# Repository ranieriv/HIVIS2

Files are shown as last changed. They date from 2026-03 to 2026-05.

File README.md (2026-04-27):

# HIVIS Monitor 2.0

Self-hosted indoor air quality and acoustic monitoring system built on ESP32. Designed for schools, offices, and research environments where privacy and data ownership matter.

**Live dashboard:** [https://hvht.net](https://hvht.net)

---

## What it measures

| Metric | Sensor | Notes |
|---|---|---|
| IAQ (Air Quality Index) | BME688 + BSEC2 | 0–500 scale, accuracy 0–3 |
| CO₂ equivalent | BME688 + BSEC2 | ppm |
| VOC (breath VOC) | BME688 + BSEC2 | ppm |
| Temperature | BME688 | °C |
| Humidity | BME688 | % RH |
| Noise level | INMP441 | dB SPL |
| Battery voltage | ADC (GPIO 36) | % + volts |

---

## Architecture

```
┌─────────────────────────────────────────────────────┐
│  ESP32 Device (battery-powered)                     │
│  BME688 · INMP441 · OLED · Button · Buzzer          │
└──────────────────┬──────────────────────────────────┘
                   │ MQTT TLS :8883 · HTTP :8090 (OTA)
                   ▼
┌─────────────────────────────────────────────────────┐
│  Server (Docker)                                    │
│  Mosquitto → Node-RED → InfluxDB → Grafana          │
│  Nginx (https://hvht.net) · OTA server (:8090)      │
└─────────────────────────────────────────────────────┘
```

---

## Hardware

| Component | Part |
|---|---|
| MCU | ESP32 DOIT DevKit V1 |
| Air quality | Bosch BME688 breakout |
| Microphone | INMP441 I2S breakout |
| Display | 0.96" OLED SSD1306 (I2C) |
| Button | Tactile switch (GPIO 4) |
| Buzzer | Passive piezo (GPIO 25) |
| Power | 1S LiPo + USB-C charging module |

KiCad schematic, PCB layout, Gerber files, and BOM are in [`hardware/`](hardware/).

### GPIO Map

| GPIO | Function |
|---|---|
| 21 | I2C SDA (BME688 + OLED) |
| 22 | I2C SCL (BME688 + OLED) |
| 12 | I2S WS — microphone |
| 13 | I2S LR — microphone channel select |
| 14 | I2S SCK — microphone |
| 26 | I2S SD — microphone data |
| 4  | Button (INPUT_PULLUP, active LOW) |
| 25 | Buzzer (LEDC PWM) |
| 36 | Battery ADC (voltage divider ×2.2) |

---

## Firmware

Built with PlatformIO (Arduino framework).

**Dependencies** (auto-installed via `platformio.ini`):
- `boschsensortec/bsec2` — IAQ/CO₂/VOC
- `olikraus/U8g2` — OLED display
- `bblanchon/ArduinoJson`
- `knolleary/PubSubClient` — MQTT
- `tzapu/WiFiManager` — captive portal provisioning

**Build and flash:**
```bash
# Install PlatformIO CLI or use the VS Code extension
pio run --target upload

# Upload LittleFS (config.json, bsec_state.bin)
pio run --target uploadfs
```

**First boot:** the device launches a captive portal (`HIVIS-Setup-XXXX`). Connect and enter your WiFi credentials and MQTT server address.

Device configuration lives in [`data/config.json`](data/config.json). All pin assignments and thresholds are overridable there without reflashing.

---

## Server

The full server stack runs on Docker. A single Linux machine is enough (tested on a Lenovo ThinkPad X200 with Ubuntu).

**Services:**

| Container | Purpose | Port |
|---|---|---|
| `hivis-mosquitto` | MQTT broker (TLS) | 8883 |
| `hivis-nodered` | Data routing + device provisioning | 1880 |
| `hivis-influxdb` | Time-series storage | 8086 |
| `hivis-grafana` | Dashboards | 3000 |
| `hivis-ota` | Firmware update server | 8090 |
| `hivis-nginx` | Public HTTPS dashboard | 80, 443 |
| `hivis-certbot` | Let's Encrypt auto-renewal | — |

**Deploy:**
```bash
cd server
cp mosquitto/config/passwd.example mosquitto/config/passwd  # create credentials
docker compose up -d
```

See [`docs/system-overview.md`](docs/system-overview.md) for the full setup and [`docs/operations-manual.md`](docs/operations-manual.md) for day-to-day operations.

---

## Button functions

| Press | Duration | Action |
|---|---|---|
| Short | < 400 ms | Next display page |
| Double | 2× within 400 ms | Stop alert buzzer |
| Long | 2–5 s | Launch reconfigure portal |
| Factory reset | > 5 s | Wipe NVS credentials and reboot |

---

## Documentation

| File | Contents |
|---|---|
| [`docs/system-overview.md`](docs/system-overview.md) | Architecture, pin map, boot sequence, MQTT topics, server stack |
| [`docs/operations-manual.md`](docs/operations-manual.md) | Quick checks, troubleshooting, deploying firmware, adding devices |
| [`spec/01_device_firmware.md`](spec/01_device_firmware.md) | Firmware module details |
| [`spec/02_provisioning.md`](spec/02_provisioning.md) | First-boot captive portal and MQTT registration flow |
| [`spec/03_ota.md`](spec/03_ota.md) | OTA update system |
| [`spec/04_mqtt_data.md`](spec/04_mqtt_data.md) | MQTT topics and JSON payload schema |
| [`spec/05_server_infrastructure.md`](spec/05_server_infrastructure.md) | Docker stack and Mosquitto ACL |
| [`spec/06_grafana_dashboards.md`](spec/06_grafana_dashboards.md) | Dashboard definitions |

---

## Project structure

```
hivis2/
├── src/            # ESP32 firmware (C++/Arduino)
├── data/           # LittleFS filesystem (config.json)
├── hardware/       # KiCad schematic, PCB, Gerbers, BOM
├── server/         # Docker stack, Mosquitto, Node-RED, Grafana, Nginx
├── docs/           # Operations manual + system overview
├── spec/           # Detailed technical specifications
├── partitions.csv  # ESP32 flash partition table
└── platformio.ini  # Build configuration
```

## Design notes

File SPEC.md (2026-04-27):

# HIVIS Monitor 2.0 — Master Specification

**Version:** 2.0.0  
**Date:** 2026-03-13  
**Author:** Rani  
**Supervisor:** Aaron  
**Institution:** Saskatchewan Polytechnic  
**Showcase:** Applied Research Student Showcase 2026 — May 4, Prairieland Park, Saskatoon

---

## Project Overview

HIVIS Monitor 2.0 is a multi-device, self-hosted indoor air quality and acoustic monitoring system. It is a privacy-respecting alternative to commercial IoT monitors, targeting schools, offices, healthcare, and industrial facilities.

The system consists of:
- One or more ESP32-based sensor devices
- A self-hosted server stack (Lenovo ThinkPad X200, Ubuntu Server)
- A Grafana dashboard accessible via `hvht.net`

The target scale is **up to 10 devices**. The showcase demonstration uses **3 devices**.

---

## Module Spec Files

| File | Contents |
|---|---|
| `spec/01_device_firmware.md` | ESP32 firmware — boot flow, sensors, display, button, buzzer, offline buffering |
| `spec/02_provisioning.md` | First-boot captive portal, NVS credential storage, device registration |
| `spec/03_ota.md` | OTA firmware update system — device polling, server approval, HTTP delivery |
| `spec/04_mqtt_data.md` | MQTT topic structure, payload format, offline backfill |
| `spec/05_server_infrastructure.md` | Docker stack — Mosquitto, Node-RED, InfluxDB 2.x, Grafana |
| `spec/06_grafana_dashboards.md` | Dashboard definitions — per-device, fleet overview, historical |

---

## System Architecture

```
[ESP32 Device(s)]
       │
       │  MQTT over TLS (port 8883)
       ▼
[Mosquitto Broker]  ←── mqtt.hvht.net (DNS-only, no Cloudflare proxy)
       │
       │  Subscribe all hivis/#
       ▼
[Node-RED]  ──────────────────────────────────────────────┐
       │                                                   │
       │  node-red-contrib-influxdb                        │  Device registration
       ▼                                                   │  MAC whitelist check
[InfluxDB 2.x]  (bucket: hivis)                           │  MQTT credential provisioning
       │                                                   │
       ▼
[Grafana]  ──── dashboard.hvht.net (port 3000)
```

All services run in **Docker** on the X200 (`mqttserver`), managed by a single `docker-compose.yml`.

---

## Technology Stack

### Device (ESP32)
| Component | Library / Tool |
|---|---|
| Framework | Arduino (PlatformIO) |
| Sensor (IAQ) | Bosch BSEC2 + BME68x |
| Display | U8g2 |
| JSON | ArduinoJson |
| MQTT | PubSubClient |
| WiFi provisioning | WiFiManager (tzapu) |
| NVS credentials | ESP32 Preferences API |
| OTA update | ESP32 HTTPUpdate (built-in) |
| Offline storage | LittleFS |
| Filesystem | LittleFS |

### Server
| Service | Image |
|---|---|
| MQTT Broker | eclipse-mosquitto:latest |
| Flow engine | nodered/node-red:latest |
| Time-series DB | influxdb:2 |
| Dashboards | grafana/grafana:latest |
| OTA HTTP server | Python `http.server` (simple container or host) |

---

## Network & Access

| Endpoint | Address | Notes |
|---|---|---|
| MQTT (TLS) | `mqtt.hvht.net:8883` | DNS-only Cloudflare, existing cert |
| Grafana | `dashboard.hvht.net:3000` | Tailscale or direct LAN |
| InfluxDB UI | `mqttserver:8086` | LAN only |
| Node-RED UI | `mqttserver:1880` | LAN only |
| OTA server | `mqttserver:8090` | LAN + Tailscale |
| Local IP | `&lt;SERVER_IP&gt;` | X200 static LAN IP |
| Tailscale IP | `&lt;TAILSCALE_IP&gt;` | Remote access |

---

## Device Hardware

| Component | Part | Notes |
|---|---|---|
| MCU | ESP32 DoIt DevKit V1 | Or equivalent 4MB flash module |
| Air quality | Bosch BME688 | I2C, addr 0x77 (119) |
| Microphone | INMP441 | I2S |
| Display | SSD1306 0.96" OLED (or 1.3") | I2C, 128×64 |
| Button | 1× tactile button | GPIO, active LOW |
| Buzzer | Passive piezo + 100Ω resistor | PWM via LEDC |
| Battery | 18650 Li-ion or LiPo | Single cell |
| Charger/Boost | J5019 | 5V regulated output |
| Battery monitor | Voltage divider → GPIO 36 | Taps raw cell voltage |

**Custom PCB:** Targeted for JLCPCB fabrication. Schematic and layout are outside this spec scope.

**Partition table:** A custom `partitions.csv` is required to fit OTA (dual app partitions) + LittleFS on 4MB flash:

```csv
# Name,   Type, SubType, Offset,   Size,    Flags
nvs,      data, nvs,     0x9000,   0x5000,
otadata,  data, ota,     0xe000,   0x2000,
app0,     app,  ota_0,   0x10000,  0x1C0000,
app1,     app,  ota_1,   ,         0x1C0000,
spiffs,   data, spiffs,  ,         0x3F0000,
```

---

## Security Model

| Concern | Approach |
|---|---|
| MQTT transport | TLS (port 8883), `setInsecure()` initially, CA pinning future upgrade |
| Credentials on device | ESP32 NVS (Preferences API), not files |
| Device authorization | MAC address whitelist on server |
| MQTT credentials | Server-provisioned after MAC auth, not user-entered |
| OTA authenticity | Per-device approval flag on server before binary is served |
| Config (non-secret) | Plain-text `config.json` in LittleFS |

---

## Versioning

Firmware uses semantic versioning: `MAJOR.MINOR.PATCH` (e.g. `2.0.0`).  
Version string is defined as a build flag in `platformio.ini`:

```ini
build_flags = -DFIRMWARE_VERSION='"2.0.0"'
```

---

## Key Design Decisions & Rationale

- **NVS over encrypted file:** NVS is hardware-backed, cleaner, and integrates naturally with WiFiManager. SecureVault (AES-128 CBC) from v1 is removed.
- **WiFiManager (tzapu):** Handles captive portal, custom parameters, and NVS storage natively with PlatformIO.
- **Docker for server:** Portability, clean separation of services, easy migration to new hardware.
- **InfluxDB 2.x + Grafana:** Industry standard for IoT time-series. Replaces Node-RED dashboard.
- **Node-RED retained:** Acts as routing glue between MQTT and InfluxDB. Handles device registration logic. Replaceable with Telegraf later if needed.
- **Offline backfill:** Same MQTT topic, `ts_accurate: false` flag, approximate timestamps spaced backwards from reconnect time.
- **1 button:** Short press / long press / double press covers all UI needs.
- **Passive piezo:** Tone control for distinct alert levels.
- **No DS3231 RTC:** Keeps form factor small. Offline timestamps are approximate and flagged.
- **OTA polling:** Device polls on every boot + every 24h. Server has per-device `ota_approved` flag.
- **Group field:** Present in data model from day one. UI support deferred.

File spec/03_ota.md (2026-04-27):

# Module 03 — OTA Firmware Update System

## Overview

Devices poll an HTTP server for firmware updates. The server controls which devices receive an update via a per-device approval flag. Devices never update without server authorization.

---

## OTA Flow

```
Device boots
  → Check NVS: time since last OTA check > otaCheckIntervalH (or first boot)
  → GET http://[ota_server]/ota/version?mac=[device_mac]
  → Server checks:
      - Is this MAC in the whitelist?
      - Is ota_approved = true for this device?
      - Is server version > device FIRMWARE_VERSION?
  → If yes: respond with latest version string
  → Device compares: server_version > FIRMWARE_VERSION?
  → If yes: display "Updating firmware..." on OLED, perform HTTPUpdate
  → On success: reboot into new firmware
  → On failure: log error, continue with current firmware
  → Update NVS ota_last_check timestamp
```

### Check Interval

- On every boot (cold start)
- Every `cfg.otaCheckIntervalH` hours during operation (default 24h)
- Checked via `millis()` comparison against stored `ota_last_check` offset

---

## OTAModule

```cpp
class OTAModule {
public:
    OTAModule(const String& serverUrl, const String& deviceId,
              const String& mac, const String& currentVersion);
    void begin();

    // Call on boot and periodically
    // Returns: true if update was applied (device will reboot)
    bool checkAndUpdate();

private:
    String _serverUrl;  // e.g. "http://<SERVER_IP>:8090"
    String _deviceId;
    String _mac;
    String _currentVersion;

    bool _shouldCheck();
    void _saveLastCheckTime();
};
```

### HTTPUpdate Usage

```cpp
#include <HTTPUpdate.h>

WiFiClient client;
String url = _serverUrl + "/ota/firmware?mac=" + _mac;

httpUpdate.setLedPin(LED_BUILTIN, LOW);
t_httpUpdate_return ret = httpUpdate.update(client, url, _currentVersion);

switch (ret) {
    case HTTP_UPDATE_FAILED:
        Serial.printf("OTA failed: %s\n", httpUpdate.getLastErrorString().c_str());
        break;
    case HTTP_UPDATE_NO_UPDATES:
        Serial.println("OTA: firmware is up to date.");
        break;
    case HTTP_UPDATE_OK:
        Serial.println("OTA: update applied, rebooting.");
        // Device reboots automatically
        break;
}
```

The ESP32 HTTPUpdate library sends the following headers automatically:
- `x-ESP32-STA-MAC` — device MAC (used by server for per-device approval)
- `x-ESP32-free-space` — available flash
- `x-ESP32-sketch-size` — current firmware size

---

## OTA Server

A lightweight Python HTTP server running in Docker (or as a systemd service) on the X200.

### Directory Structure

```
/opt/hivis/ota/
  server.py           ← HTTP server
  firmware/
    latest.bin        ← Current approved firmware binary
    version.txt       ← Current version string, e.g. "2.0.1"
  devices.json        ← Per-device approval flags
```

### devices.json

```json
{
  "devices": {
    "aabbccddeeff": {
      "ota_approved": true,
      "notes": "Classroom unit 1"
    },
    "112233445566": {
      "ota_approved": false,
      "notes": "Test device — not yet approved"
    }
  }
}
```

Setting `ota_approved: true` for a device means it will receive the update on its next check. After a successful update, the operator should set it back to `false` (or leave it `true` for auto-updates — operator's choice).

### server.py — Endpoints

**GET `/ota/version?mac=[mac]`**

Checks whitelist + approval flag. Returns version string or 304.

Response if update available:
```
HTTP 200
Content-Type: text/plain
Body: 2.0.1
```

Response if not approved or up to date:
```
HTTP 304 Not Modified
```

**GET `/ota/firmware?mac=[mac]`**

Validates MAC header from ESP32 HTTPUpdate. If approved, serves `firmware/latest.bin`.

```python
# server.py pseudocode
from http.server import BaseHTTPRequestHandler, HTTPServer
import json, os

DEVICES_FILE = "devices.json"
FIRMWARE_FILE = "firmware/latest.bin"
VERSION_FILE = "firmware/version.txt"

class OTAHandler(BaseHTTPRequestHandler):
    def do_GET(self):
        mac = self._get_mac()
        if not self._is_approved(mac):
            self.send_response(304)
            self.end_headers()
            return

        if self.path.startswith("/ota/version"):
            version = open(VERSION_FILE).read().strip()
            self.send_response(200)
            self.send_header("Content-Type", "text/plain")
            self.end_headers()
            self.wfile.write(version.encode())

        elif self.path.startswith("/ota/firmware"):
            data = open(FIRMWARE_FILE, "rb").read()
            self.send_response(200)
            self.send_header("Content-Type", "application/octet-stream")
            self.send_header("Content-Length", str(len(data)))
            self.end_headers()
            self.wfile.write(data)

    def _get_mac(self):
        # From URL param or ESP32 header
        mac = self.headers.get("x-ESP32-STA-MAC", "").lower().replace(":", "")
        if not mac:
            from urllib.parse import urlparse, parse_qs
            params = parse_qs(urlparse(self.path).query)
            mac = params.get("mac", [""])[0].replace(":", "").lower()
        return mac

    def _is_approved(self, mac):
        with open(DEVICES_FILE) as f:
            data = json.load(f)
        device = data.get("devices", {}).get(mac, {})
        return device.get("ota_approved", False)
```

### Docker Service

```yaml
# In docker-compose.yml
ota-server:
  image: python:3.11-slim
  container_name: hivis-ota
  working_dir: /app
  volumes:
    - /opt/hivis/ota:/app
  command: python server.py
  ports:
    - "8090:8090"
  restart: unless-stopped
```

---

## Deployment Workflow

```
1. Build new firmware in PlatformIO → .pio/build/esp32doit-devkit-v1/firmware.bin
2. Manually flash test device via USB
3. Validate — confirm new version appears on serial / display
4. Copy firmware.bin to /opt/hivis/ota/firmware/latest.bin on server
5. Update /opt/hivis/ota/firmware/version.txt to new version string
6. Edit devices.json: set ota_approved = true for test device
7. Device polls → downloads → reboots → confirm correct version
8. Set ota_approved = true for production devices
9. Devices update on next check (boot or 24h interval)
```

---

## Partition Table Requirement

OTA requires dual app partitions. Use this `partitions.csv` in the project root:

```csv
# Name,   Type, SubType, Offset,   Size,     Flags
nvs,      data, nvs,     0x9000,   0x5000,
otadata,  data, ota,     0xe000,   0x2000,
app0,     app,  ota_0,   0x10000,  0x1C0000,
app1,     app,  ota_1,   ,         0x1C0000,
spiffs,   data, spiffs,  ,         0x3F0000,
```

Reference in `platformio.ini`:
```ini
board_build.partitions = partitions.csv
```

**Note:** The `app0` + `app1` partitions are each 1.75MB. Total firmware binary must stay under 1.75MB. Monitor with `pio run` output. The BSEC library is large — if binary exceeds limit, reduce LittleFS size or optimize.

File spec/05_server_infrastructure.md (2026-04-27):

# Module 05 — Server Infrastructure

## Overview

All server services run in Docker on the Lenovo ThinkPad X200 (`mqttserver`).  
A single `docker-compose.yml` defines the entire stack.

**Host:** Ubuntu Server, 4GB RAM  
**Static LAN IP:** `<SERVER_IP>`  
**Tailscale IP:** `<TAILSCALE_IP>`  
**External domain:** `mqtt.hvht.net` (Cloudflare DNS-only, no proxy)

---

## Services

| Service | Container | Port (host) | Purpose |
|---|---|---|---|
| Mosquitto | `hivis-mosquitto` | 8883 | MQTT broker (TLS) |
| Node-RED | `hivis-nodered` | 1880 | MQTT → InfluxDB routing + registration |
| InfluxDB 2.x | `hivis-influxdb` | 8086 | Time-series storage |
| Grafana | `hivis-grafana` | 3000 | Dashboards (LAN only) |
| OTA Server | `hivis-ota` | 8090 | Firmware delivery |
| Nginx | `hivis-nginx` | 80, 443 | Public website (https://hvht.net) + InfluxDB proxy |
| Certbot | `hivis-certbot` | — | Let's Encrypt SSL cert auto-renewal |

---

## docker-compose.yml

```yaml
version: "3.8"

services:

  mosquitto:
    image: eclipse-mosquitto:latest
    container_name: hivis-mosquitto
    restart: unless-stopped
    ports:
      - "8883:8883"
    volumes:
      - ./mosquitto/config:/mosquitto/config
      - ./mosquitto/data:/mosquitto/data
      - ./mosquitto/log:/mosquitto/log
      - ./mosquitto/certs:/mosquitto/certs
    networks:
      - hivis-net

  nodered:
    image: nodered/node-red:latest
    container_name: hivis-nodered
    restart: unless-stopped
    ports:
      - "1880:1880"
    volumes:
      - nodered-data:/data
    depends_on:
      - mosquitto
      - influxdb
    environment:
      - TZ=America/Regina
    networks:
      - hivis-net

  influxdb:
    image: influxdb:2
    container_name: hivis-influxdb
    restart: unless-stopped
    ports:
      - "8086:8086"
    volumes:
      - influxdb-data:/var/lib/influxdb2
      - influxdb-config:/etc/influxdb2
    environment:
      - DOCKER_INFLUXDB_INIT_MODE=setup
      - DOCKER_INFLUXDB_INIT_USERNAME=admin
      - DOCKER_INFLUXDB_INIT_PASSWORD=REPLACE_WITH_SECURE_PASSWORD
      - DOCKER_INFLUXDB_INIT_ORG=hivis
      - DOCKER_INFLUXDB_INIT_BUCKET=hivis
      - DOCKER_INFLUXDB_INIT_ADMIN_TOKEN=REPLACE_WITH_GENERATED_TOKEN
    networks:
      - hivis-net

  grafana:
    image: grafana/grafana:latest
    container_name: hivis-grafana
    restart: unless-stopped
    ports:
      - "3000:3000"
    volumes:
      - grafana-data:/var/lib/grafana
      - ./grafana/provisioning:/etc/grafana/provisioning
    environment:
      - GF_SECURITY_ADMIN_PASSWORD=REPLACE_WITH_SECURE_PASSWORD
      - GF_USERS_ALLOW_SIGN_UP=false
    depends_on:
      - influxdb
    networks:
      - hivis-net

  ota-server:
    image: python:3.11-slim
    container_name: hivis-ota
    restart: unless-stopped
    working_dir: /app
    volumes:
      - /opt/hivis/ota:/app
    command: python server.py
    ports:
      - "8090:8090"
    networks:
      - hivis-net

  nginx:
    image: nginx:alpine
    container_name: hivis-nginx
    restart: unless-stopped
    ports:
      - "80:80"
      - "443:443"
    volumes:
      - ./website:/usr/share/nginx/html:ro
      - ./nginx:/etc/nginx/conf.d:ro
      - certbot-conf:/etc/letsencrypt:ro
      - certbot-www:/var/www/certbot:ro
    depends_on:
      - influxdb
    networks:
      - hivis-net

  certbot:
    image: certbot/certbot:latest
    container_name: hivis-certbot
    restart: unless-stopped
    volumes:
      - certbot-conf:/etc/letsencrypt
      - certbot-www:/var/www/certbot
    entrypoint: "/bin/sh -c 'trap exit TERM; while :; do certbot renew --quiet; sleep 12h & wait $${!}; done;'"
    networks:
      - hivis-net

networks:
  hivis-net:
    driver: bridge

volumes:
  nodered-data:
  influxdb-data:
  influxdb-config:
  grafana-data:
  certbot-conf:
  certbot-www:
```

**Important:** Replace all `REPLACE_WITH_*` placeholders before deploying. See `docs/credentials.md` for the running deployment's values.

---

## Mosquitto Configuration

File: `./mosquitto/config/mosquitto.conf`

```conf
listener 8883
protocol mqtt

# TLS
cafile /mosquitto/certs/ca.crt
certfile /mosquitto/certs/server.crt
keyfile /mosquitto/certs/server.key
require_certificate false

# Auth
allow_anonymous false
password_file /mosquitto/config/passwd
acl_file /mosquitto/config/acl

# Persistence
persistence true
persistence_location /mosquitto/data/

# Logging
log_dest file /mosquitto/log/mosquitto.log
log_type error
log_type warning
log_type notice
```

**TLS certs:** Existing self-signed cert for `mqtt.hvht.net` (already in use in v1). Mount into container at `/mosquitto/certs/`.

**Password file:** Managed with `mosquitto_passwd`. Each device gets its own user. Node-RED gets a `nodered_bridge` user with full access.

```bash
# Create password file inside container
docker exec -it hivis-mosquitto mosquitto_passwd -c /mosquitto/config/passwd nodered_bridge
docker exec -it hivis-mosquitto mosquitto_passwd /mosquitto/config/passwd device_aabbccddeeff
```

**ACL file:** `./mosquitto/config/acl` — see Module 04 for content.

---

## Node-RED Flows

Install required nodes in Node-RED:
```
node-red-contrib-influxdb
```

### Flow 1: Sensor Data → InfluxDB

```
[MQTT in: hivis/+/data]
  → [JSON parse]
  → [Function: build InfluxDB point]
  → [InfluxDB out: hivis bucket]
```

InfluxDB point builder function:
```javascript
const payload = msg.payload;
const isBackfill = payload.backfill === true;

// Use payload timestamp if backfill, otherwise now
const timestamp = isBackfill && payload.ts > 0
    ? new Date(payload.ts * 1000)
    : new Date();

msg.payload = [
    {
        measurement: "air_quality",
        tags: {
            device_id:   payload.device_id,
            device_name: payload.device_name,
            group:       payload.group || "default",
            backfill:    String(isBackfill)
        },
        fields: {
            temp:     payload.temp,
            hum:      payload.hum,
            iaq:      payload.iaq,
            co2:      payload.co2,
            bvoc:     payload.bvoc,
            db:       payload.db,
            bat_pct:  payload.bat_pct,
            bat_mv:   payload.bat_mv,
            rssi:     payload.rssi,
            accuracy: payload.accuracy
        },
        timestamp: timestamp
    }
];

return msg;
```

### Flow 2: Device Registration

```
[MQTT in: hivis/register]
  → [JSON parse]
  → [Function: check whitelist]
  → [Branch: approved / rejected]
  → (approved) [Function: generate credentials]
               [MQTT out: hivis/provision/[mac]]
               [File: update devices.json]
  → (rejected) [MQTT out: hivis/provision/[mac]] (rejected payload)
```

Whitelist check function:
```javascript
const reg = msg.payload;
const mac = reg.mac.toLowerCase().replace(/:/g, "");
const fs = require("fs");
const whitelist = JSON.parse(fs.readFileSync("/data/whitelist.json", "utf8"));

const device = whitelist.devices.find(d =>
    d.mac.toLowerCase().replace(/:/g, "") === mac
);

if (device && device.authorized) {
    msg.approved = true;
    msg.mac = mac;
    msg.device_name = reg.device_name;
} else {
    msg.approved = false;
    msg.mac = mac;
}
return msg;
```

Credential generation function:
```javascript
// Generate a secure random password
const chars = "ABCDEFGHIJKLMNOPQRSTUVWXYZabcdefghijklmnopqrstuvwxyz0123456789";
let pass = "";
for (let i = 0; i < 20; i++) {
    pass += chars[Math.floor(Math.random() * chars.length)];
}

const user = "device_" + msg.mac;
const deviceId = "hivis-" + msg.mac;

msg.topic = "hivis/provision/" + msg.mac;
msg.payload = JSON.stringify({
    status: "approved",
    mqtt_user: user,
    mqtt_pass: pass,
    device_id: deviceId
});
msg.retain = true;

// Store credentials for reference (Node-RED context or file)
// Operator must also add user to Mosquitto passwd manually or via exec node
return msg;
```

**Note:** Automatically adding users to Mosquitto's passwd file from Node-RED requires a shell `exec` node running `mosquitto_passwd`. This is acceptable for a managed deployment. The operator can also do this step manually.

### Flow 3: System Status

```
[MQTT in: hivis/+/data]
  → [Function: extract system fields]
  → [InfluxDB out: hivis bucket, measurement: "device_status"]
```

System fields to track separately: `bat_pct`, `bat_mv`, `rssi`, `accuracy`, `fw_version`.

---

## InfluxDB 2.x

**Organization:** `hivis`  
**Bucket:** `hivis`  
**Retention:** Unlimited (or set 90 days for auto-cleanup)

Measurements:
- `air_quality` — all sensor readings
- `device_status` — system fields (battery, RSSI, accuracy)

Tags on all measurements:
- `device_id`
- `device_name`
- `group`
- `backfill`

---

## File Structure on Host

```
/opt/hivis/
  docker-compose.yml
  mosquitto/
    config/
      mosquitto.conf
      passwd
      acl
    certs/
      ca.crt           ← existing cert
      server.crt       ← existing cert
      server.key       ← existing key
    data/
    log/
  grafana/
    provisioning/
      datasources/
        influxdb.yml
  ota/
    server.py
    firmware/
      latest.bin
      version.txt
    devices.json
  server/
    whitelist.json
```

---

## Grafana Data Source Provisioning

File: `./grafana/provisioning/datasources/influxdb.yml`

```yaml
apiVersion: 1

datasources:
  - name: InfluxDB-hivis
    type: influxdb
    access: proxy
    url: http://influxdb:8086
    jsonData:
      version: Flux
      organization: hivis
      defaultBucket: hivis
      tlsSkipVerify: true
    secureJsonData:
      token: REPLACE_WITH_INFLUXDB_TOKEN
    isDefault: true
```

---

## Security Notes

- All services are on an internal Docker bridge network (`hivis-net`). Only ports listed are exposed to the host.
- **Internet-facing ports:** 80 (HTTP→redirect), 443 (HTTPS dashboard), 8883 (MQTT TLS for devices). All others are LAN only.
- Grafana (:3000) and Node-RED (:1880) must NOT be exposed to the internet — Node-RED allows arbitrary code execution.
- InfluxDB (:8086) is accessed by the website exclusively through the Nginx `/api/v2/query` proxy. The website uses a **read-only token** — the admin token is never exposed publicly.
- Mosquitto `passwd` file must be owned by root, permissions `644`. If sudo operations reset it to `rwx------`, Mosquitto will crash with exit code 13. Fix: `chmod 644` via a root Docker exec.
- The OTA server mounts the Docker socket (`/var/run/docker.sock`) to call `mosquitto_passwd` during provisioning — this gives it full Docker host control. Acceptable for this deployment; restrict in higher-security environments.
- Existing Tailscale + fail2ban setup on the X200 continues to apply.
- Replace all `REPLACE_WITH_*` placeholders and use unique passwords before deploying.

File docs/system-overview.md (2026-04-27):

# HIVIS Monitor 2.0 — System Documentation

**Version:** 2.0.2
**Hardware:** ESP32 DOIT DevKit V1 + BME688 + INMP441
**Server:** Lenovo ThinkPad X200 · Ubuntu · &lt;SERVER_IP&gt;
**Public website:** https://hvht.net

---

## 1. Architecture Overview

```
┌─────────────────────────────────────────────────────────────┐
│  ESP32 Device (Battery-powered, indoor)                     │
│  BME688 (IAQ/CO2/VOC/Temp/Hum) + INMP441 (Noise) + OLED   │
└──────────────────┬──────────────────────────────────────────┘
                   │ MQTT TLS :8883
                   │ HTTP     :8090 (OTA)
                   ▼
┌─────────────────────────────────────────────────────────────┐
│  Server — &lt;SERVER_IP&gt; / mqtt.hvht.net                      │
│  ┌──────────────┐  ┌──────────────┐  ┌──────────────────┐  │
│  │  Mosquitto   │  │   Node-RED   │  │    InfluxDB 2    │  │
│  │  :8883 TLS   │→ │  :1880       │→ │    :8086         │  │
│  └──────────────┘  └──────────────┘  └────────┬─────────┘  │
│  ┌──────────────┐                    ┌─────────▼─────────┐  │
│  │  OTA Server  │                    │    Grafana        │  │
│  │  :8090       │                    │    :3000          │  │
│  └──────────────┘                    └───────────────────┘  │
│  ┌──────────────────────────────────────────────────────┐   │
│  │  Nginx (HTTPS :443 / HTTP :80 → redirect)            │   │
│  │  Serves https://hvht.net — static dashboard +        │   │
│  │  proxies /api/v2/query → InfluxDB (internal only)    │   │
│  └──────────────────────────────────────────────────────┘   │
└─────────────────────────────────────────────────────────────┘
                   ▲
                   │ HTTPS :443
         Browser (any network) — https://hvht.net
```

---

## 2. Server Stack

| Service | Image | Port | Purpose |
|---|---|---|---|
| `hivis-mosquitto` | eclipse-mosquitto:latest | **8883** | MQTT broker (TLS only) |
| `hivis-nodered` | nodered/node-red:latest | **1880** | Data routing & provisioning |
| `hivis-influxdb` | influxdb:2 | **8086** | Time-series database |
| `hivis-grafana` | grafana/grafana:latest | **3000** | Dashboards (LAN only) |
| `hivis-ota` | python:3.11-slim | **8090** | Firmware update server |
| `hivis-nginx` | nginx:alpine | **80, 443** | Public website (https://hvht.net) + InfluxDB proxy |
| `hivis-certbot` | certbot/certbot:latest | — | Let's Encrypt cert auto-renewal (12h loop) |

**Manage all services:**
```bash
cd /opt/hivis
docker compose ps           # status
docker compose restart      # restart all
docker compose logs -f      # live logs
```

---

## 3. Device Boot Sequence

```
1. Load config.json from LittleFS
2. Init hardware (I2C 21/22, OLED, buzzer, button)
3. Show splash, load NVS credentials
4. If no WiFi/server saved → Captive portal (HIVIS-Setup-XXXX)
5. Init BME688 (I2C 0x77) + INMP441 microphone
6. Connect WiFi (15s timeout)
7. Sync NTP (pool.ntp.org / time.nist.gov)
8. If not provisioned → Register via MQTT bootstrap
9. Connect MQTT with provisioned credentials
10. Flush offline buffer (if any)
11. Check OTA (every 24h)
12. Main loop: read sensors → display → publish every 3s
```

---

## 4. Device Provisioning Flow

```
Device (unprovisioned)
  │ CONNECT  user=hivis_bootstrap  pass=<see credentials.md>
  ▼
Mosquitto ──→ Node-RED
  │              │ Check whitelist.json
  │              │ Generate random 20-char password
  │              │ Call POST http://ota-server:8090/provision
  │              │   └─ mosquitto_passwd -b passwd device_XXXX PASS
  │              │   └─ Append ACL entry
  │              │   └─ SIGHUP Mosquitto
  │              │ Publish to hivis/provision/[mac] (retain=true)
  ◄─────────────────────────────────────────────────────────
Device receives: {"status":"approved","mqtt_user":"device_XXXX",
                  "mqtt_pass":"...","device_id":"hivis-XXXX"}
  │ Save to NVS
  │ CONNECT  user=device_XXXX  pass=...
  ▼
Mosquitto: authenticated ✓
```

---

## 5. MQTT Topics

| Topic | Direction | Purpose |
|---|---|---|
| `hivis/hivis-[mac]/data` | Device → Server | Sensor data (3s interval) |
| `hivis/register` | Device → Server | Registration request |
| `hivis/provision/[mac]` | Server → Device | Provisioning response (retained) |

**Sensor payload (JSON):**
```json
{
  "device_id":   "hivis-4cc382c32764",
  "device_name": "Room 101",
  "ts":          1710518400,
  "ts_accurate": true,
  "fw_version":  "2.0.1",
  "temp":        22.5,
  "hum":         45.3,
  "iaq":         75.2,
  "co2":         412,
  "bvoc":        0.52,
  "db":          65.3,
  "bat_pct":     85,
  "bat_mv":      3850,
  "rssi":        -45,
  "accuracy":    3,
  "backfill":    false
}
```

**IAQ Accuracy (BSEC2):**
| Value | Meaning |
|---|---|
| 0 | Calibrating — values unreliable (~30 min on first boot) |
| 1 | Low accuracy |
| 2 | Medium accuracy |
| 3 | High accuracy — fully calibrated |

---

## 6. MQTT Users & Access Control

| User | Password | Access |
|---|---|---|
| `hivis_bootstrap` | *(see docs/credentials.md)* | Write hivis/register, Read hivis/provision/+ |
| `nodered_bridge` | *(encrypted in Node-RED)* | Read/Write hivis/# |
| `device_[mac]` | Auto-generated | Write hivis/hivis-[mac]/#, Read hivis/provision/[mac] |

**Add a new device to whitelist** (required before registration is approved):
```bash
# Whitelist lives inside the Node-RED container — edit it directly:
ssh mqttadmin@&lt;SERVER_IP&gt; "docker exec hivis-nodered nano /data/whitelist.json"
# Add to the "devices" array:
# { "mac": "AA:BB:CC:DD:EE:FF", "authorized": true, "group": "saskpoly", "notes": "Room X" }
```

---

## 7. OTA Update Process

**OTA server endpoints:**
```
GET  http://mqtt.hvht.net:8090/ota/version?mac=[mac]   → "2.0.1"
GET  http://mqtt.hvht.net:8090/ota/firmware?mac=[mac]  → latest.bin
POST http://ota-server:8090/provision                  → Add Mosquitto user
```

**Deploy a new firmware version:**
```bash
# 1. Bump version in platformio.ini: -DFIRMWARE_VERSION='"2.0.2"'
# 2. Build:
pio run
# 3. Upload binary:
scp .pio/build/esp32doit-devkit-v1/firmware.bin mqttadmin@&lt;SERVER_IP&gt;:/opt/hivis/ota/firmware/latest.bin
# 4. Update version file:
ssh mqttadmin@&lt;SERVER_IP&gt; "echo '2.0.2' > /opt/hivis/ota/firmware/version.txt"
```

Device checks OTA on every boot (if last check > 24h ago). Update applies automatically and device reboots.

---

## 8. Hardware Pin Assignments

| Component | Pin | Notes |
|---|-----|---|
| I2C SDA | GPIO 21 | BME688 + OLED |
| I2C SCL | GPIO 22 | BME688 + OLED |
| BME688 | I2C 0x77 | IAQ/CO2/VOC/Temp/Hum |
| INMP441 WS | GPIO 12 | Microphone clock |
| INMP441 SCK | GPIO 14 | Microphone bit clock |
| INMP441 SD | GPIO 26 | Microphone data |
| INMP441 LR | GPIO 13 | Left/Right select |
| Button | GPIO 4 | Short/Long/Double/Factory reset |
| Buzzer | GPIO 25 | LEDC PWM, channel 0 |
| Battery ADC | GPIO 36 | Voltage divider ×2.2 |

---

## 9. Button Functions

| Press | Duration | Action |
|---|---|---|
| Short | < 400ms | Next display page |
| Double | 2× < 400ms apart | Stop alert buzzer |
| Long | > 2s | Launch reconfigure portal |
| Factory reset | > 5s | Wipe NVS → full reboot |

---

## 10. Flash Partition Layout

| Partition | Offset | Size | Contents |
|---|---|---|---|
| nvs | 0x9000 | 20 KB | WiFi creds, MQTT creds, device ID |
| otadata | 0xE000 | 8 KB | Active OTA slot tracker |
| app0 | 0x10000 | 1.75 MB | Primary firmware |
| app1 | 0x1D0000 | 1.75 MB | OTA update slot |
| spiffs | 0x390000 | 448 KB | LittleFS: config.json, bsec_state.bin |

**Erase NVS only** (wipes credentials, keeps firmware):
```bash
python -m esptool --port COM7 erase_region 0x9000 0x5000
```

---

## 11. Grafana Dashboards

| Dashboard | URL path | Purpose |
|---|---|---|
| Fleet Overview | `/d/hivis-fleet` | All devices — status table, IAQ comparison, battery |
| Per Device | `/d/hivis-perdevice` | Single device — live gauges + history |
| Historical | `/d/hivis-historical` | 7-day trends, backfill annotation |

Login: `admin` / *(see docs/credentials.md)*
URL: `http://&lt;SERVER_IP&gt;:3000`

---

## 12. Public Website (https://hvht.net)

The live dashboard is served by Nginx from `server/website/index.html`.

| Item | Detail |
|---|---|
| URL | https://hvht.net |
| Source file | `server/website/index.html` |
| SSL cert | Let's Encrypt via certbot — expires 2026-07-12, auto-renews |
| InfluxDB access | Read-only token; queries proxied through `/api/v2/query` (InfluxDB port 8086 is never exposed externally) |
| Nginx configs | `server/nginx/hivis.conf` (production HTTPS), `server/nginx/http-only.conf` (bootstrap only), `server/nginx/local.conf` (local dev) |
| Auto-refresh | Every 10 seconds |

**Update the dashboard:**
```bash
# Edit server/website/index.html locally, then copy to server:
scp server/website/index.html mqttadmin@mqttserver:/opt/hivis/website/
# No Nginx restart needed — served directly from volume mount.
```

---

## 13. Key File Locations

### Server (`/opt/hivis/`)
```
/opt/hivis/
├── docker-compose.yml
├── mosquitto/
│   ├── config/
│   │   ├── mosquitto.conf
│   │   ├── passwd          ← Mosquitto user hashes (chmod 644, owned root)
│   │   └── acl             ← Topic access control
│   ├── certs/              ← TLS cert (mqtt.hvht.net, self-signed)
│   └── log/mosquitto.log
├── website/
│   └── index.html          ← Public dashboard (https://hvht.net)
├── nginx/
│   ├── hivis.conf          ← Production HTTPS config (active)
│   ├── http-only.conf.disabled  ← Bootstrap config (inactive)
│   └── local.conf.disabled ← Local dev config (inactive)
└── ota/
    ├── server.py
    ├── devices.json        ← OTA-approved MACs
    └── firmware/
        ├── latest.bin
        └── version.txt
```

**Docker volumes (managed by Docker):**
```
hivis_certbot-conf   ← /etc/letsencrypt (Let's Encrypt cert files)
hivis_certbot-www    ← /var/www/certbot (ACME webroot)
hivis_nodered-data   ← Node-RED flows and config
hivis_influxdb-data  ← InfluxDB time-series data
hivis_influxdb-config
hivis_grafana-data
```

**Node-RED container** (`hivis-nodered:/data/`):
```
/data/
└── whitelist.json          ← Registration whitelist (MAC → authorized)
```

### Device (LittleFS)
```
/littlefs/
├── config.json             ← All tunable parameters
├── bsec_state.bin          ← BSEC2 calibration (auto-saved every 6h)
└── offline_buffer.ndjson   ← Offline sensor records (max 500)
```

### Device (NVS — namespace "hivis")
| Key | Content |
|-----|---|
| `mqtt_server` | `mqtt.hvht.net` |
| `mqtt_user` | `device_[mac]` |
| `mqtt_pass` | Auto-generated password |
| `device_id` | `hivis-[mac]` |
| `device_name` | Human-readable name |
| `provisioned` | 1 (set after successful registration) |
| `ota_last_chk` | Unix timestamp of last OTA check |

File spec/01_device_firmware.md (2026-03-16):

# Module 01 — Device Firmware

## Overview

The ESP32 firmware is structured as a set of independent modules, each in its own class. `main.cpp` owns the lifecycle and the main loop. All tunable parameters live in `config.json` (plain text, LittleFS). All credentials live in NVS (Preferences API).

---

## Module Structure

```
src/
  main.cpp
  BME688Module.cpp
  MicModule.cpp
  DisplayModule.cpp
  MqttModule.cpp
  ButtonModule.cpp
  BuzzerModule.cpp
  OTAModule.cpp
  PortalModule.cpp
  ConfigHandler.cpp     (or remain as inline in ConfigHandler.h)

include/
  BME688Module.h
  MicModule.h
  DisplayModule.h
  MqttModule.h
  ButtonModule.h
  BuzzerModule.h
  OTAModule.h
  PortalModule.h
  ConfigHandler.h

data/
  config.json           (plain text, uploaded to LittleFS)
```

**Removed from v1:** `SecureVault.h/.cpp`, `credentials.json` (encrypted file). Replaced by NVS.

---

## ConfigHandler

### config.json (plain text, LittleFS)

```json
{
  "mqtt": {
    "port": 8883,
    "topic_prefix": "hivis/sensors",
    "interval_ms": 3000,
    "keepalive_s": 60
  },
  "bme": {
    "addr": 119,
    "iaq_warn": 100,
    "iaq_alert": 200,
    "bsec_save_interval_h": 6
  },
  "mic": {
    "pin_ws": 12,
    "pin_sck": 14,
    "pin_sd": 26,
    "pin_lr": 13,
    "cal": 115.0
  },
  "misc": {
    "refresh_ms": 1000,
    "battery_pin": 36,
    "battery_min_mv": 330,
    "battery_max_mv": 420,
    "battery_multiplier": 2.2
  },
  "ota": {
    "check_interval_h": 24
  },
  "display": {
    "timeout_ms": 10000
  },
  "buzzer": {
    "enabled": true,
    "pin": 25
  },
  "button": {
    "pin": 0,
    "long_press_ms": 2000,
    "double_press_ms": 400
  }
}
```

### DeviceConfig struct additions vs v1

```cpp
struct DeviceConfig {
    // --- NVS (loaded separately, not from config.json) ---
    String wifiSSID;
    String wifiPass;
    String mqttServer;
    String mqttUser;
    String mqttPass;
    String deviceName;    // Human-readable, set via portal
    String deviceId;      // MAC-derived, e.g. "hivis-a1b2c3d4"

    // --- From config.json ---
    int    mqttPort;
    String mqttTopicPrefix;
    int    mqttIntervalMs;
    int    mqttKeepaliveS;

    uint8_t bmeAddr;
    float   iaqWarn;
    float   iaqAlert;
    int     bsecSaveIntervalH;

    int    micWS, micSCK, micSD, micLR;
    double micCal;

    int   refreshMs;
    int   batteryPin;
    int   batteryMinMv;
    int   batteryMaxMv;
    float batteryMultiplier;

    int   otaCheckIntervalH;    // How often to poll OTA server
    int   displayTimeoutMs;     // Screen auto-off delay after wake

    bool  buzzerEnabled;
    int   buzzerPin;

    int   buttonPin;
    int   longPressMs;
    int   doublePressMs;
};
```

NVS keys (Preferences namespace `"hivis"`):

| Key | Value |
|-----|---|
| `wifi_ssid` | WiFi SSID |
| `wifi_pass` | WiFi password |
| `mqtt_server` | MQTT server address |
| `mqtt_user` | MQTT username (provisioned by server) |
| `mqtt_pass` | MQTT password (provisioned by server) |
| `device_name` | Human-readable name (set via portal) |
| `provisioned` | `1` if server has provisioned MQTT credentials |
| `ota_last_check` | Unix timestamp of last OTA check (millis-based approximation) |

---

## Boot Flow

### First Boot (NVS empty)

```
Power on
  → Mount LittleFS
  → Load config.json
  → Init hardware (I2C, OLED, buzzer, button)
  → Show splash screen
  → NVS check: no wifi_ssid found
  → Launch PortalModule (captive portal)
      User enters: WiFi SSID, WiFi password, device name, server address
  → Save to NVS
  → Connect to WiFi
  → Send registration request to server (MAC + device name)
  → Server responds with MQTT credentials
  → Save MQTT credentials to NVS, set provisioned = 1
  → Double-beep (system ready)
  → Enter main loop
```

### Every Subsequent Boot

```
Power on
  → Mount LittleFS
  → Load config.json
  → Load NVS credentials
  → Init hardware
  → Show splash screen
  → Load BSEC state from LittleFS (/bsec_state.bin)
  → Check OTA (if interval elapsed or first boot of day)
  → Connect to WiFi
      Success → online mode
      Fail    → offline mode
  → Double-beep (system ready)
  → Enter main loop
```

### Long Press During Boot or Operation
Launches captive portal to reconfigure WiFi / device name / server address.  
Does NOT wipe MQTT credentials unless server re-provisions.

### Factory Reset
Long press > 5 seconds → wipe entire NVS namespace `"hivis"` → reboot → first boot flow.

---

## Main Loop

**Refresh interval:** `cfg.refreshMs` (default 1000ms)  
**MQTT publish interval:** `cfg.mqttIntervalMs` (default 3000ms)

Each iteration:
1. `bme->update()` — BSEC tick
2. If `refreshMs` elapsed:
   - Read mic (`mic->readDB()`)
   - Read battery ADC (16-sample average, hysteresis 2%, values only decrease)
   - Bundle `DisplayData` struct
   - `button->update()` — process button state machine
   - `buzzer->update()` — handle tone timers
   - If screen is on: `oled->update(data)`
   - Check alert thresholds → trigger buzzer if needed
   - If online and `mqttIntervalMs` elapsed: `mqtt->publish(data)`
   - If offline: `buffer->store(data)`
3. If just reconnected to WiFi: `buffer->flush()` (backfill publish)
4. `delay(1)`

---

## Display Module

### Screen Behavior
- Screen is **OFF by default** to save battery
- Wakes on: short button press, alert threshold crossed, error condition
- Auto-off after `cfg.displayTimeoutMs` (default 10 seconds) of inactivity
- While screen is off, sensor readings and MQTT publishing continue normally

### Display Pages (cycle with short press)

**Page 1 — Air Quality**
```
Temp: XX.X°C   Hum: XX%  [WiFi][Bat]
─────────────────────────────────────
  [IAQ large font]   IAQ
                     CO2: XXXX ppm
Noise: XX.X dB
─────────────────────────────────────
Status: OK | Acc: X
```

**Page 2 — Environment**
```
[Device Name]           [WiFi][Bat]
─────────────────────────────────────
  Temp:  XX.X °C
  Hum:   XX.X %
  BVOC:  X.XX ppm
─────────────────────────────────────
Status: OK | Acc: X
```

**Page 3 — System**
```
[Device Name]           [WiFi][Bat]
─────────────────────────────────────
  WiFi:   [SSID] XX dBm
  Bat:    XX% (X.XXV)
  Server: [connected/offline]
  Acc:    X/3
─────────────────────────────────────
FW: 2.0.0
```

### IAQ Status Footer (Page 1)
| Condition | Message |
|---|---|
| `accuracy == 0` | `Calibrating BSEC...` |
| `iaq >= iaqAlert` | `!! POOR AIR QUALITY !!` |
| `iaq >= iaqWarn` | `ALERT: VENTILATE REC` |
| default | `Status: OK | Acc: X` |

---

## Button Module

Single button, active LOW (internal pull-up).

| Gesture | Action |
|---|---|
| Short press (< `longPressMs`) | Wake screen / cycle to next display page |
| Double press (two presses < `doublePressMs` apart) | Acknowledge alert / silence buzzer |
| Long press (> `longPressMs`, < 5s) | Open settings portal (captive portal) |
| Long press (> 5s) | Factory reset (wipe NVS, reboot) |

**ButtonModule API:**
```cpp
class ButtonModule {
public:
    ButtonModule(int pin, int longPressMs, int doublePressMs);
    void begin();
    void update();  // Call every loop iteration

    bool shortPressed();    // Consumed on read
    bool doublePressed();   // Consumed on read
    bool longPressed();     // Consumed on read
    bool factoryReset();    // Consumed on read
};
```

---

## Buzzer Module

Passive piezo on PWM pin (`cfg.buzzerPin`, default GPIO 25). Uses ESP32 LEDC.

| Event | Tone Pattern | Description |
|---|---|---|
| Button press / menu nav | Single short beep 1000Hz 50ms | UI feedback |
| System ready | Two beeps 1200Hz 100ms, 100ms gap | Boot complete |
| WiFi connected | Ascending two-tone (800→1200Hz) | Connection OK |
| IAQ warning | Slow intermittent 800Hz, 500ms on / 1s off | Warning level |
| IAQ danger | Fast urgent 1200Hz, 200ms on / 200ms off | Danger level |
| Alert silenced | Descending tone 1000→600Hz 300ms | Acknowledged |
| Error | Three rapid low beeps 400Hz | System error |

**BuzzerModule API:**
```cpp
class BuzzerModule {
public:
    BuzzerModule(int pin);
    void begin();
    void update();          // Call every loop — handles non-blocking timers

    void beepShort();
    void beepReady();
    void beepConnected();
    void startWarning();    // Continuous until stopAlert()
    void startDanger();     // Continuous until stopAlert()
    void stopAlert();
    void beepError();

    bool isMuted();
    void setMuted(bool muted);  // Permanent silence from settings

private:
    bool _muted;
    // Internal state machine for continuous tones
};
```

---

## Offline Buffer Module

When WiFi is unavailable, readings are stored to LittleFS.

### Storage Format

File: `/offline_buffer.json` (append-style JSON array or newline-delimited JSON)

Each record:
```json
{
  "ts": 0,
  "ts_accurate": false,
  "temp": 21.5,
  "hum": 45.2,
  "iaq": 82.3,
  "co2": 654,
  "bvoc": 0.51,
  "db": 48.2,
  "bat": 87,
  "acc": 3
}
```

`ts` is set to `0` during offline period (no NTP). On reconnect, approximate timestamps are calculated backwards from `now()` using the stored `cfg.mqttIntervalMs` interval.

### Backfill on Reconnect

On WiFi reconnect:
1. Read `/offline_buffer.json`
2. Get current NTP time
3. Count records, assign timestamps backwards: `ts = now - (index * intervalMs / 1000)`
4. Publish each record to MQTT with `"backfill": true` in payload
5. Delete `/offline_buffer.json` after successful flush

### Storage Limits

Maximum buffer size: 500 records (configurable). If full, oldest records are dropped (ring buffer behavior). A warning is logged to serial.

---

## Battery Monitor

- 16-sample ADC averaging on `cfg.batteryPin` (GPIO 36)
- Voltage divider correction: `voltage = (raw / 4095.0) * 3.3 * cfg.batteryMultiplier`
- Percentage: `map(constrain(voltage*100, minMv, maxMv), minMv, maxMv, 0, 100)`
- Hysteresis: reported percentage only decreases (never increases by less than 2%)
- Both percentage and voltage reported in DisplayData and MQTT payload

---

## platformio.ini

```ini
[env:esp32doit-devkit-v1]
platform = espressif32
board = esp32doit-devkit-v1
framework = arduino
monitor_speed = 115200
board_build.filesystem = littlefs
board_build.partitions = partitions.csv

lib_compat_mode = strict
lib_ignore = WiFiNINA, WiFiNINA_-_Adafruit_Fork

lib_deps =
    boschsensortec/bsec2 @ ^1.10.2610
    boschsensortec/BME68x Sensor Library @ ^1.2.40408
    olikraus/U8g2 @ ^2.35.19
    bblanchon/ArduinoJson
    knolleary/PubSubClient @ ^2.8.0
    tzapu/WiFiManager @ ^2.0.17

build_flags =
    -L .pio/libdeps/esp32doit-devkit-v1/bsec2/src/esp32
    -lalgobsec
    -DFIRMWARE_VERSION='"2.0.0"'
```

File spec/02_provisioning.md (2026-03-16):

# Module 02 — Provisioning

## Overview

Device provisioning happens in two phases:
1. **WiFi + identity setup** via captive portal (user-initiated, first boot or long press)
2. **MQTT credential provisioning** by the server after MAC authorization (automatic)

Credentials are stored in ESP32 NVS (Preferences API), never in files.

---

## PortalModule

Wraps the `tzapu/WiFiManager` library. Handles first boot and reconfigure flows.

### Library

```
tzapu/WiFiManager @ ^2.0.17
```

Add to `platformio.ini` `lib_deps`.

### Custom Parameters

WiFiManager supports extra form fields via `WiFiManagerParameter`. The portal collects:

| Field | NVS Key | Default | Notes |
|---|---|---|---|
| Device Name | `device_name` | `hivis-[mac_suffix]` | Max 20 chars |
| Server Address | `mqtt_server` | `mqtt.hvht.net` | MQTT broker hostname |

WiFi SSID and password are handled natively by WiFiManager and stored by it in its own NVS namespace (`espwifimgr`). MQTT credentials are NOT shown in the portal — they are provisioned by the server.

### Portal AP Name

The AP SSID shown to the user is: `HIVIS-Setup-[last4ofMAC]`  
Example: `HIVIS-Setup-A3F2`

### PortalModule API

```cpp
class PortalModule {
public:
    PortalModule();
    void begin();

    // Returns true if portal was triggered and completed successfully
    bool runFirstBoot();   // Blocks until configured or timeout (3 min)
    bool runReconfigure(); // Triggered by long press

    String getDeviceName();
    String getMqttServer();

    // After portal completes, save custom params to NVS
    void saveToNVS();
};
```

### Flow

```
runFirstBoot():
  1. WiFiManager.addParameter(deviceName)
  2. WiFiManager.addParameter(mqttServer)
  3. WiFiManager.autoConnect("HIVIS-Setup-XXXX")
     → If user connects and submits form:
         WiFi creds saved by WiFiManager to its NVS namespace
         Custom params available via getParameter()
  4. saveToNVS() → write device_name, mqtt_server to "hivis" NVS namespace
  5. Return true

runReconfigure():
  Same flow but uses WiFiManager.startConfigPortal() instead of autoConnect()
```

---

## Device Registration

After WiFi connects for the first time (provisioned flag not set), the device sends a registration request to the server.

### Registration MQTT Topic

```
hivis/register
```

### Registration Payload

```json
{
  "mac": "AA:BB:CC:DD:EE:FF",
  "device_name": "classroom-3",
  "fw_version": "2.0.0",
  "group": ""
}
```

### Server Response Topic

Server publishes to:
```
hivis/provision/[mac_lowercase_no_colons]
```

Example: `hivis/provision/aabbccddeeff`

### Server Response Payload

If MAC is in whitelist:
```json
{
  "status": "approved",
  "mqtt_user": "device_aabbccddeeff",
  "mqtt_pass": "generatedSecurePassword123",
  "device_id": "hivis-aabbccddeeff"
}
```

If MAC is NOT in whitelist:
```json
{
  "status": "rejected"
}
```

### Device Behavior on Response

- **Approved:** Save `mqtt_user`, `mqtt_pass`, `device_id` to NVS. Set `provisioned = 1`. Reconnect MQTT with new credentials. Double-beep.
- **Rejected:** Show "NOT AUTHORIZED" on display. Three error beeps. Enter offline mode. Retry registration on next boot.
- **No response in 30s:** Proceed in offline mode, retry on next boot.

---

## NVS Schema

Namespace: `"hivis"` (Preferences)

```cpp
Preferences prefs;
prefs.begin("hivis", false);

// Write
prefs.putString("device_name", name);
prefs.putString("mqtt_server", server);
prefs.putString("mqtt_user", user);
prefs.putString("mqtt_pass", pass);
prefs.putString("device_id", id);
prefs.putInt("provisioned", 1);

// Read
String name   = prefs.getString("device_name", "");
String server = prefs.getString("mqtt_server", "mqtt.hvht.net");
String user   = prefs.getString("mqtt_user", "");
String pass   = prefs.getString("mqtt_pass", "");
String id     = prefs.getString("device_id", "");
int provisioned = prefs.getInt("provisioned", 0);

prefs.end();
```

WiFi credentials (SSID/pass) are stored by WiFiManager in its own namespace and do not need to be read manually — `WiFi.begin()` with no arguments reconnects to the saved network.

---

## Device ID Generation

Device ID is MAC-derived and assigned by the server, but the device also generates a local fallback:

```cpp
String localId = "hivis-" + String((uint32_t)ESP.getEfuseMac(), HEX);
```

The server's assigned ID (from provision response) overwrites this in NVS and is used for all MQTT topics.

---

## Server Side: MAC Whitelist

The MAC whitelist is a simple JSON file on the server, managed manually by the operator.

File: `/opt/hivis/server/whitelist.json`

```json
{
  "devices": [
    {
      "mac": "aa:bb:cc:dd:ee:ff",
      "authorized": true,
      "group": "saskpoly",
      "notes": "Classroom unit 1"
    },
    {
      "mac": "11:22:33:44:55:66",
      "authorized": true,
      "group": "saskpoly",
      "notes": "Lab unit"
    }
  ]
}
```

Node-RED reads this file and checks incoming `hivis/register` messages against it. If authorized, Node-RED generates MQTT credentials and publishes the provision response.

Node-RED also creates the MQTT user in Mosquitto's password file via a shell exec node (or pre-configured). See Module 05 for server-side detail.

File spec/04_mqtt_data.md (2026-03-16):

# Module 04 — MQTT Topics, Payload Format & Offline Backfill

## Overview

All device-to-server communication uses MQTT over TLS (port 8883) to `mqtt.hvht.net`. Each device publishes to its own topic namespace using its assigned device ID.

---

## Topic Structure

```
hivis/[device_id]/sensors/temp
hivis/[device_id]/sensors/humidity
hivis/[device_id]/sensors/iaq
hivis/[device_id]/sensors/co2
hivis/[device_id]/sensors/bvoc
hivis/[device_id]/sensors/noise
hivis/[device_id]/system/battery_pct
hivis/[device_id]/system/battery_mv
hivis/[device_id]/system/rssi
hivis/[device_id]/system/accuracy
hivis/[device_id]/system/status

hivis/register                           ← Device registration (first boot)
hivis/provision/[mac_no_colons]          ← Server → device credential delivery
```

**Device ID format:** `hivis-[mac_hex]`  
Example: `hivis-aabbccddeeff`

---

## Standard Sensor Payload

All sensor topics use a **single JSON payload** published to a base topic:

```
hivis/[device_id]/data
```

This simplifies Node-RED routing (one handler vs seven separate subscriptions).

### Payload Format

```json
{
  "device_id": "hivis-aabbccddeeff",
  "device_name": "classroom-3",
  "group": "saskpoly",
  "ts": 1714000000,
  "ts_accurate": true,
  "fw_version": "2.0.0",
  "temp": 21.5,
  "hum": 45.2,
  "iaq": 82.3,
  "co2": 654,
  "bvoc": 0.51,
  "db": 48.2,
  "bat_pct": 87,
  "bat_mv": 3850,
  "rssi": -62,
  "accuracy": 3,
  "backfill": false
}
```

### Field Reference

| Field | Type | Unit | Notes |
|---|---|---|---|
| `device_id` | string | — | MAC-derived ID |
| `device_name` | string | — | Human-readable name |
| `group` | string | — | Organization group (future use) |
| `ts` | int | Unix seconds | 0 if no NTP time available |
| `ts_accurate` | bool | — | false if no NTP during recording |
| `fw_version` | string | — | Semantic version |
| `temp` | float | °C | 1 decimal place |
| `hum` | float | % RH | 1 decimal place |
| `iaq` | float | 0–500 | BSEC IAQ scale |
| `co2` | float | ppm | BSEC equivalent CO2 |
| `bvoc` | float | ppm | Breath VOC equivalent |
| `db` | float | dB SPL | Calibrated sound level |
| `bat_pct` | int | % | Battery percentage (0–100) |
| `bat_mv` | int | mV×10 | e.g. 3850 = 3.85V (×100 actually) |
| `rssi` | int | dBm | WiFi signal strength |
| `accuracy` | int | 0–3 | BSEC accuracy level |
| `backfill` | bool | — | true if this is a buffered offline record |

**Note:** `bat_mv` is stored as integer millivolts (e.g. 3850 for 3.850V). Multiply raw ADC voltage × 1000 before storing.

---

## MqttModule Changes vs v1

The `MqttModule` is updated to:
- Use `device_id` from NVS (not hardcoded)
- Publish to `hivis/[device_id]/data` with full JSON payload
- Subscribe to `hivis/provision/[mac]` for credential provisioning response
- Subscribe to `hivis/[device_id]/cmd` for future server commands (reserved, not implemented)
- Use `setInsecure()` for TLS (same as v1, CA pinning is a future upgrade)

### MQTT Keepalive

Set via `cfg.mqttKeepaliveS` (default 60s). PubSubClient `setKeepAlive()` must be called before `connect()`.

### Reconnect Logic

On `publish()` call:
1. If WiFi disconnected → `setupWifi()` → if fails, buffer locally
2. If MQTT disconnected → `connectMqtt()` (3 retries, 1s apart)
3. If still disconnected → skip publish, buffer locally

---

## Offline Backfill

### During Offline Period

```cpp
// In offline mode, store to LittleFS
void OfflineBuffer::store(const DisplayData& data) {
    JsonDocument doc;
    doc["ts"] = 0;
    doc["ts_accurate"] = false;
    doc["temp"] = data.temp;
    // ... all fields
    doc["backfill"] = true;

    String line;
    serializeJson(doc, line);

    File f = LittleFS.open("/offline_buffer.ndjson", "a");
    if (f) {
        f.println(line);
        f.close();
        _count++;
    }

    if (_count >= MAX_BUFFER_RECORDS) {
        _dropOldest(); // Remove first line from file
    }
}
```

File format: newline-delimited JSON (NDJSON) for easy append and line-by-line reading.

### On Reconnect: Backfill Flush

```cpp
void OfflineBuffer::flush(MqttModule* mqtt) {
    if (!LittleFS.exists("/offline_buffer.ndjson")) return;

    File f = LittleFS.open("/offline_buffer.ndjson", "r");
    if (!f) return;

    // Count lines
    int count = 0;
    while (f.available()) {
        f.readStringUntil('\n');
        count++;
    }
    f.seek(0);

    // Get current time
    time_t now = time(nullptr);
    int intervalS = cfg.mqttIntervalMs / 1000;

    // Read and publish with approximate timestamps
    int index = count - 1;
    while (f.available()) {
        String line = f.readStringUntil('\n');
        line.trim();
        if (line.isEmpty()) { index--; continue; }

        JsonDocument doc;
        deserializeJson(doc, line);

        // Assign approximate timestamp (older records first)
        doc["ts"] = (int)(now - (index * intervalS));
        doc["ts_accurate"] = false;
        doc["backfill"] = true;

        String payload;
        serializeJson(doc, payload);

        mqtt->publishRaw("hivis/" + deviceId + "/data", payload);
        index--;
        delay(50); // Don't flood broker
    }

    f.close();
    LittleFS.remove("/offline_buffer.ndjson");
    _count = 0;
    Serial.println("Offline buffer flushed.");
}
```

### Node-RED Handling of Backfill

Node-RED receives all `hivis/+/data` messages. When `backfill == true`:
- Use `msg.payload.ts` as the InfluxDB timestamp (not `Date.now()`)
- Tag the measurement with `backfill: true` in InfluxDB for visibility

InfluxDB 2.x accepts historical writes with past timestamps natively. No special configuration needed.

---

## MQTT Security

| Setting | Value |
|---|---|
| Port | 8883 (TLS) |
| Auth | Username + password (provisioned per device) |
| TLS | `setInsecure()` — accepts self-signed cert |
| Future upgrade | CA cert pinning (replace `setInsecure()` with `setCACert()`) |

Each device has its own MQTT username/password, provisioned by the server after MAC authorization. This allows per-device revocation by disabling the Mosquitto user.

### Mosquitto ACL

Each device user can only publish to its own namespace:

```
# /etc/mosquitto/acl
user device_aabbccddeeff
topic write hivis/aabbccddeeff/#
topic read  hivis/provision/aabbccddeeff

user device_112233445566
topic write hivis/112233445566/#
topic read  hivis/provision/112233445566

# Node-RED internal user (full access)
user nodered_bridge
topic readwrite hivis/#
```

Note: Topic in ACL uses MAC without hyphens to match the provisioned user naming convention. Adjust naming to be consistent.

---

## QoS Levels

| Topic | QoS | Retained | Notes |
|---|-----|---|---|
| `hivis/[id]/data` (live) | 0 | false | Fire and forget, high frequency |
| `hivis/[id]/data` (backfill) | 1 | false | At-least-once for reliability |
| `hivis/register` | 1 | false | Registration must be received |
| `hivis/provision/[mac]` | 1 | true | Retained so device catches it on reconnect |

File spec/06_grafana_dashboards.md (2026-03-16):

# Module 06 — Grafana Dashboards

## Overview

Three dashboards cover all monitoring needs. All dashboards use InfluxDB 2.x as the data source with Flux query language.

---

## Dashboard 1: Per-Device Real-Time

**Title:** `HIVIS — [Device Name]`  
**Purpose:** Live monitoring for a single device  
**Refresh:** 5 seconds  
**Default time range:** Last 1 hour

### Variables

| Variable | Type | Query | Purpose |
|---|---|---|---|
| `$device_id` | Query | `import "influxdata/influxdb/schema" schema.tagValues(bucket: "hivis", tag: "device_id")` | Device selector |

### Panels

**Row 1: Status Bar**

| Panel | Type | Metric | Notes |
|---|---|---|---|
| IAQ | Stat | `iaq` | Color thresholds: green <100, yellow 100–200, red >200 |
| CO2 | Stat | `co2` | Unit: ppm |
| Noise | Stat | `db` | Unit: dB |
| Battery | Gauge | `bat_pct` | 0–100%, color: red <20, yellow <50, green ≥50 |
| WiFi | Stat | `rssi` | Unit: dBm |
| Accuracy | Stat | `accuracy` | 0–3, display as text: 0=Calibrating, 3=Optimal |

**Row 2: Air Quality Trend**

| Panel | Type | Metrics | Notes |
|---|---|---|---|
| IAQ Over Time | Time series | `iaq` | Threshold lines at `iaq_warn` (100) and `iaq_alert` (200) |
| CO2 Over Time | Time series | `co2` | Unit: ppm |
| BVOC Over Time | Time series | `bvoc` | Unit: ppm |

**Row 3: Environment**

| Panel | Type | Metrics | Notes |
|---|---|---|---|
| Temperature | Time series | `temp` | Unit: °C |
| Humidity | Time series | `hum` | Unit: % |
| Noise Level | Time series | `db` | Unit: dB SPL |

**Row 4: System**

| Panel | Type | Metrics | Notes |
|---|---|---|---|
| Battery % | Time series | `bat_pct` | Unit: % |
| Battery Voltage | Time series | `bat_mv` | Unit: mV, transform ÷1000 for V display |
| WiFi RSSI | Time series | `rssi` | Unit: dBm |

### Example Flux Query (IAQ)

```flux
from(bucket: "hivis")
  |> range(start: v.timeRangeStart, stop: v.timeRangeStop)
  |> filter(fn: (r) => r._measurement == "air_quality")
  |> filter(fn: (r) => r.device_id == "${device_id}")
  |> filter(fn: (r) => r._field == "iaq")
  |> aggregateWindow(every: v.windowPeriod, fn: mean, createEmpty: false)
  |> yield(name: "mean")
```

---

## Dashboard 2: Fleet Overview

**Title:** `HIVIS — Fleet Overview`  
**Purpose:** Status of all devices at a glance  
**Refresh:** 30 seconds  
**Default time range:** Last 15 minutes

### Panels

**Row 1: Device Status Table**

A single `Table` panel showing all devices with their latest values:

| Column | Source | Notes |
|---|---|---|
| Device Name | tag `device_name` | |
| Group | tag `group` | |
| Last Seen | `_time` | Time since last data point |
| IAQ | field `iaq` | Color coded |
| CO2 | field `co2` | ppm |
| Noise | field `db` | dB |
| Battery | field `bat_pct` | % |
| RSSI | field `rssi` | dBm |
| Accuracy | field `accuracy` | 0–3 |
| Online | derived | Green if last seen < 2min, red otherwise |

Flux query for latest values per device:
```flux
from(bucket: "hivis")
  |> range(start: -15m)
  |> filter(fn: (r) => r._measurement == "air_quality")
  |> filter(fn: (r) => r._field == "iaq" or
                       r._field == "co2" or
                       r._field == "db" or
                       r._field == "bat_pct" or
                       r._field == "rssi" or
                       r._field == "accuracy")
  |> last()
  |> pivot(rowKey:["_time", "device_id", "device_name", "group"],
           columnKey: ["_field"],
           valueColumn: "_value")
```

**Row 2: IAQ Comparison**

A multi-device time series showing IAQ for all devices on the same chart. Different color per device.

```flux
from(bucket: "hivis")
  |> range(start: v.timeRangeStart, stop: v.timeRangeStop)
  |> filter(fn: (r) => r._measurement == "air_quality")
  |> filter(fn: (r) => r._field == "iaq")
  |> aggregateWindow(every: v.windowPeriod, fn: mean, createEmpty: false)
```

**Row 3: Battery Overview**

Bar gauge showing current battery % for all devices side by side.

---

## Dashboard 3: Historical Trends

**Title:** `HIVIS — Historical Data`  
**Purpose:** Long-term trend analysis  
**Refresh:** 5 minutes (or manual)  
**Default time range:** Last 7 days

### Variables

| Variable | Type | Notes |
|---|---|---|
| `$device_id` | Query | Multi-select, default = All |
| `$interval` | Interval | Auto-calculated based on time range |

### Panels

**Row 1: IAQ History**

Time series — all selected devices, `aggregateWindow` by `$interval`, `fn: mean`.  
Annotation layer: backfill data points shown with a different marker color.

**Row 2: CO2 History**

Time series — all selected devices.

**Row 3: Temperature & Humidity**

Two panels side by side. Temperature °C and Humidity %.

**Row 4: Noise History**

Time series — dB SPL over selected period.

**Row 5: Battery Drain**

Time series — battery % per device. Useful for identifying devices needing charge.

### Backfill Annotation

To visually distinguish backfill data:
```flux
from(bucket: "hivis")
  |> range(start: v.timeRangeStart, stop: v.timeRangeStop)
  |> filter(fn: (r) => r._measurement == "air_quality")
  |> filter(fn: (r) => r.backfill == "true")
  |> filter(fn: (r) => r.device_id == "${device_id}")
  |> filter(fn: (r) => r._field == "iaq")
```
Use as annotation query. Backfill points appear as markers on the timeline.

---

## Grafana Provisioning

Dashboards can be provisioned as JSON files so they are automatically loaded when Grafana starts.

File structure:
```
./grafana/provisioning/
  datasources/
    influxdb.yml         ← See Module 05
  dashboards/
    hivis.yml            ← Dashboard provider config
    per_device.json      ← Dashboard 1
    fleet_overview.json  ← Dashboard 2
    historical.json      ← Dashboard 3
```

Provider config (`hivis.yml`):
```yaml
apiVersion: 1

providers:
  - name: HIVIS Dashboards
    type: file
    options:
      path: /etc/grafana/provisioning/dashboards
    updateIntervalSeconds: 30
    allowUiUpdates: true
```

---

## Alert Rules (Optional, Future)

Grafana supports alerting. Not in scope for 2.0 but the data model supports it.  
When implemented, alerts can notify via email or webhook when:
- IAQ exceeds `iaq_alert` for more than 5 consecutive minutes
- Any device goes offline (no data for > 5 minutes)
- Battery below 15%

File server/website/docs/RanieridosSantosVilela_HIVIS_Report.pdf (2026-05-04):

# HIVIS MONITOR 2.0

## Indoor Air Quality & Acoustic Monitoring System

Build Guide, Operating Manual & Project Report

Course | PROJ 108
Institution | Saskatchewan Polytechnic
Author | Ranieri dos Santos Vilela
Supervisor | Aaron Rodgers
Date | April 2026

HIVIS Monitor 2.0 — PROJ 108

# Contents

# Project Introduction

## Title

HIVIS Monitor – Wearable Environmental Monitor for Industrial Workers

## Overview

The HIVIS Monitor is a wearable IoT device designed to be worn on a worker's belt or integrated directly into a high-visibility safety vest. It continuously measures air quality, temperature, humidity, and noise levels, sending that data in real time to a self-hosted server. Workers can see their current readings on a small OLED display on the device, while supervisors and management can monitor the entire workforce through a live web dashboard from anywhere.

The primary target audience is tradespeople and industrial workers, along with their supervisors and safety managers who need visibility into field conditions.
Workers in trades and industrial environments are regularly exposed to conditions that can affect their health without knowing it — poor air quality, chemical vapors, elevated CO₂, and high noise levels are common in confined spaces, workshops, and industrial facilities. Most of the time, nobody is measuring any of it. Dedicated monitors exist, but they are expensive, require calibration, and are only deployed when regulations specifically demand it. The HIVIS Monitor fills that gap. It is not a certified gas detector and should not be treated as one — it is a continuous, real-time awareness tool that gives workers and employers data they currently have none of.

The system is fully self-hosted. No third-party cloud subscriptions, no data leaving your own infrastructure.

## Purpose & SDG Alignment

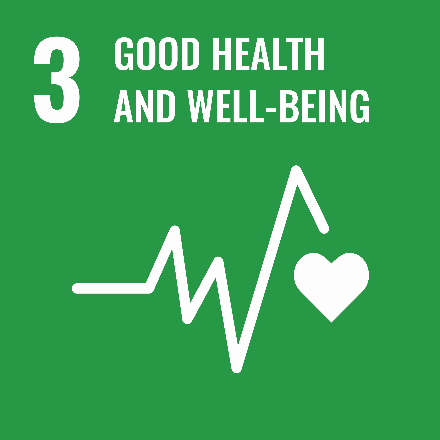
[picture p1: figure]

SDG 3 — Good Health and Well-Being Provides continuous monitoring of environmental conditions that affect worker health — respiratory exposure, noise, and air quality — giving visibility into hazards that would otherwise go undetected.

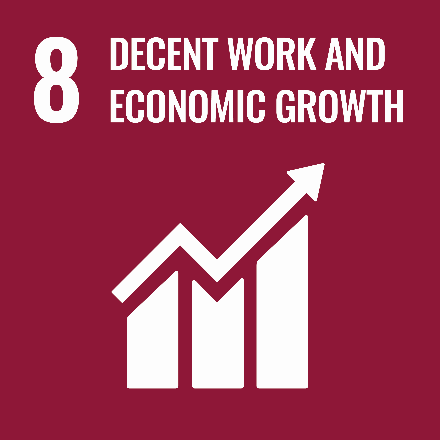
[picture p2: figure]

SDG 8 — Decent Work and Economic Growth Safe working conditions are a fundamental part of decent work. The HIVIS Monitor gives workers and employers the data needed to identify risks before they turn into incidents or long-term health impacts.

SDG 9 — Industry, Innovation and Infrastructure Demonstrates that industrial safety monitoring does not have to rely on expensive proprietary systems. An open, self-hosted IoT solution built on accessible hardware is a practical path for workplaces that do not have enterprise budgets.

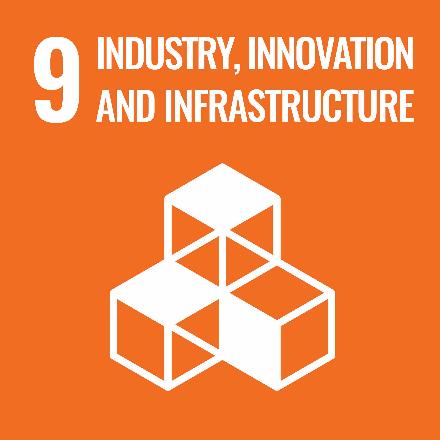
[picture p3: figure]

## Required Skills and Knowledge

Before starting this build, you should be comfortable with basic soldering — through-hole and ideally surface-mount if you are assembling the PCB yourself. You will also need to know how to operate a 3D printer to print the enclosure. On the software side, basic computer skills are enough for most of the setup, but some familiarity with command line and SSH will be needed when configuring the server. No advanced programming knowledge is required — the firmware is provided ready to flash.

# Materials and Tools

## Hardware Bill of Materials

The hardware list below covers a single device. Reasoning for each major choice is recorded in Chapter 7.
Item | Part / Specification | Qty | CAD
MCU board | ESP32 DoIt DevKit V1 (4 MB flash) | 1 | $4.70
Air-quality sensor | Bosch BME688 breakout (I²C) | 1 | $30.98
Microphone | InvenSense INMP441 MEMS (I²S) | 1 | $8.20
Display | 0.96" SSD1306 OLED, I²C | 1 | $6.40
Buzzer | Passive piezo, 3.3 V tolerant | 1 | $1.20
Button | 6 mm tactile through-hole | 1 | $0.30
Charger/Boost | J5019 1S Li-Ion charger + 5V boost | 1 | $6.00
Battery (Option A) | LiPo pouch 654060, 2100mAh, 3.7V | 1 | $25.00
Battery (Option B) | 18650 Li-ion cell, 3.7V | 1 | $8.00
PCB | Custom 2-layer, 70 × 50 mm (JLCPCB) | 1 | $3
Enclosure | 3D-printed PLA case (two parts) | 1 | $3
Misc | Resistors, Capacitors, JST Connector
- $1
Total (Option A) | | | ~ $90
Total (Option B) | | | ~ $73

## Server & Software

A single Linux host is sufficient for a small fleet (under ~50 devices). The reference deployment uses Docker Compose with seven containers: Mosquitto (MQTT broker), Node-RED (decoding and routing), InfluxDB 2.x (time-series storage), Grafana (dashboards), nginx (reverse proxy), certbot (Let's Encrypt), and an OTA file server.

Component | Version / Notes
OS | Ubuntu Server 22.04 LTS or Debian 12
Firmware toolchain | PlatformIO Core + Arduino-ESP32 framework
Broker | Mosquitto 2.0+ on port 8883 (TLS)
Database | InfluxDB 2.7+ with Flux query language
Dashboards | Grafana 10+ with InfluxDB datasource
VPN (optional) | Tailscale for remote admin

## Tools

- Temperature-controlled soldering iron, 0.5 mm leaded or lead-free solder, flux pen.
- Digital multimeter for continuity and voltage checks.
- USB-C/micro USB cable rated for data (not power-only).
- 3D printer with 0.4 mm nozzle; PETG or PLA filament.
- Computer with VS Code + PlatformIO extension, plus a serial terminal.
- Wire Cutters / strippers
- Helping hands

# Hardware Assembly

## Circuit Diagram

The circuit diagram is bellow

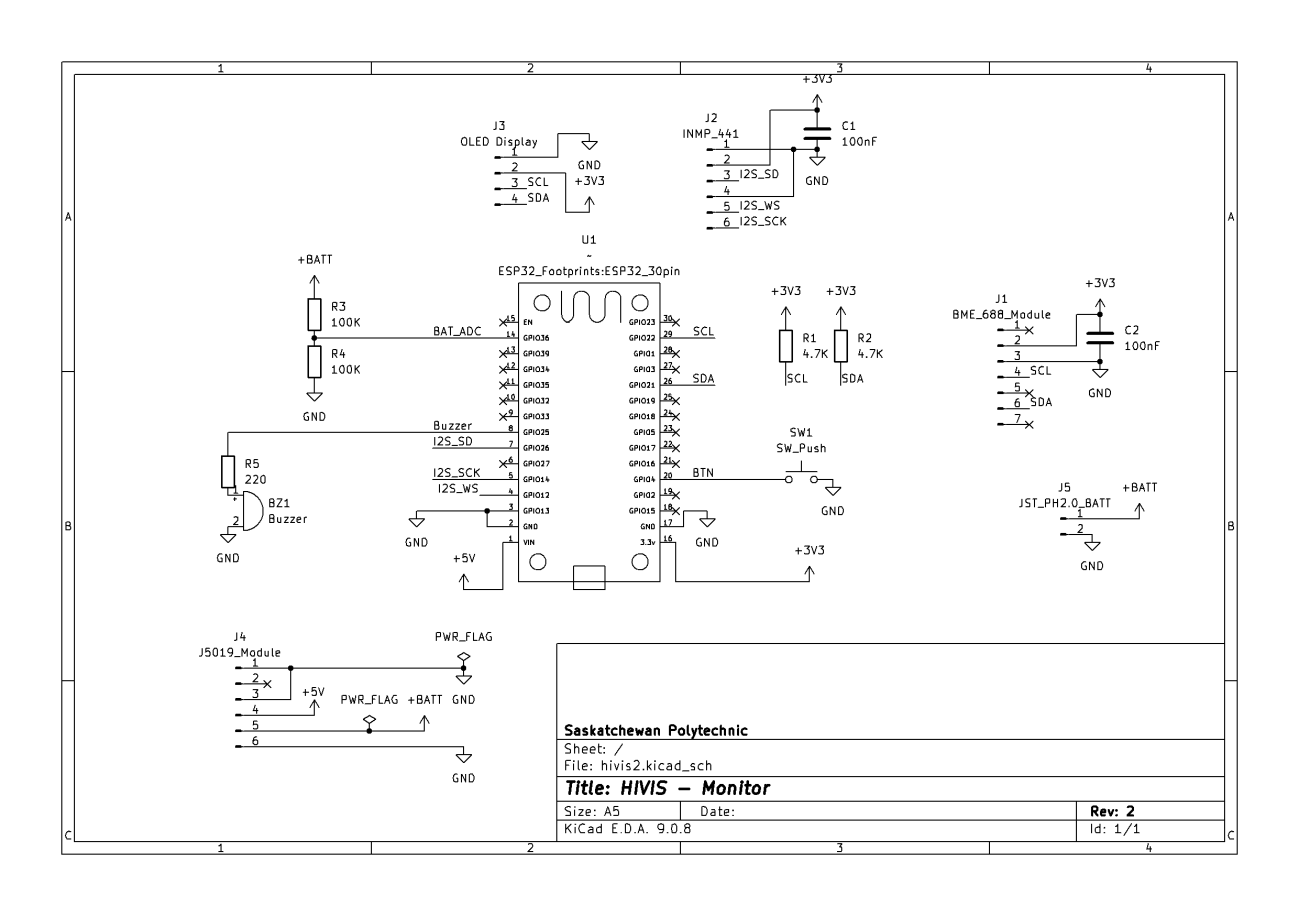
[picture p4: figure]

Figure 1 HIVIS Monitor Schematic (HIVIS2, Rev. 2)

## Pin Assignments

All sensor connections are routed through the ESP32's hardware peripherals. I²C is shared between the BME688 and the OLED; I²S is dedicated to the microphone.
Function ESP32 GPIO | Peripheral / Note
GPIO | Signal | Function
21 | I2C SDA | I2C data — BME688 sensor + OLED display (shared bus)
22 | I2C SCL | I2C clock — BME688 sensor + OLED display (shared bus)
12 | I2S WS | INMP441 microphone — Word Select (L/R clock)
13 | I2S LR | INMP441 microphone — L/R channel select (driven LOW → RIGHT channel)

14 | I2S SCK | INMP441 microphone — Bit Clock
26 | I2S SD | INMP441 microphone — Serial Data (audio in)
25 | PWM (LEDC) | Buzzer — tone output via ledcAttachPin
4 | Digital Input (PULLUP) | Button — active LOW, supports long-press & double-press
36 | ADC (analog in) | Battery voltage — averaged 16-sample read through voltage divider (×2.2 ratio)

## PCB Reference

The PCB is a 2-layer, 70 × 50 mm board with a top ground pour and routed signals on the bottom. Plated through-holes are 0.8 mm; the smallest clearance is 6 mil. Both renders below are produced from the project's gerber files.

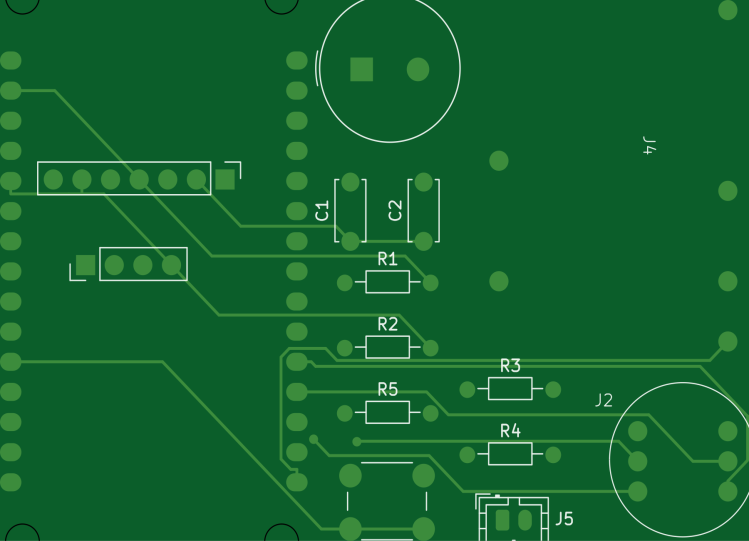
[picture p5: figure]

Figure 2 PCB top view showing component silkscreen, copper pour, and signal routing.

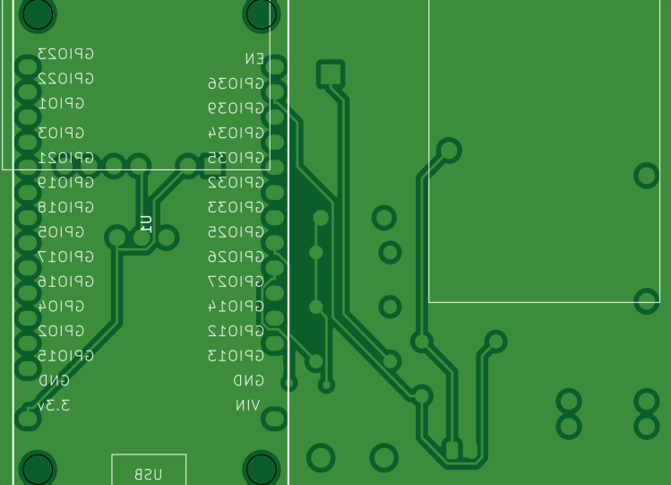
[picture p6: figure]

Figure 3 PCB bottom view; bottom-layer routing handles I²S and indicator returns.

## Assembly Steps

Step 1 — Inspect the Bare PCB

Before soldering anything, inspect the bare PCB under good lighting. Check that all copper traces are clean, there are no visible shorts between pads, and the silkscreen labels (R1–R5, C1–C2, J1–J5, BZ1, SW1) are all legible. If you ordered SMD assembly from JLCPCB, skip to Step 3 — the resistors, capacitors, and JST connector will already be soldered.

Step 2 — Solder SMD Components (if not pre-assembled)

If you are building from a bare PCB without assembly service, solder the SMD components first. These are the smallest parts and need to go on before anything else gets in the way.

Solder in this order:

- C1, C2 — 100nF decoupling capacitors (0402)
- R3, R4 — 100kΩ resistors, voltage divider for battery ADC (0402)
- R1, R2 — 4.7kΩ pull-up resistors for I2C bus (0402)
- R5 — 220Ω resistor for buzzer (0402)
- J5 — JST-PH 2.0mm battery connector
Use flux, a fine tip, and work under magnification if possible. 0402 components are small — tweezers are essential. After soldering, check each pad under light for bridges.
Step 3 — Solder Through-Hole Components
With the SMD components done (or pre-assembled), move on to the through-hole parts. These are straightforward — insert from the front, solder from the back.
- SW1 — Tactile button. Insert into the 4 pads and solder from the back. Press it a few times to confirm it clicks cleanly.
- BZ1 — Passive piezo buzzer. Mind the polarity — the positive pin is marked on the silkscreen. Solder from the back.
Step 4 — Install the Breakout Modules

Now seat the breakout modules. All of these connect via pin headers — either solder header pins to the module first if they are not pre-installed, then solder them into the PCB.

- BME688 — Top of the board. This is the environmental sensor. Seat it into J1, making sure VIN, GND, SCL, and SDA are aligned with the silkscreen. The sensor opening on the BME688 should face up and away from the PCB — do not cover it with anything.
- SSD1306 OLED — Left side, J3. 4-pin header: VCC, GND, SCL, SDA. The display should face outward so it is visible when the device is assembled in its enclosure.
- INMP441 microphone — J2. 6-pin connection: VDD, GND, SD, L/R, WS, SCK. The microphone port (small hole on the module) should face outward and not be blocked by other components or the enclosure.

Known PCB Issues — Rev. 2
In the current revision of the PCB, the footprint positions of the BME688 and INMP441 are incorrect.
- BME688 — The pad layout does not align correctly with the breakout module. The workaround used in the current build is to connect the BME688 via short wires instead of soldering it directly to the PCB headers. It still functions correctly — just not seated directly on the board.
- INMP441 — The footprint is mirrored. The workaround is to mount the module inverted (flipped upside down). It still connects and works correctly in this orientation.
Both issues are documented and will be corrected in the next PCB revision.
Step 5 — Install the ESP32

The ESP32 mounts on the back side of the PCB via two rows of pin headers. This keeps the USB port accessible from the back for programming and the antenna unobstructed.
Insert the pin headers into the PCB from the back, seat the ESP32 DevKit V1 onto the headers, and solder both sides — the headers to the PCB, and the ESP32 to the headers. Double-check alignment against the GPIO silkscreen on the PCB before soldering. Once soldered it is difficult to remove.

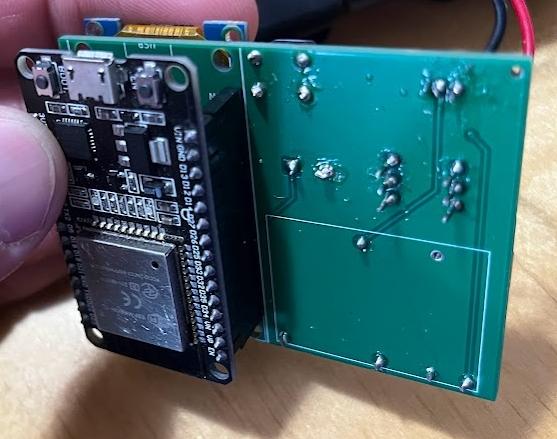
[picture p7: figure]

Figure 4 PCB Assembled Back

Step 6 — Install the J5019 Charger/Boost Module
The J5019 mounts at J4 and is soldered directly to the PCB. It handles both charging the battery from USB and boosting the battery voltage to 5V to power the ESP32. Solder all pads securely — this is the power path for the entire device, so cold joints here will cause problems.
The Micro-USB port on the J5019 is the charging input for the device. Make sure it is accessible after the board is installed in the enclosure.

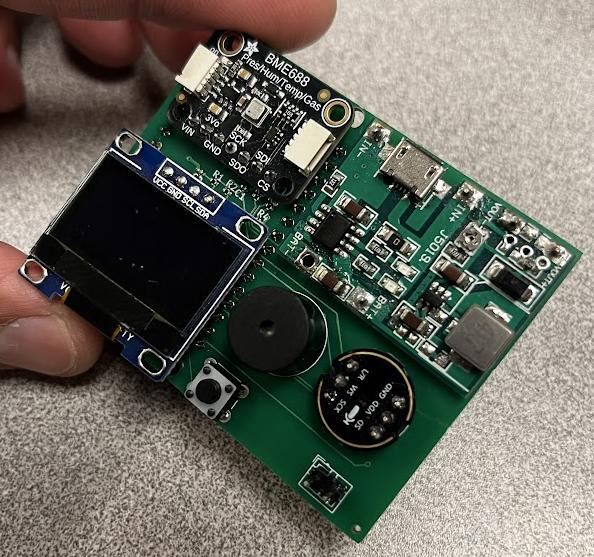
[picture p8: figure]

Figure 5 PCB Assembled Front

Step 7 — Connect the Battery
Connect the LiPo or 18650 battery to J5 via the JST-PH 2.0mm connector. Check polarity before connecting — red wire to positive (+BATT), black wire to GND. Reversing polarity will damage the J5019 and possibly the ESP32.
Once connected, the J5019 charge LED should indicate the battery state. If nothing powers on, check the JST connector orientation and verify the J5019 solder joints.
Step 8 — Mount the System in the Enclosure

The enclosure is a two-part 3D printed PLA case with a snap-fit lid. Print both parts with default infill and supports enabled. STL files are included with this submission.

Option A — LiPo Pouch Battery
Place the battery into the case first, sitting flat against the bottom. Then lower the PCB on top aligning the USB ports with the holes in the case, connect the JST battery cable before seating it fully. Close the lid and snap it into place.

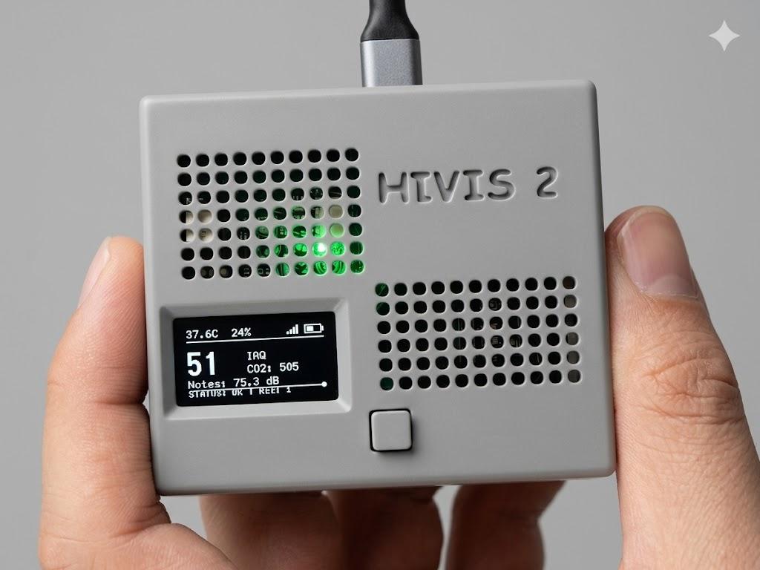
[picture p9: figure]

Figure 6 Enclosure with pouch battery

Option B — 18650 Battery
Place the PCB into the case first align the USB ports with the holes in the case. The 18650 battery mounts on the outside of the enclosure — connect it to the J5019 module via the JST connector before closing.

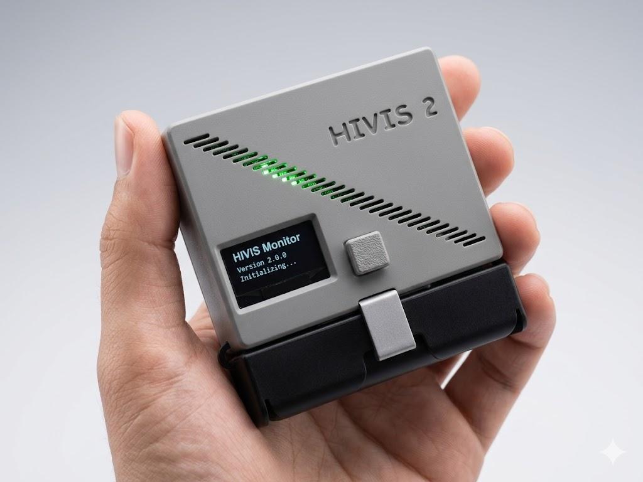
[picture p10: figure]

Figure 7 Enclosure with External 18650 Battery

Once assembled, verify the following before closing the lid permanently:

- The OLED display is visible through the window in the lid
- The J5019 Micro-USB charging port is accessible from outside
- The ESP32 Micro-USB programming port is accessible from outside
- The button is aligned with its opening in the case
Snap the lid into place. The device is ready for use.

## Troubleshooting Tips

Symptom | Likely Cause | Fix
Nothing powers on after | Reversed JST polarity or cold | Check polarity, reflow J5019
battery connect | J5019 solder joint | pads

OLED does not display
anything
Bad header connection on J3 | Reflow OLED header pins, check VCC/GND
BME688 not detected (I2C | Header misaligned or cold joint | Check SCL/SDA alignment,
error in serial) | on J1 | reflow

Microphone reads 0 dB
constantly

INMP441 L/R pin not pulled LOW Verify GPIO13 connection and R5

Button does not respond | SW1 solder bridge or wrong orientation | Check 4 pads, confirm click
Device not recognized by PC via USB | Power-only USB cable | Use a data-rated USB-C cable
ESP32 not detected | Cold joint on pin headers | Reflow all header pins on both sides

# Software Setup

## Development Environment

The firmware is written in C++ using the Arduino framework and built with PlatformIO. You will need the following installed on your computer:
- Visual Studio Code — download at code.visualstudio.com
- PlatformIO extension — install from the VS Code Extensions marketplace, search for "PlatformIO IDE"
That is all. PlatformIO handles the compiler, the Arduino-ESP32 framework, and all library dependencies automatically when you open the project for the first time. You do not need to install the Arduino IDE or any libraries manually.

## Getting the Code

Clone or download the project repository from GitHub:

https://github.com/ranieriv/HIVIS2
Open the project folder in VS Code. PlatformIO will detect the platformio.ini file and begin downloading the required framework and libraries automatically. This may take a few minutes on the first run.

## Firmware Architecture

The firmware is organized into modules, each responsible for a specific part of the device. Here is a quick overview of the key files:
File | Purpose
main.cpp | Boot sequence, main loop, ties all modules together
SensorModule.cpp BME688 initialization, BSEC2 sensor reads, IAQ/CO2/VOC output MicModule.cpp INMP441 I2S microphone reads, dB SPL calculation DisplayModule.cpp SSD1306 OLED page rendering — IAQ, environment, system status
MqttModule.cpp | MQTT connection, publishing sensor data, registration flow
OTAModule.cpp | OTA update polling, firmware version check, HTTP update
ButtonModule.cpp | Single-button gesture detection — short, long, double, hold
BuzzerModule.cpp Tone playback via LEDC PWM — distinct tones per event
ConfigHandler.cpp | LittleFS config.json read/write, NVS credential storage
OfflineBuffer.cpp | Offline data buffering to LittleFS, backfill on reconnect
The main loop runs every 3 seconds — it reads the sensors, updates the display, and publishes data to the MQTT broker. If WiFi or MQTT is unavailable, readings are saved to the offline buffer and uploaded automatically when the connection is restored.

## Code Structure – Key Snippets

## Button Gesture Detection

The device uses a single button (GPIO4) for all user interactions. Rather than separate buttons for each function, the firmware classifies each press by duration and timing. Short presses are held in a counter until the double-press window expires before being resolved — this is what allows a single button to distinguish a tap from a double-tap.

## Offline Buffer

When MQTT is unavailable, readings are not lost — they are saved to the device's LittleFS filesystem as NDJSON (one JSON object per line). If the buffer reaches its maximum of 500 records, the oldest entry is dropped to make room. When the connection is restored, all buffered readings are uploaded with a backfill: true flag so the server can distinguish them from live data.

// On release: classify by hold duration

if (!_debounced && prevDebounced && _pressed) {

_pressed = false;

unsigned long duration = millis() - _pressStart;

if (duration >= 5000) | _factoryFlag = true; | // 5s →

factory reset

else if (duration >= (unsigned long)_longPressMs) _longFlag | = true; | // long

press

else {

_pendingShorts++; | // accumulate potential

double-press

_lastReleaseTime = millis();

}

}

// After the double-press window, resolve accumulated short presses

if (_pendingShorts > 0 && !_pressed &&

millis() - _lastReleaseTime >= (unsigned long)_doublePressMs) {

if (_pendingShorts >= 2) _doubleFlag = true;

else | _shortFlag | = true;

_pendingShorts = 0;

}

## BME 688 Sensor Read

The BSEC2 library handles sensor timing and processing internally. Each time it completes a sample, it fires a callback with the results. The firmware unpacks whichever outputs are ready and caches them. Calibration state is saved automatically when accuracy first reaches maximum or after a set time interval — this is what allows the device to skip the 30-minute warmup on subsequent boots.

void OfflineBuffer::store(const DisplayData& data) {

int n = count();

if (n >= MAX_RECORDS) _dropOldest();

const char* mode = (n > 0) ? "a" : "w";

File f = LittleFS.open(PATH, mode);

if (!f) return;

JsonDocument doc;

doc["ts"] | = 0;
doc["temp"] | = round(data.temp | * 10.0f) / 10.0f;
doc["hum"] | = round(data.hum | * 10.0f) / 10.0f;
doc["iaq"] | = round(data.iaq | * 10.0f) / 10.0f;
doc["co2"] | = round(data.co2);
doc["bvoc"] | = round(data.bvoc | * 100.0f) / 100.0f;
doc["db"] | = round(data.db | * 10.0f) | / 10.0f;

doc["backfill"] = true;

serializeJson(doc, f);

f.println();

f.close();

}

The full source code for all modules is available at github.com/ranieriv/HIVIS2.

## Device Boot Sequence

When the device powers on, it runs through the following steps in order:
1. Load config.json from LittleFS
2. Initialize hardware — I2C bus, OLED display, buzzer, button
3. Show splash screen, load saved credentials from NVS
4. If no WiFi or server credentials saved → launch captive portal (HIVIS-Setup-XXXX)
5. Initialize BME688 sensor and INMP441 microphone
6. Connect to WiFi (15 second timeout)
7. Sync time via NTP
8. If not provisioned → register with server via MQTT bootstrap
9. Connect to MQTT broker with provisioned credentials
10. Flush offline buffer if any records exist
11. Check for OTA firmware update (once every 24 hours) void BME688Module::newDataCallback(const bme68xData data,

const bsecOutputs outputs, Bsec2 bsec) {

if (!outputs.nOutputs) return;

for (uint8_t i = 0; i < outputs.nOutputs; i++) {

const bsecData &o = outputs.output[i];

switch (o.sensor_id) {

case BSEC_OUTPUT_IAQ: | _iaq | = o.signal;

_accuracy = o.accuracy; break;

case BSEC_OUTPUT_CO2_EQUIVALENT: | _co2 | = o.signal;

break;

case BSEC_OUTPUT_BREATH_VOC_EQUIVALENT: | _bvoc = o.signal;

break;

case BSEC_OUTPUT_SENSOR_HEAT_COMPENSATED_TEMPERATURE: _temp = o.signal;

break;

case BSEC_OUTPUT_SENSOR_HEAT_COMPENSATED_HUMIDITY: | _hum | = o.signal;

break;

}

}

bool accuracyJustHitMax = (_accuracy == 3 && lastSaveAcc != 3);

bool intervalElapsed | = (millis() - lastSaveTime >= _saveIntervalMs);

if (_accuracy > 0 && (accuracyJustHitMax || intervalElapsed))

_instance->saveState();

}

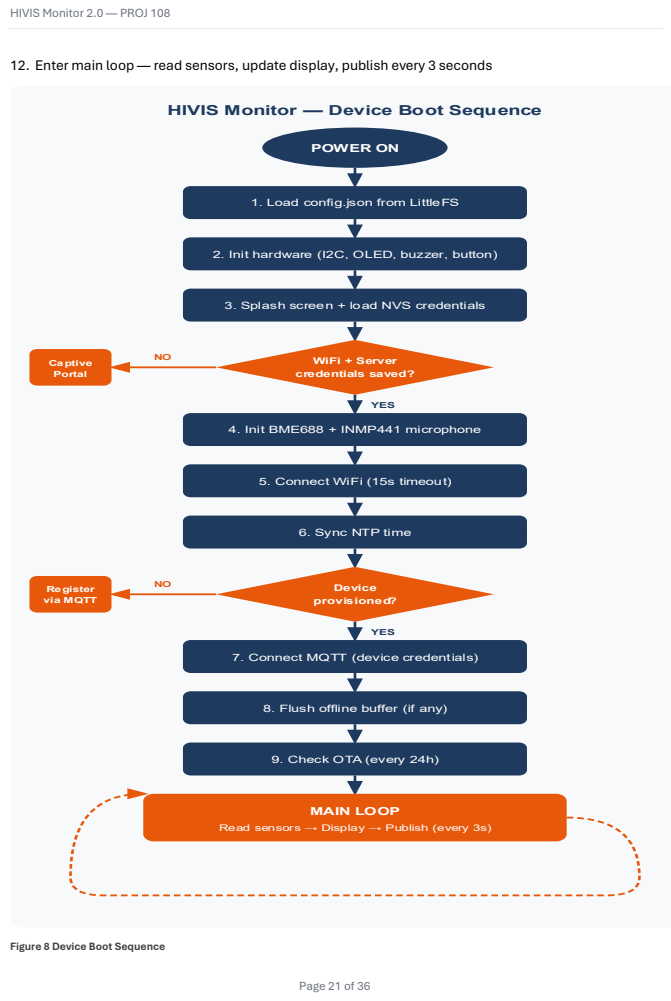
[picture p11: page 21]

12. Enter main loop — read sensors, update display, publish every 3 seconds

Figure 8 Device Boot Sequence

## Flashing the Firmware

Flashing the device is done entirely inside VS Code through the PlatformIO sidebar. There are three steps and they must be done in order:

- Step 1 — Build Filesystem Image Click Build Filesystem Image in the PlatformIO project tasks. This packages the data/ folder — which contains config.json and other device files — into a LittleFS image ready to be flashed.
- Step 2 — Upload Filesystem Image Click Upload Filesystem Image. This flashes the LittleFS partition to the ESP32. Make sure the device is connected via USB before this step.
- Step 3 — Upload Firmware Click Upload (or Upload and Monitor if you want to see the serial output immediately after flashing). This compiles and flashes the main firmware to the device.

After flashing, the device will reboot and begin the boot sequence described above. If this is the first time the device has been flashed, it will launch the captive portal to collect WiFi and server credentials.

## Configuration

Most device behaviour is controlled by config.json, stored in the data/ folder. You only need to edit this file if you want to change default settings — things like sensor read intervals, display timeout, pin assignments, or MQTT server address. For a standard build following this guide, the defaults work as-is. After editing config.json, repeat Steps 1 and 2 (Build and Upload Filesystem Image) to push the changes to the device.

## Library and Dependency Installation

All dependencies are declared in platformio.ini and downloaded automatically by PlatformIO when the project is opened. There is nothing to install manually. The key libraries used are:
Library | Purpose
BSEC2 (Bosch) | BME688 sensor — IAQ, eCO2, bVOC calculation
WiFiManager (tzapu) | Captive portal for WiFi provisioning
U8g2 | SSD1306 OLED display rendering
ArduinoJson | JSON parsing for config and MQTT payloads
PubSubClient | MQTT client
LittleFS | Filesystem for config and offline buffer
Preferences | NVS credential storage

## Troubleshooting Tips

Symptom | Likely Cause | Fix
PlatformIO fails to download | No internet or firewall | Check connection, try again
libraries | blocking
Upload fails — port not
found

Wrong COM port or
driver missing

Install CH340 driver, check Device Manager
Device launches captive | NVS credentials not | Complete portal setup and save
portal every boot | saved
bsec_state.bin does not
exist on serial
| LittleFS not uploaded | Run Upload Filesystem Image again
IAQ shows 0, accuracy = 0 | BSEC2 still warming up | Wait ~30 minutes on first boot
Screen blank after flash | timeout_ms not set to 0 in config.json | Edit config.json, re-upload filesystem
MQTT state = -1 after boot | Broker unreachable or | Check server is running, check MQTT
| TLS error | address in config
Offline buffer not clearing | MQTT connection not established

Check WiFi and broker, buffer uploads automatically on reconnect

# Network Configuration

## Connectivity Method

The HIVIS Monitor connects to the network over WiFi (802.11 b/g/n). All communication between the device and the server uses two protocols:

- MQTT over TLS (port 8883) — for sensor data and device provisioning
- HTTP (port 8090) — for OTA firmware updates (LAN only)
There is no Bluetooth, cellular, or Ethernet. The device requires a 2.4GHz WiFi network to operate.

## Wi-Fi Provisioning — First Boot

On first boot, the device has no WiFi credentials saved. It automatically launches a captive portal hotspot named HIVIS-Setup-XXXX (where XXXX is part of the device MAC address).

To configure the device:
1. On your phone or computer, connect to the HIVIS-Setup-XXXX WiFi network
2. A configuration page will open automatically (or browse to 192.168.4.1)
3. Enter your WiFi network name (SSID) and password
4. Enter the MQTT server address (mqtt.hvht.net or your server IP)
5. Click Save

The device will reboot, connect to WiFi, and begin the registration process automatically. Credentials are stored securely in NVS (non-volatile storage) on the ESP32 and persist across reboots and power cycles.
To reconfigure WiFi at any time, long-press the button (GPIO 4) for more than 2 seconds. This relaunches the captive portal without wiping any other settings.

## MQTT

MQTT is a lightweight messaging protocol designed for IoT devices. The HIVIS Monitor uses it to send sensor data to the server and to receive provisioning credentials on first registration.

All MQTT communication is secured with TLS — the connection is encrypted and the device verifies the server certificate before connecting. The broker runs on port 8883.
Topic Structure
Topic | Direction | Purpose
hivis/hivis-[mac]/data | Device → Server | Sensor data, published every 3 seconds
hivis/register | Device → Server Registration request on first boot

hivis/provision/[mac] | Server → Device | Provisioning response — credentials delivered by server

## Sensor Payload

Every 3 seconds the device publishes a JSON packet to its data topic:

The backfill flag is set to true when a reading was recorded offline and is being uploaded after reconnection. The accuracy field reflects the BSEC2 calibration state — values are only reliable at accuracy 1 or higher.

## Device Provisioning Flow

Before a device can publish data, it must be registered with the server. This happens automatically on first boot and only needs to happen once.

Device (unprovisioned)

│ Connects using shared bootstrap credentials

▼

Mosquitto broker → Node-RED

│ Checks device MAC against whitelist

│ Generates unique credentials for this device

│ Adds device to Mosquitto access control

│ Publishes credentials back to device

▼

{

"device_id": "hivis-4cc382c32764",

"device_name": "Device 01",

"ts": | 1710518400,

"ts_accurate": true,

"fw_version": | "2.0.2",
"temp": | 22.5,
"hum": | 45.3,
"iaq": | 75.2,
"co2": | 412,
"bvoc": | 0.52,
"db": | 65.3,
"bat_pct": | 85,
"bat_mv": | 3850,
"rssi": | -45,
"accuracy": | 3,
"backfill": | false

}

Device receives credentials → saves to NVS

│ Reconnects using its own unique credentials

▼

Device is now fully provisioned and publishing data
The device MAC address must be added to the server whitelist before registration is approved. See the section below on adding a new device.

## Server Setup

The server stack runs entirely in Docker on a single Linux host. A low-power machine is sufficient for a small fleet — the reference deployment uses a Lenovo ThinkPad X200 running Ubuntu Server 22.04. The stack consists of 7 containers managed by a single docker-compose.yml:

Container | Purpose | Port
Mosquitto | MQTT broker (TLS) | 8883
Node-RED | Data routing and device provisioning | 1880
InfluxDB 2.x | Time-series database | 8086
Grafana | Dashboards | 3000
OTA server | Firmware update delivery | 8090
Nginx | Public website + InfluxDB proxy | 80, 443
Certbot | SSL certificate auto-renewal | —

To start the server stack:

cd /opt/hivis

docker compose up -d
To check all containers are running:

docker compose ps
All 7 containers should show Up. If any are down:

docker compose up -d <service-name>
Full server configuration, Mosquitto TLS setup, Node-RED flows, and InfluxDB initialization are documented in the operations manual in the project repository.

## Adding a New Device

Every device must be whitelisted on the server before it can register. The MAC address is printed to the serial monitor at boot.

Step 1 — Add the MAC to the Node-RED whitelist:

docker exec hivis-nodered nano /data/whitelist.json"
Add the device to the devices array:

{ "mac": "AA:BB:CC:DD:EE:FF", "authorized": true, "group": "yourgroup", "notes": "Device description" }
Step 2 — Add the MAC to the OTA approved list:

ssh mqttadmin@172.16.1.156 "nano /opt/hivis/ota/devices.json"
Step 3 — Power on the device. It will auto-register and appear in Grafana within one minute.

## Network Reference

The ports below are consistent across any deployment of this system. The IP addresses and domain names are specific to the reference deployment — yours will differ depending on your router and DNS setup.
Service | Address (reference deployment)

Port Notes

Captive portal | 192.168.4.1 | — | Always this address — ESP32 default
MQTT broker | mqtt.hvht.net | 8883 Your domain will differ
Node-RED | 172.16.1.156 | 1880 | LAN only — IP is deployment-specific
InfluxDB | 172.16.1.156 | 8086 LAN only — IP is deployment-specific
Grafana | 172.16.1.156 | 3000 | LAN only — IP is deployment-specific
OTA server | 172.16.1.156 | 8090 LAN only, restricted to local network
Public | hvht.net | 443 | Publicly accessible — your domain will
dashboard | | | differ

For remote server administration, this deployment uses Tailscale — a VPN that allows secure SSH access without exposing port 22 to the internet. Any similar VPN solution works; Tailscale is just what was used here.

## Troubleshooting Tips

Symptom | Likely Cause | Fix
Device loops in captive portal | MQTT server address not saved | Complete portal setup, enter correct server address
MQTT state = -1 after boot | Broker unreachable or TLS error | Check Mosquitto container is running

Symptom | Likely Cause | Fix
Registration rejected | MAC not in whitelist | Add MAC to whitelist.json and retry
Device shows MQTT state = 5 | Stale retained provisioning message | Erase NVS and reboot
No data in Grafana | Node-RED not routing to InfluxDB | Check Node-RED debug panel at port 1880

Captive portal not
appearing

Device already has credentials Long-press button > 2s to relaunch portal

# Data Collection and Usage

## Data Explanation

The HIVIS Monitor collects two categories of data — environmental and system.

Environmental data comes from two sensors:

The Bosch BME688 measures temperature, humidity, and air quality. Using Bosch's BSEC2 algorithm, it produces an IAQ (Indoor Air Quality) score from 0 to 500, an estimated CO₂ equivalent (eCO₂) in ppm, and a breath VOC equivalent (bVOC) in ppm. These are calculated values, not direct measurements — the sensor detects a broad response to volatile organic compounds in the air and uses that alongside temperature, humidity, and pressure to estimate air quality. The sensor requires a burn-in period of approximately 30 minutes on first boot to begin producing reliable readings. Calibration state is saved automatically every 6 hours so subsequent boots do not require the full warmup.

The INMP441 MEMS microphone measures sound pressure level in dB SPL. It samples audio via the I2S interface and calculates a continuous noise level reading. It does not record audio — only the calculated dB value is stored and transmitted.

System data is collected from the ESP32 itself — battery percentage, battery voltage, WiFi signal strength (RSSI), firmware version, and BSEC2 accuracy level.

## Data Format

Before transmission, all sensor readings are assembled into a single JSON packet every 3 seconds:

{

"device_id": "hivis-4cc382c32764",

"device_name": "Device 01",

"ts": | 1710518400,

"ts_accurate": true,

"fw_version": | "2.0.2",
"temp": | 22.5,
"hum": | 45.3,
"iaq": | 75.2,
"co2": | 412,
"bvoc": | 0.52,
"db": | 65.3,
"bat_pct": | 85,

"bat_mv": | 3850,
"rssi": | -45,
"accuracy": | 3,
"backfill": | false

}
The ts field is a Unix timestamp synced via NTP. If the device has no internet connection at the time of recording, ts_accurate is set to false and an approximate timestamp is assigned when the data is uploaded. The backfill flag marks any reading that was stored offline and uploaded later.

On the server side, Node-RED receives the JSON packet, parses it, and writes it to InfluxDB 2.x as a time-series measurement. Each field becomes a separate InfluxDB field, and device_id, device_name, and group are stored as tags for filtering and grouping across multiple devices.

## Data Transmission Protocols

The device uses two protocols:

MQTT over TLS (port 8883) is used for all sensor data and device provisioning. The device publishes a JSON payload to hivis/[device_id]/data every 3 seconds. If the connection drops, readings are saved locally to a LittleFS buffer (up to 500 records) and uploaded automatically when the connection is restored.

HTTP (port 8090) is used exclusively for OTA firmware updates. The device polls the OTA server once every 24 hours, checks if a newer firmware version is available, and applies the update automatically if one exists. This port is restricted to the local network and is not exposed publicly.

## Platform Setup

The HIVIS Monitor is fully self-hosted — there is no third-party cloud service involved. The server running on a local Linux machine is the cloud. All data stays on your own infrastructure.

The server stack is deployed using Docker Compose and consists of Mosquitto, Node-RED, InfluxDB 2.x, Grafana, an OTA server, Nginx, and Certbot. The public dashboard at hvht.net is served by Nginx and queries InfluxDB through a read-only token — no data is sent to any external service.

All software in the stack is free and open source. There are no subscriptions, no API keys to purchase, and no data leaving your network unless you choose to expose it.

Full setup instructions are in the operations manual in the project repository.

## Data Visualization

The system includes three Grafana dashboards, each serving a different purpose:

Fleet Overview refreshes every 30 seconds and shows the status of all active devices at a glance — a table with each device's latest IAQ, CO₂, noise, battery, and online status, plus a multi-device IAQ comparison chart and a battery level overview.

Per-Device refreshes every 5 seconds and shows a single device in real time — live gauges for IAQ, CO₂, noise, battery, and WiFi signal, plus time-series charts for all environmental and system metrics.

Historical refreshes every 5 minutes and covers long-term trends — IAQ, CO₂, temperature, humidity, noise, and battery drain over a selectable time range up to 7 days. Backfill data points are visually marked with a different annotation so they can be distinguished from real-time readings.

The public dashboard at hvht.net provides a simplified view accessible from any browser on any network, using a read-only InfluxDB token embedded in the page.

The three Grafana dashboards are included in the project repository as JSON provisioning files under server/grafana/provisioning/dashboards/. When the Docker stack starts, Grafana loads them automatically — no manual import needed. The repository also includes the datasource configuration and provider settings. Full details are in the project repository at github.com/ranieriv/HIVIS2. All dashboard configuration files and Flux queries are available in the project repository.

All APIs and software used in this system are free and open source. Grafana, InfluxDB, Mosquitto, and Node-RED are all open-source projects with no licensing fees. The InfluxDB query API uses Flux, an open query language. The public dashboard at hvht.net queries InfluxDB directly using a read-only token — no proprietary API or third-party service is involved.

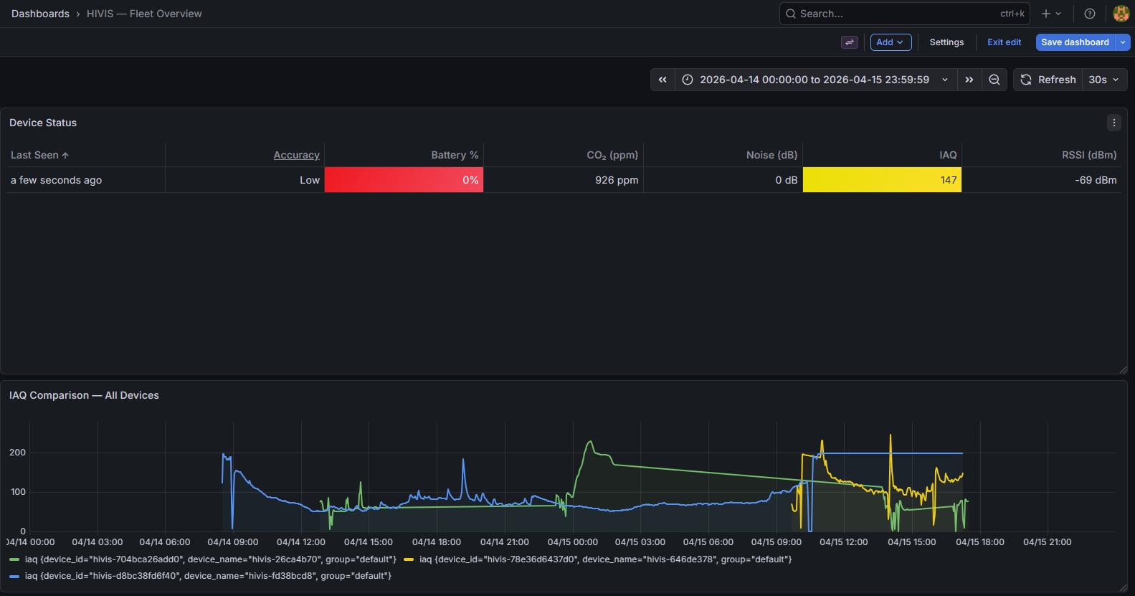
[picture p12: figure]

Figure 9 Grafana Dashboard: Fleet Overview

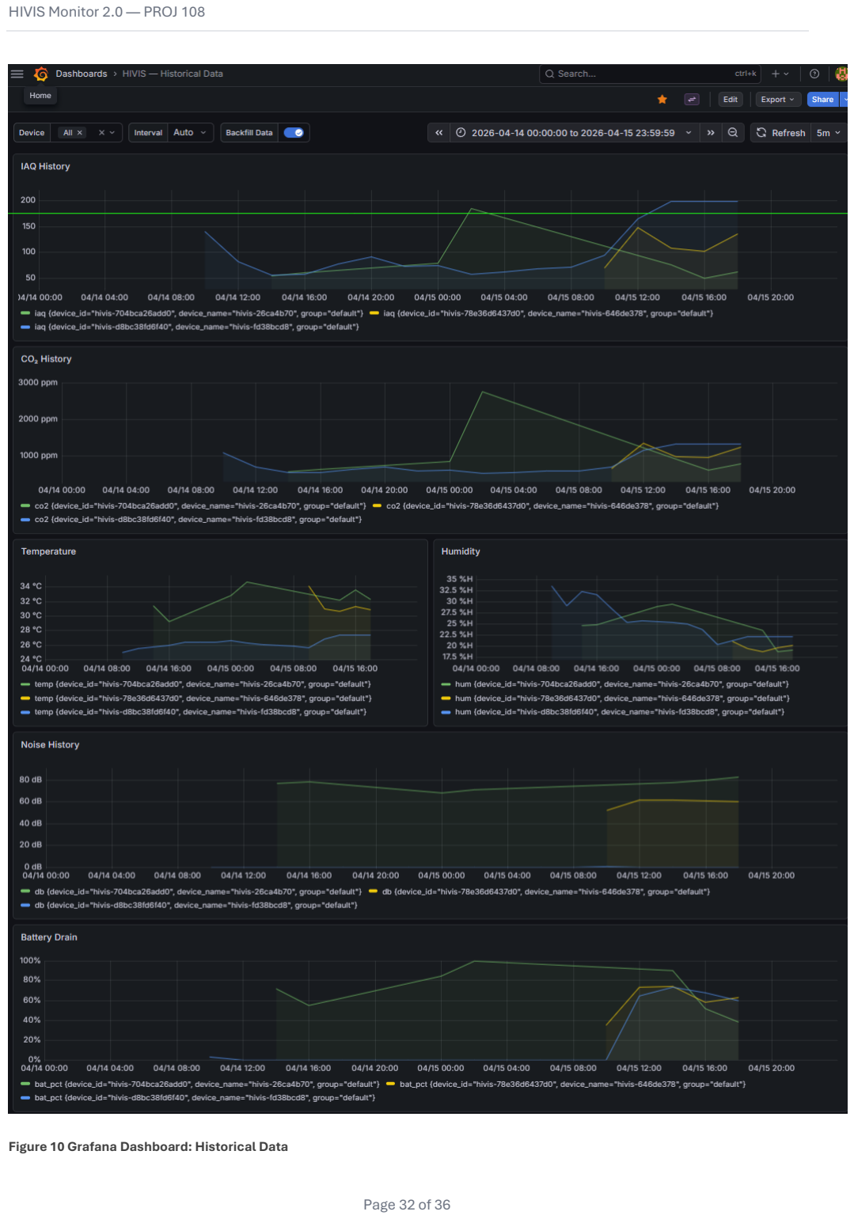
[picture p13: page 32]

Figure 10 Grafana Dashboard: Historical Data

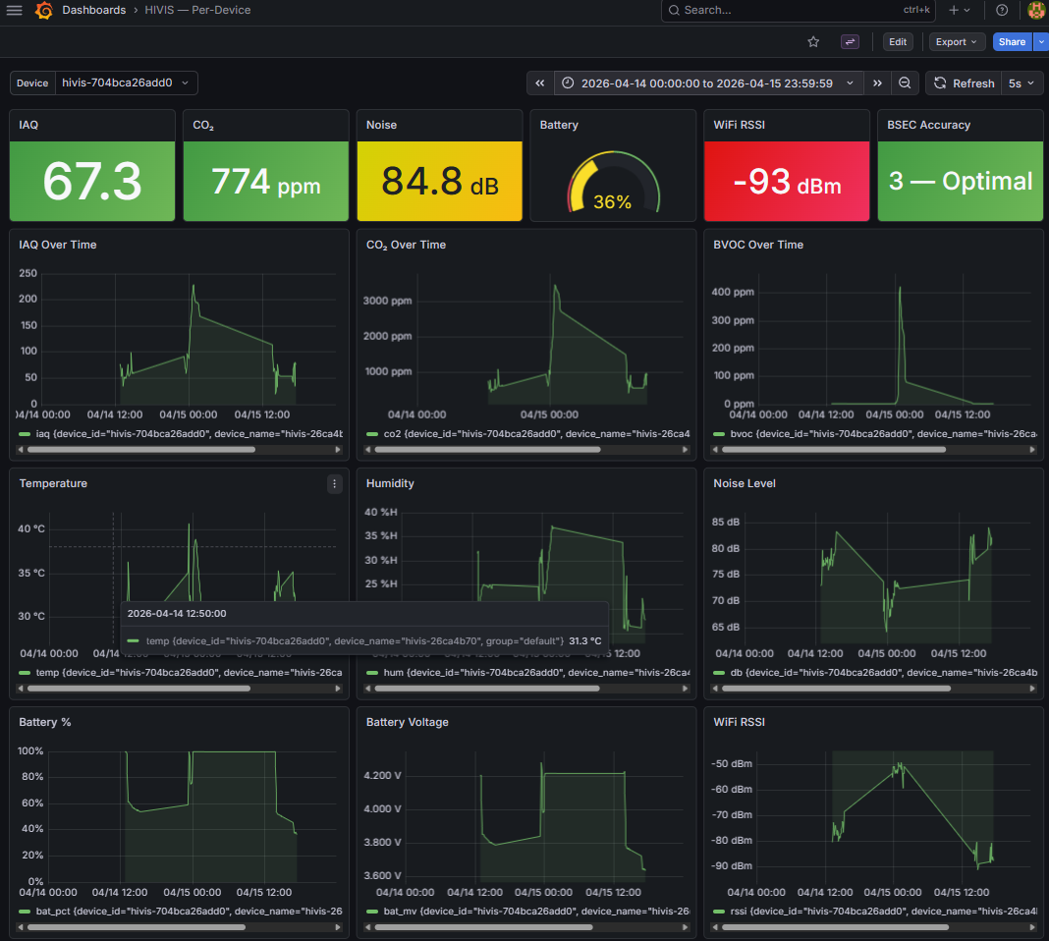
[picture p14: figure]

Figure 11 Grafana Dashboard: Per Device

## Current Applications

The device was deployed at Saskatchewan Polytechnic during April 2026 as a real-world validation of the system. Three devices ran simultaneously across different locations, collecting continuous air quality and noise data over a 15-day period.

The results were significant. CO₂ levels exceeded the ASHRAE recommended threshold of 800 ppm on 9 out of 11 monitored days. The single worst event recorded was a CO₂ reading of 4,228 ppm and an IAQ score of 500 — the absolute sensor ceiling — on April 5 at 16:39 CST. On April 13, all three devices simultaneously recorded elevated readings, with one hitting 1,984 ppm CO₂ and an IAQ of 178 during occupied hours.

Before the HIVIS Monitor was deployed, none of this was visible to anyone in the building. Nobody knew those conditions existed. That is exactly the gap the device is designed to fill — not to replace certified safety equipment, but to give people data they currently have none of. A worker or supervisor who can see a CO₂ spike in real time has a reason to act. Without that data, there is no reason to act at all.
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

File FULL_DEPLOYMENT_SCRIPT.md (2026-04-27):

# HIVIS Monitor — Website Deployment Guide

Deploy the HIVIS live dashboard to **hvht.net** on the X200 server (&lt;SERVER_IP&gt;).
All website files live in `server/` in this repo — copy them to the X200 and run the steps below.

---

## Pre-Flight Checklist

Run on X200 before starting:

```bash
# InfluxDB must already be running (existing stack)
curl http://localhost:8086/health

# Check current public IP (needed for DNS)
curl -s ifconfig.me && echo

# Docker running?
docker ps

# Note docker-compose version (use 'docker compose' if v2)
docker compose version || docker-compose --version
```

---

## Step 1 — Copy repo files to X200

From your dev machine (adjust SSH target as needed):

```bash
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

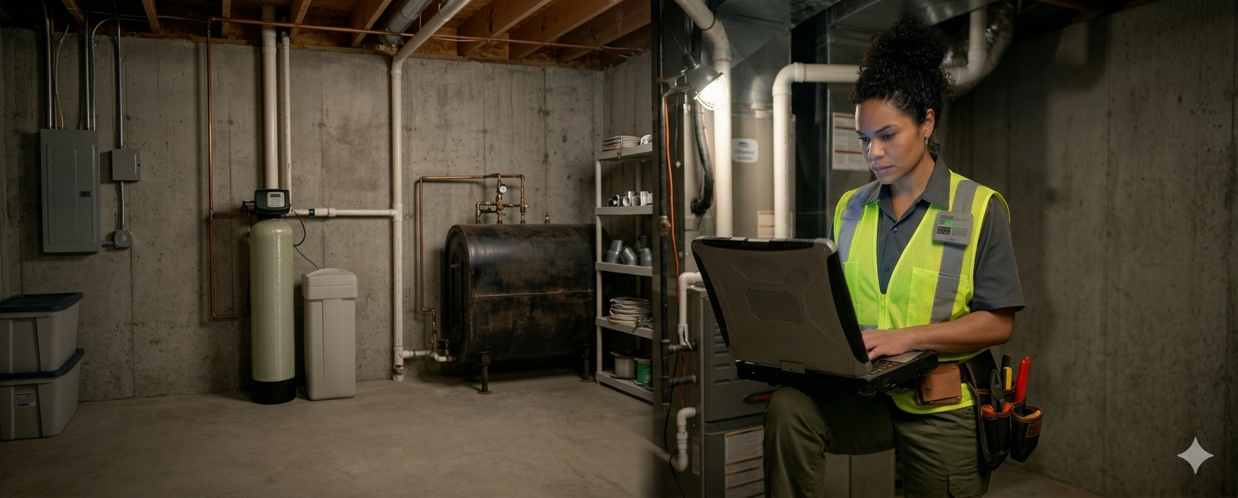
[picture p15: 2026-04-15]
server/website/images/HIVIS_Worker_Extended.png

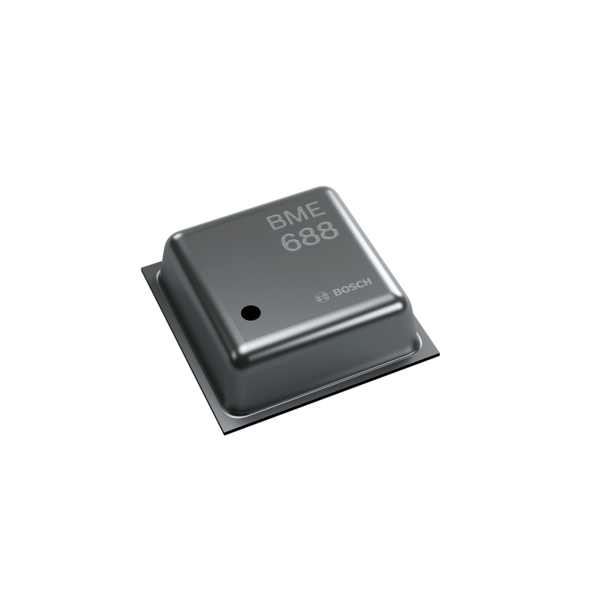
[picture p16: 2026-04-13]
server/website/images/bme688.png

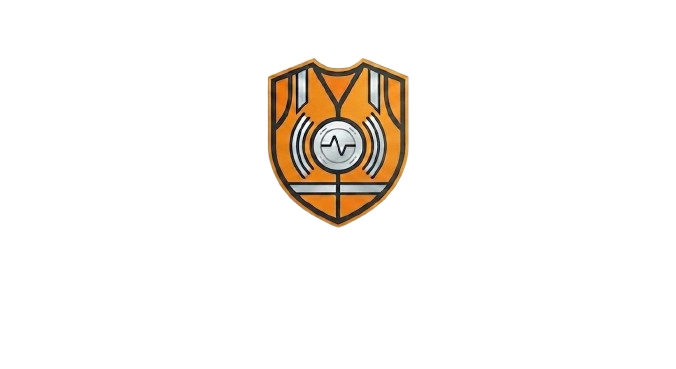
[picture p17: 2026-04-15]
server/website/images/ShieldHIVIS-r.png

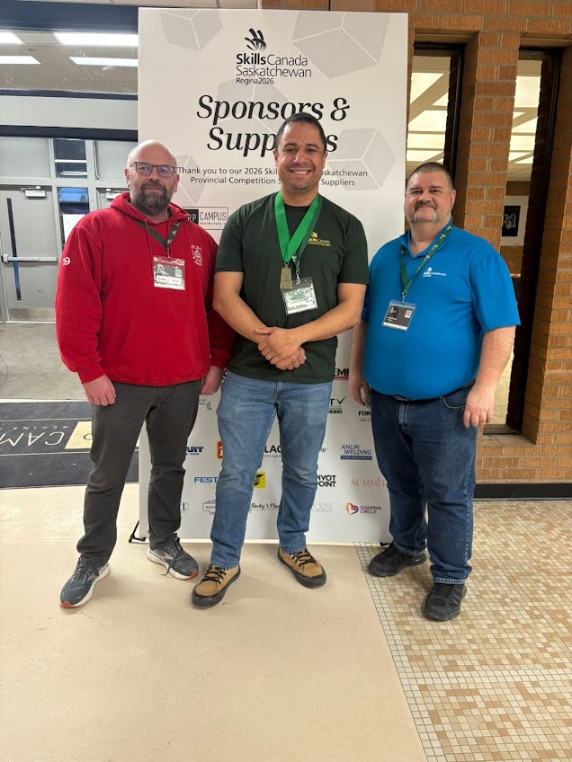
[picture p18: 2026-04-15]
server/website/images/Skills.jpg

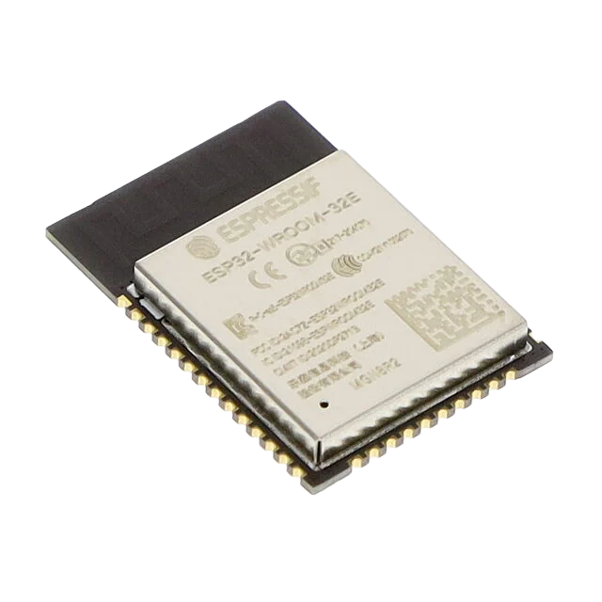
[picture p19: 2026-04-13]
server/website/images/esp32.png

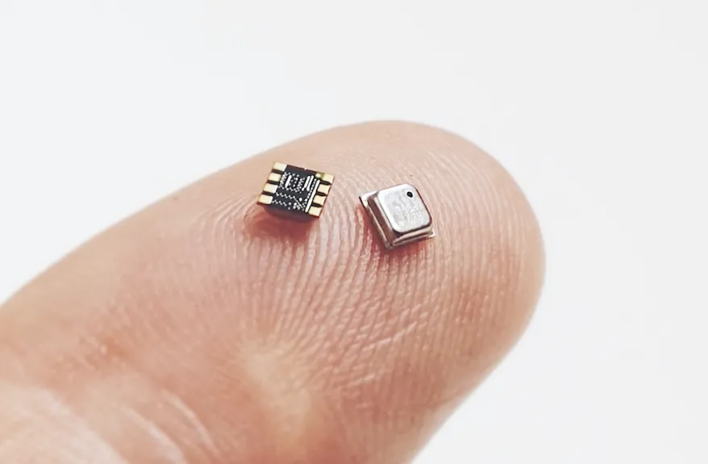
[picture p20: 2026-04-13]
server/website/images/BME688fingerbg.png

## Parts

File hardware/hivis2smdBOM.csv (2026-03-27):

Id | Designator | Footprint | Quantity | Designation | Supplier and ref
1 | R5 | R_0402_1005Metric | 1 | 220
2 | R4,R3 | R_0402_1005Metric | 2 | 100K
3 | R2,R1 | R_0402_1005Metric | 2 | 4.7K
4 | C2,C1 | C_0402_1005Metric | 2 | 100nF
5 | U1 | ESP32_30pin | 1 | ~
6 | SW1 | SW_PUSH_6mm | 1 | SW_Push
7 | BZ1 | Buzzer_TDK_PS1240P02BT_D12.2mm_H6.5mm | 1 | Buzzer
8 | J4 | J5019_Module | 1 | J5019_Module
9 | J5 | JST_PH_B2B-PH-K_1x02_P2.00mm_Vertical | 1 | BATT JST
10 | J1 | BME688_Breakout_7pin | 1 | BME_688_Module
11 | J2 | INMP441_Breakout_8mm | 1 | INMP_441
12 | J3 | OLED_SSD1306_27x27 | 1 | OLED Display

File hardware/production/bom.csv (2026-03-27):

Designator | Footprint | Quantity | Value | LCSC Part #
BZ1 | Buzzer_TDK_PS1240P02BT_D12.2mm_H6.5mm | 1 | Buzzer
C1, C2 | 0402 | 2 | 100nF
J1 | BME688_Breakout_7pin | 1 | BME_688_Module
J2 | INMP441_Breakout_8mm | 1 | INMP_441
J3 | OLED_SSD1306_27x27 | 1 | OLED Display
J4 | J5019_Module | 1 | J5019_Module
J5 | JST_PH_B2B-PH-K_1x02_P2.00mm_Vertical | 1 | BATT JST
R1, R2 | 0402 | 2 | 4.7K
R3, R4 | 0402 | 2 | 100K
R5 | 0402 | 1 | 220
SW1 | SW_PUSH_6mm | 1 | SW_Push
U1 | ESP32_30pin | 1 | ~

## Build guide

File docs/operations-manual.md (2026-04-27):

# HIVIS Monitor 2.0 — Operations Manual

**Version:** 2.0.2
**Server:** &lt;SERVER_IP&gt; (ssh mqttadmin@&lt;SERVER_IP&gt; or ssh mqttadmin@mqttserver)
**Grafana:** http://&lt;SERVER_IP&gt;:3000 — credentials in docs/credentials.md
**Public dashboard:** https://hvht.net

---

## Quick Check (2–3 minutes)

Run this whenever you want to confirm the system is alive.

### QC-1 · Docker containers running

```bash
ssh mqttadmin@&lt;SERVER_IP&gt; "cd /opt/hivis && docker compose ps"
```

**Expected:** All 7 containers show `Up` (or `running`).

| Container | Status |
|---|---|
| hivis-mosquitto | Up |
| hivis-nodered | Up |
| hivis-influxdb | Up |
| hivis-grafana | Up |
| hivis-ota | Up |
| hivis-nginx | Up |
| hivis-certbot | Up |

**If a container is down:**
```bash
cd /opt/hivis && docker compose up -d <service-name>
```

---

### QC-2 · Public dashboard (https://hvht.net)

1. Open https://hvht.net in any browser (works from external networks)
2. Device cards should appear within 10 seconds showing live sensor readings
3. Click a card → charts should render with 1h/6h/24h range options
4. Check for the SSL padlock — certificate is valid

**If cards don't appear:** jump to Full Check → FC-5.

---

### QC-3 · Grafana shows live data (LAN only)

1. Open http://&lt;SERVER_IP&gt;:3000
2. Go to **Fleet Overview** dashboard (`/d/hivis-fleet`)
3. Confirm your device appears in the table with a timestamp within the last 10 seconds

**If the table is empty:** jump to Full Check → FC-5.

---

### QC-4 · Device serial output (if device is connected to PC)

Open PlatformIO serial monitor at 115200 baud. You should see lines like:

```
IAQ:75.2 Hum:45.3% Temp:22.5°C CO2:412 BVOC:0.52 dB:65.3 Acc:3 Bat:85%(3.85V) ONLINE
```

**Green flags:**
- `ONLINE` at end of each line
- `Acc:` is 1, 2, or 3 (not 0 — 0 = still calibrating)
- No `MQTT state=-1` or `state=5` errors

**If you see `OFFLINE`:** check WiFi and proceed to FC-3.

---

### QC-5 · OLED display

The device OLED should show sensor readings continuously (no blank screen).
Press the button (GPIO 4) briefly to cycle through the 3 pages:
- Page 0: IAQ + CO₂ + noise
- Page 1: Temp + Humidity + BVOC
- Page 2: WiFi SSID + battery + server connection status

If the screen is blank: `timeout_ms` in config.json must be 0 (always-on). See Full Check → FC-7.

---

## Full Check

Run this after making changes, after a server reboot, or when something isn't working.

---

### FC-1 · Server health — all services

```bash
ssh mqttadmin@&lt;SERVER_IP&gt; "cd /opt/hivis && docker compose ps && docker compose logs --tail=20"
```

Check for error lines in each service log. Common problems:

| Log pattern | Meaning | Fix |
|---|---|-----|
| `Connection refused` in nodered | InfluxDB/Mosquitto not ready | `docker compose restart nodered` |
| `address already in use` | Port conflict | `docker compose down && docker compose up -d` |
| `permission denied /mosquitto/config` | Volume mount issue | Check ownership: `ls -la /opt/hivis/mosquitto/config/` |

---

### FC-2 · Mosquitto MQTT broker

**Test broker is accepting TLS connections:**
```bash
ssh mqttadmin@&lt;SERVER_IP&gt; \
  "docker exec hivis-mosquitto mosquitto_sub \
     --cafile /mosquitto/certs/ca.crt \
     -h mqtt.hvht.net -p 8883 \
     -u nodered_bridge -P <nodered_bridge_password> \
     -t 'hivis/#' -C 1 --quiet -W 5"
```

**Expected:** Receives one message within 5 seconds (if a device is publishing).

**Check Mosquitto log for recent connections:**
```bash
ssh mqttadmin@&lt;SERVER_IP&gt; "tail -50 /opt/hivis/mosquitto/log/mosquitto.log"
```

Look for:
- `New client connected` lines for your device (e.g., `device_4cc382c32764`)
- No `CONNREFUSED` for `nodered_bridge`

**Check active ACL (who can connect):**
```bash
ssh mqttadmin@&lt;SERVER_IP&gt; "cat /opt/hivis/mosquitto/config/acl"
```

Your provisioned device should have an entry like:
```
user device_4cc382c32764
topic write hivis/hivis-4cc382c32764/#
topic read  hivis/provision/4cc382c32764
```

---

### FC-3 · WiFi / network path from device

On device serial monitor, immediately after boot, confirm:
```
6. Connecting WiFi... OK (192.168.x.x)
```

If WiFi fails:
1. Long-press GPIO 4 (> 2 s) to launch reconfigure portal
2. Connect phone/PC to `HIVIS-Setup-XXXX` hotspot
3. Browse to 192.168.4.1 — enter correct WiFi SSID/password and MQTT server
4. Save and wait for device reboot

---

### FC-4 · Device provisioning check

On device serial, confirm provisioning completes:
```
7. Registering device with server...
Registration: waiting for server response (30s)...
Registration: approved — user=device_XXXX  id=hivis-XXXX
```

If you see `REJECTED` or no response after 30 s:

1. Check whitelist:
```bash
ssh mqttadmin@&lt;SERVER_IP&gt; "docker exec hivis-nodered cat /data/whitelist.json"
```

2. Add device MAC if missing (whitelist lives inside the Node-RED container):
```bash
ssh mqttadmin@&lt;SERVER_IP&gt; "docker exec hivis-nodered nano /data/whitelist.json"
# Add to the "devices" array:
# { "mac": "AA:BB:CC:DD:EE:FF", "authorized": true, "group": "saskpoly", "notes": "Room X" }
```

3. Erase NVS to force re-registration (closes serial monitor first!):
```bash
python -m esptool --port COM7 erase_region 0x9000 0x5000
```

---

### FC-5 · InfluxDB data pipeline

**Step A — Check InfluxDB is receiving data:**
```bash
ssh mqttadmin@&lt;SERVER_IP&gt; \
  "docker exec hivis-influxdb influx query \
     --org hivis \
     --token <influx-admin-token> \
     'from(bucket:\"hivis\") |> range(start:-5m) |> limit(n:3)'"
```

**Expected:** 3 rows with fields like `iaq`, `temp`, `co2`.

**Step B — Check Node-RED is routing data:**

1. Open http://&lt;SERVER_IP&gt;:1880
2. Look at the `MQTT In` node — the green dot should be `connected`
3. Click **Deploy** if any nodes show orange (pending changes)
4. Look for the debug panel on the right — it shows warnings/errors from function nodes

Common Node-RED errors and fixes:

| Error | Cause | Fix |
|---|---|-----|
| `MQTT: connection refused` | nodered_bridge password wrong | Re-check Mosquitto passwd file |
| `global.get('http') is null` | settings.js missing http entry | Add `http: require("http")` to functionGlobalContext and restart |
| `No measurement specified` | InfluxDB function node using wrong format | `msg.measurement` must be set before InfluxDB out node |

---

### FC-6 · Grafana datasource health

1. Open http://&lt;SERVER_IP&gt;:3000
2. Go to **Connections → Data sources → InfluxDB**
3. Scroll to bottom → click **Save & Test**

**Expected:** `datasource connected and 3 buckets found`

If it fails:
- Check InfluxDB token in the datasource config matches the one in InfluxDB
- Verify InfluxDB container is up: `docker compose ps`
- Check InfluxDB URL is `http://hivis-influxdb:8086` (Docker network name, not localhost)

---

### FC-7 · Nginx website + SSL

**Check HTTPS is reachable and serving the dashboard:**
```bash
curl -I https://hvht.net
# Expected: HTTP/2 200, server: nginx/...
```

**Check HTTP redirects to HTTPS:**
```bash
curl -I http://hvht.net
# Expected: 301 → https://hvht.net
```

**Check SSL certificate expiry:**
```bash
echo | openssl s_client -servername hvht.net -connect hvht.net:443 2>/dev/null \
  | openssl x509 -noout -dates
# notAfter should be 2026-07-12 or later (certbot renews automatically)
```

**Check InfluxDB proxy through Nginx (no auth error = proxy works):**
```bash
curl -s -o /dev/null -w "%{http_code}" \
  -X POST "https://hvht.net/api/v2/query?org=hivis" \
  -H "Authorization: Token <website-readonly-token>" \
  -H "Content-Type: application/vnd.flux" \
  -d 'from(bucket:"hivis") |> range(start:-1m) |> limit(n:1)'
# Expected: 200
```

**If Nginx is down:**
```bash
ssh mqttadmin@mqttserver "cd /opt/hivis && docker compose up -d nginx"
docker logs hivis-nginx --tail 30   # check for config errors
```

**If SSL cert is missing or expired:**
```bash
# Force renewal manually
ssh mqttadmin@mqttserver "docker exec hivis-certbot certbot renew --force-renewal"
docker exec hivis-nginx nginx -s reload
```

**Common nginx permission problem (passwd file):**
```bash
# If Mosquitto crashes with exit code 13 after any sudo operation:
ssh mqttadmin@mqttserver "docker run --rm --user root \
  -v /opt/hivis/mosquitto/config:/mosquitto/config \
  eclipse-mosquitto:latest chmod 644 /mosquitto/config/passwd"
cd /opt/hivis && docker compose up -d mosquitto
```

---

### FC-8 · OTA server

**Check version endpoint:**
```bash
curl http://&lt;SERVER_IP&gt;:8090/ota/version?mac=4cc382c32764
```

**Expected output:** `2.0.2` (or current firmware version)

**Check firmware file exists:**
```bash
ssh mqttadmin@&lt;SERVER_IP&gt; "ls -lh /opt/hivis/ota/firmware/"
```

**Expected:**
```
latest.bin    (> 500 KB)
version.txt
```

**Check OTA log from server:**
```bash
ssh mqttadmin@&lt;SERVER_IP&gt; "docker logs hivis-ota --tail=30"
```

Look for `GET /ota/version` and `POST /provision` entries.

---

### FC-9 · Display / OLED always-on check

Verify `config.json` has `timeout_ms` set to 0:

In PlatformIO serial monitor, after boot:
```
1. Loading config... OK
```

Check LittleFS config with:
```bash
# Open serial monitor, trigger a factory reset to re-upload config.json
# Or verify the file directly in the project:
cat data/config.json | grep timeout
```

Expected: `"timeout_ms": 0`

If screen keeps going off: rebuild and re-upload filesystem:
```bash
pio run --target uploadfs
```

---

### FC-10 · BSEC2 calibration status

BSEC2 takes ~30 minutes to reach accuracy 3 on first boot. After that, calibration is saved to `/littlefs/bsec_state.bin` every 6 hours.

On serial monitor:
```
IAQ:75.2 ... Acc:3 ...    ← fully calibrated, values reliable
IAQ:25.0 ... Acc:0 ...    ← still warming up, IAQ not meaningful yet
```

**If `bsec_state.bin does not exist` error appears in serial:**
- The LittleFS filesystem may not have been uploaded
- Fix: `pio run --target uploadfs` (uploads `data/` folder to device)

After calibration file is saved, reboots skip the 30-minute warmup.

---

### FC-11 · End-to-end data flow verification

This confirms data flows all the way from sensor to Grafana.

1. **Device** publishes to `hivis/hivis-[mac]/data` every 3 seconds
2. **Mosquitto** receives and routes to `nodered_bridge` subscriber
3. **Node-RED** parses JSON → sets `msg.measurement`, `msg.tags`, `msg.payload` → writes to InfluxDB
4. **InfluxDB** stores in `hivis` bucket, `air_quality` and `device_status` measurements
5. **Grafana** queries InfluxDB, displays on Fleet Overview dashboard

**Verify each hop:**

```bash
# Hop 1-2: Mosquitto receiving device data
ssh mqttadmin@&lt;SERVER_IP&gt; "tail -f /opt/hivis/mosquitto/log/mosquitto.log"
# Should see publish lines every 3s

# Hop 3: Node-RED processing (check debug panel in UI at :1880)

# Hop 4: InfluxDB storing data
ssh mqttadmin@&lt;SERVER_IP&gt; \
  "docker exec hivis-influxdb influx query --org hivis --token <token> \
   'from(bucket:\"hivis\") |> range(start:-1m) |> count()'"

# Hop 5: Grafana (open browser)
```

---

## Deploying a New Firmware Version

```bash
# 1. Edit platformio.ini — bump version number
#    -DFIRMWARE_VERSION='"2.0.2"'

# 2. Build
pio run

# 3. Upload binary to server
scp .pio/build/esp32doit-devkit-v1/firmware.bin \
    mqttadmin@&lt;SERVER_IP&gt;:/opt/hivis/ota/firmware/latest.bin

# 4. Update version file on server
ssh mqttadmin@&lt;SERVER_IP&gt; "echo '2.0.2' > /opt/hivis/ota/firmware/version.txt"

# 5. Verify OTA endpoint
curl http://&lt;SERVER_IP&gt;:8090/ota/version?mac=4cc382c32764
# → 2.0.2

# Device will pick up the new version on next boot (if > 24h since last OTA check)
# Or erase NVS ota_last_chk key to force immediate check:
#   python -m esptool --port COM7 erase_region 0x9000 0x5000
```

---

## Adding a New Device

```bash
# 1. Get the device MAC from serial monitor (printed at boot):
#    MAC=4C:C3:82:C3:27:64  → use lowercase no-colon form: 4cc382c32764

# 2. Add to whitelist inside the Node-RED container
ssh mqttadmin@&lt;SERVER_IP&gt; "docker exec hivis-nodered nano /data/whitelist.json"
# Add to the "devices" array:
# { "mac": "4C:C3:82:C3:27:64", "authorized": true, "group": "saskpoly", "notes": "Room 102" }

# 3. Add to OTA approved list
ssh mqttadmin@&lt;SERVER_IP&gt; "nano /opt/hivis/ota/devices.json"
# Add to the "devices" object:
# "4cc382c32764": { "ota_approved": true, "notes": "Room 102 — 4C:C3:82:C3:27:64" }

# 4. Power on device — it will auto-register and appear in Grafana within 1 minute
```

---

## Common Problems — Quick Reference

| Symptom | Most Likely Cause | Fix |
|---|---|-----|
| Device shows `MQTT state=5` on every boot | Stale retained provisioning message | Erase NVS (0x9000) and reboot |
| Device shows `MQTT state=-1` | WiFi OK but MQTT broker unreachable | Check Mosquitto container, TLS cert |
| Device loops in captive portal | `mqttServer` empty in NVS | Complete portal setup, save |
| Grafana shows no data | InfluxDB write failing | Check Node-RED debug, check FC-5 |
| `No measurement specified` in Node-RED | InfluxDB node format wrong | Set `msg.measurement` in function node |
| OTA check returns version `-1` | OTA server down or MAC not in devices.json | Check FC-7, add MAC to devices.json |
| `bsec_state.bin` error | LittleFS not uploaded | `pio run --target uploadfs` |
| IAQ always shows 0, Acc=0 | BSEC2 warming up | Wait 30 minutes, accuracy will reach 1+ |
| Screen blank / display off | `timeout_ms` non-zero | Set `timeout_ms: 0` in config.json, re-upload FS |
| Factory reset triggered accidentally | GPIO 4 held > 5s during boot | Avoid pressing GPIO 4 at boot |
| `fetch is not defined` in Node-RED | Node-RED doesn't expose global fetch | Use `global.get('http')` with functionGlobalContext |
| Mosquitto exits with code 13 | `passwd` file owned by root (unreadable) | `docker run --rm --user root -v /opt/hivis/mosquitto/config:/mosquitto/config eclipse-mosquitto:latest chmod 644 /mosquitto/config/passwd` |
| https://hvht.net shows 502 | InfluxDB container down | `docker compose up -d influxdb` |
| https://hvht.net shows stale data | MQTT/Node-RED pipeline interrupted | Check FC-5, FC-11 |

---

## Key Credentials

See `docs/credentials.md` (gitignored — not committed to repo).

| Service | Username | Where to find password |
|---|---|---|
| Grafana | `admin` | docs/credentials.md |
| MQTT bootstrap | `hivis_bootstrap` | docs/credentials.md |
| SSH server | `mqttadmin` | SSH key auth |
| InfluxDB admin | `admin` | docs/credentials.md |
| InfluxDB website token | *(read-only)* | docs/credentials.md |

---

*Last updated: 2026-04-13 · HIVIS Monitor 2.0.2*

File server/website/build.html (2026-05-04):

HIVIS Monitor Logo HIVIS Monitor 2.0

Connecting…

From breadboard to wearable IoT device

# The Build Journal

A complete record of how HIVIS Monitor was designed, prototyped, rebuilt, and shipped — hardware, firmware, and infrastructure.

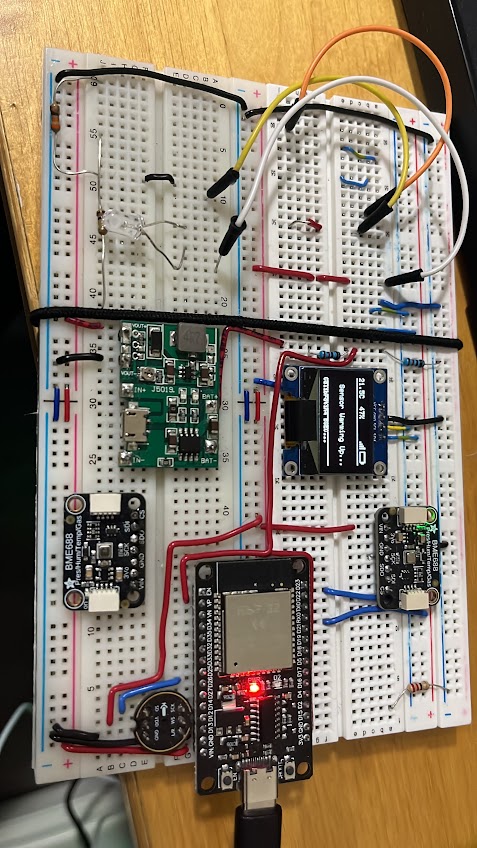
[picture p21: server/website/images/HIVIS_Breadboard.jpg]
Breadboard prototype
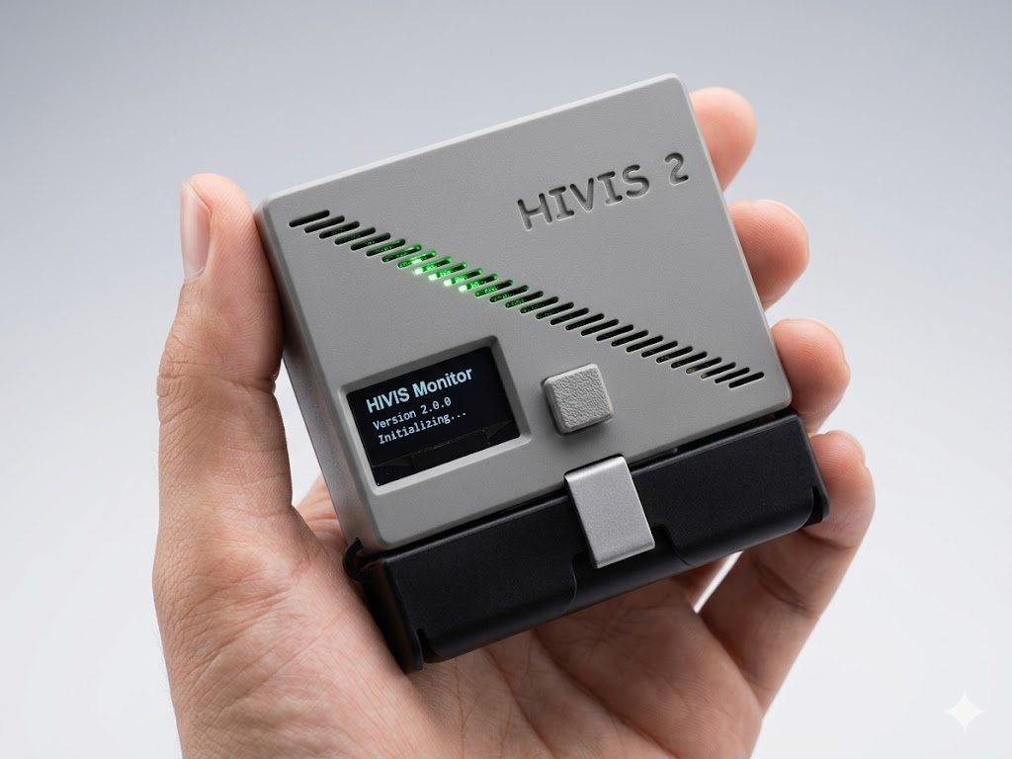
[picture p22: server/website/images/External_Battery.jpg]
HIVIS 2 final
 HIVIS V1 PCB Version with battery HIVIS Monitor V1 enclosure 

01

Phase 1 · Hardware

## Proof of Concept

Start with what you have. Prove the idea works.

### The Question That Started It

Working near furnaces and in basements, I kept wondering: is the air around me safe? Commercial IAQ monitors exist — but they're expensive, cloud-dependent, and designed for offices. Not for the worker with tools on their belt.

The first step was proving that affordable sensors could give meaningful readings. Everything started on a breadboard: an ESP32 DoIt DevKit V1, a Bosch BME688 air quality sensor, an INMP441 MEMS microphone for sound level, an SSD1306 OLED display, and a J5019 charger/boost module for battery power.

"eCO₂ gives a ventilation picture, bVOC gives a chemical exposure picture, and both combine into the IAQ score as a single actionable number on the OLED."

### Key Components

MCU | ESP32 DoIt DevKit V1 (30-pin)
Air Quality | Bosch BME688 — temp, humidity, pressure, gas (MOX)
Acoustics | INMP441 I2S MEMS microphone
Display | SSD1306 0.96" OLED (I2C)
Power | J5019 charger/boost + LiPo battery

Full breadboard prototype with all components wired

First prototype — all components on breadboard

02

Phase 2 · Hardware

## HIVIS Monitor V1

Moving off the breadboard. First real form factor.

HIVIS V1 custom PCB close-up

Custom perfboard layout — first permanent assembly

### From Prototype to Device

The breadboard proved the concept. The next step was making it a real device — something that could be worn, powered from a battery, and used on a job site.

Version 1 moved from loose jumper wires to a structured layout on a prototyping board. This is where the physical design language started taking shape: small footprint, OLED facing up for quick glance reads, single button for all interactions.

### V1 Lessons

The red button was too large. The battery connector was awkward. The board was thicker than it needed to be. But the core system — sensor, display, button, buzzer — worked exactly as intended. V1 validated the form factor.

V1 with battery attached showing live OLED readings

V1 powered up — OLED showing live IAQ, eCO₂, sound data

03

Phase 3 · Firmware

## Firmware Architecture

WiFi provisioning, encrypted credentials, OTA updates, offline buffering.

### Design Principles

The firmware was built around one clear rule: separate secrets from configuration. Credentials (WiFi, MQTT) live in an AES-128 CBC encrypted credentials.json. All hardware parameters live in a plain config.json that field technicians can adjust.

### Key Features

Provisioning | WiFiManager captive portal — first boot
Security | AES-128 CBC encrypted credentials + SecureVault
Connectivity | MQTT over TLS, auto local/external server switching
Offline | LittleFS NDJSON buffering with approximate timestamps
OTA | HTTP polling with per-device approval flag
UI | Single button — short / long / double / 5s-hold gestures
Calibration | BSEC2 NVS persistence across reboots

### The Button Gesture System

One of the most interesting firmware challenges was building a complete UI with a single tactile button. Short press, long press, double press, and a 5-second hold — each triggers a distinct action with a unique piezo tone. Users cycle through display screens, trigger manual uploads, or enter provisioning mode without ever connecting a computer.

"The gap between planning and actually getting things done — HIVIS Monitor taught me why both matter equally."

### Sensor Intelligence

The BME688 uses Bosch's BSEC2 library for intelligent gas sensing. Because it's a metal oxide sensor, it can't selectively detect specific gases like H₂S or CO — it responds to a broad range of volatile compounds. This is a known limitation, not a flaw. The IAQ score reflects air quality broadly, not a specific chemical concentration.

04

Phase 4 · Infrastructure

## Server Stack

Self-hosted. Privacy-first. Runs on a repurposed ThinkPad.

### The Philosophy

Commercial IoT platforms send your data to a cloud you don't control. HIVIS Monitor runs entirely on a self-hosted server — a Lenovo ThinkPad X200 on Ubuntu Server, running the full stack in Docker containers.

Data flows from the ESP32 → MQTT broker → Node-RED → InfluxDB, then displayed in Grafana. Remote access via Tailscale. External MQTT with TLS. Nightly backups to OneDrive via rclone.

### Stack

Mosquitto

MQTT broker — TLS on port 8883

Transport

Node-RED

Data pipeline & routing

Processing

InfluxDB 2.x

Time-series database

Storage

Grafana

3 dashboards — per-device, fleet, historical

Visualization

Tailscale

Secure remote access

Networking

rclone

Nightly OneDrive backup, 7-day retention

Backup

### The Dashboards

Three Grafana dashboards are provisioned and available live at hvht.net:

Per-Device | 5s refresh · individual device readings, trends
Fleet | 30s refresh · all devices, overview status
Historical | 5m refresh · long-term exposure analysis

"There's a reason certified sensors cost what they do. Building this taught me how complete systems are actually made."

05

Phase 5 · PCB Design

## Custom PCB

KiCad 8. 70×50mm 2-layer board. Fabricated by JLCPCB.

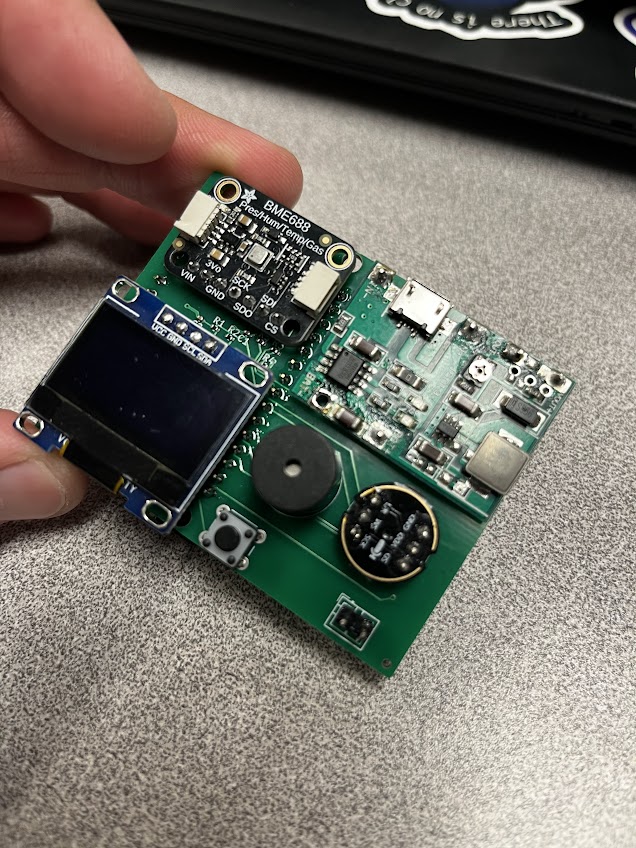
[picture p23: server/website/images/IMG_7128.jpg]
Custom PCB bare board


Custom 70×50mm 2-layer PCB — all components placed

### Why Design a PCB

Prototyping boards work — but they're thick, fragile, and hard to reproduce. A custom PCB meant a device that could be manufactured consistently, fitted precisely into a printed enclosure, and assembled with SMD components.

The board was designed in KiCad 8 with ESP32 on the back copper layer and all other components on the front. JLCPCB handled both bare fabrication and SMD assembly of passive components.

### PCB Specs

Size | 70 × 50 mm
Layers | 2 (F.Cu + B.Cu)
MCU | ESP32 DoIt DevKit on B.Cu
Design Tool | KiCad 8 + FreeRouting autorouter
Fabrication | JLCPCB (bare PCB + SMD assembly)

Early PCB version

Early PCB iteration

PCB with battery live

PCB powered, live data

Final custom board

Final board layout

06

Phase 6 · Final Device

## HIVIS Monitor 2.0

Multi-device fleet. 3D-printed enclosure. Showcase ready.

3D printing the custom enclosure

### From One to Many

HIVIS Monitor 2.0 is not just a better device — it's a scalable system. The architecture supports up to 10 simultaneous devices, each publishing to the same server, each visible in the fleet dashboard with its own device ID.

The enclosure is 3D-printed. The board is custom-fabricated. The firmware handles first-boot provisioning, encrypted credentials, automatic network switching, OTA updates, and offline buffering without any user configuration beyond the initial captive portal setup.

### Showcase Demo

The May 4th showcase will run three active devices over a phone hotspot, all reporting live to the server. Visitors can see real readings — IAQ scores, eCO₂ ppm, bVOC, temperature, humidity, pressure, sound level — on the fleet dashboard and per-device cards.

HIVIS Monitor 2.0 final device

HIVIS 2.0 — final form factor, 3D-printed enclosure

HIVIS 2.0 showing live readings on OLED

Live readings: IAQ 51 · eCO₂ 505ppm · 75.3 dB

## See it live.

The full fleet dashboard is running right now at hvht.net — real devices, real data.

View Live Dashboard → About Rani GitHub (https://github.com/ranieriv)

© 2026 HIVIS Monitor Project

Saskatchewan Polytechnic A Saskatchewan Polytechnic (https://saskpolytech.ca) Applied Research project · 2026

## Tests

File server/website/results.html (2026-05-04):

HIVIS Monitor Logo HIVIS Monitor 2.0

Applied Research · Saskatchewan Polytechnic · 2026

# Research Results

HIVIS Monitor — Applied Research Student Showcase 2026

Rani dos Santos Vilela · May 4, 2026

Research Questions

RQ1 — Feasibility

### Can the system be built?

Is it feasible to develop a low-cost, self-hosted wearable IoT sensor system — battery powered and continuously connected to a real-time server — capable of monitoring indoor and outdoor air quality, temperature, and noise levels in trades workplace environments?

RQ2 — Reliability

### Does it perform in the real world?

If feasible, does such a system perform reliably when deployed in real-world conditions?

Fleet Overview — Mar 25 – May 3, 2026

812,717

Valid Readings

742 hrs

Monitoring Hours

3

Devices Deployed

40 days

Longest Continuous Run

843.6 ppm

Fleet Mean CO₂

110.4

Fleet Mean IAQ

17 of 33

Days Avg CO₂ Above 800 ppm

Mar 25
– May 3

Study Period

RQ1 — Feasibility

## Can the System Be Built?

✓ Yes — Feasibility Confirmed

System Built & Deployed

3 physical devices designed, assembled, and deployed. Custom 2-layer PCB fabricated via JLCPCB. Firmware deployed via OTA updates. WiFiManager provisioning required no firmware changes per device.

Data Transmission

812,717 valid readings captured. Fixed device: 62.6% delivery rate over 40 days. Mobile devices operated intermittently by design — low overall delivery rate reflects planned deployment, not system failure.

Battery Performance

Mobile devices sustained 4–5 hours per charge at workplace drain rates (~21.5%/hr). Firmware v2.0.2 introduced screen timeout: −1.64%/hr drain reduction confirmed on fixed device.

Note: One device excluded from all analysis — confirmed BSEC2 calibration failure producing frozen readings. Disclosed as a system limitation.

Workplace Air Quality — Mobile Devices

## Trades Workplace Findings

Mobile devices carried during telecom service shifts in Regina, SK · Mon–Thu 16:30–20:30 / Sat 08:00–16:00 CST

### Mobile-A 12,395 readings · Apr 11–25

Metric | Mean | Min | Max
IAQ (0–500) | 114.6 | 0.1 | 500
CO₂ (ppm) | 1,083.7 | 400 | 4,080
Temperature (°C)* | 28.0 | 20.0 | 36.3
Humidity (%) | 26.2 | 15.3 | 51.6
Sound (dB SPL) | 82.2 | 50.0 | 111.8

* Enclosed device — ~+1.3°C upward bias from ESP32 heat.

CO₂ > 800 ppm: 77.5% CO₂ > 1,000 ppm: 50.0% CO₂ > 1,100 ppm: 34.0% IAQ > 100: 57.8%

### Mobile-B 899 readings · Apr 15 (single session)

1,219.3 Mean CO₂ (ppm)

1,085–1,372 CO₂ Range (ppm)

1,372 ppm Peak CO₂ @ 17:15 CST

133.4 Mean IAQ

CO₂ > 1,000 ppm: 100% of readings

Limited dataset — one session only. Results are notable but not generalisable.

1,000 ppm CO₂ has been linked to a moderate decline in decision-making performance.
Satish et al. (2012). Is CO₂ an indoor pollutant? Direct effects of low-to-moderate CO₂ concentrations on human decision-making performance. Environmental Health Perspectives, 120(12), 1671–1677.

CO₂ by Day — Mobile-A

## CO₂ by Day of Week

Average CO₂ concentration per working day

Mon

1,199 ppm worst

Wed

864 ppm

Sat

1,033 ppm

Friday excluded — devices left at home, not representative of workplace conditions.

Outdoor Detection

## Automatic Outdoor Detection

The system identified outdoor conditions with no configuration required.

127

Readings below 500 ppm during workplace hours

440 ppm

Mean outdoor CO₂ (near-atmospheric)

Outdoor readings clustered at shift transitions:

08:30 Saturday
shift start

15:00 Saturday
shift end

16:30–17:00 Weekday
shift arrival

No GPS, no manual tagging — the sensor responded to real environmental changes.

Educational Deployment — Fixed Device

## System Validation

Fixed device · Saskatchewan Polytechnic · 40 days continuous · 693,316 readings

Metric | Mean | Min | Max
IAQ (0–500) | 114.1 | 0.3 | 500
CO₂ (ppm) | 835.8 | 400 | 4,228
Temperature (°C) | 25.5 | — | 30.5
Humidity (%) | 17.4 | 10.4 | 76.0

This device did not include a microphone. Noise data is from mobile devices only.

Peak CO₂: 4,228 ppm on April 5 — IAQ reached sensor ceiling of 500.

Cost Context

## Why Cost Matters

### HIVIS Monitor

$73 CAD 18650 battery build

- $90 CAD — LiPo 2100 mAh build
- 5-device fleet: ~$365–$450
- No calibration required
- No subscription
- Self-hosted, open firmware

### Consumer NDIR CO₂ Monitor

$150–$300 per unit

- Fixed location only
- Cloud subscription often required
- No noise monitoring
- No fleet management

### Certified 4-Gas Industrial Monitor

$400–$600+ per unit

- Annual calibration required
- 5-device fleet: $2,000–$3,000+
- Required for safety-critical detection

The HIVIS Monitor is not a replacement for certified instruments. It is an auxiliary — giving workers and supervisors visibility into conditions that were previously invisible, at a cost that makes fleet deployment realistic.

Limitations

## Limitations

- eCO₂ is estimated via MOX sensor (BME688), not measured by NDIR. Values are indicators, not certified measurements.
- BME688 cannot detect specific gases such as H₂S or CO. Safety-critical detection requires dedicated electrochemical sensors.
- One device excluded due to BSEC2 calibration failure (frozen readings).
- Mobile-B has only one valid workplace session (899 readings). Results are notable but limited in scope.
- Temperature readings from enclosed mobile devices carry ~+1.3°C upward bias due to ESP32 heat.
- Battery life ~4–5 hours per charge. Mobile-B depleted to 0% twice during the study.
- Real-time alerts require active Wi-Fi. No alerts during offline periods.

Research Paper

## Full Report

Full applied research report — HIVIS Monitor, Applied Research Student Showcase 2026, Saskatchewan Polytechnic. Includes full methodology, raw data analysis, firmware development log, and complete findings.

Download Full Report (PDF)

© 2026 HIVIS Monitor Project

Saskatchewan Polytechnic A Saskatchewan Polytechnic (https://saskpolytech.ca) Applied Research project · 2026

SDG 3 · SDG 8 · SDG 9

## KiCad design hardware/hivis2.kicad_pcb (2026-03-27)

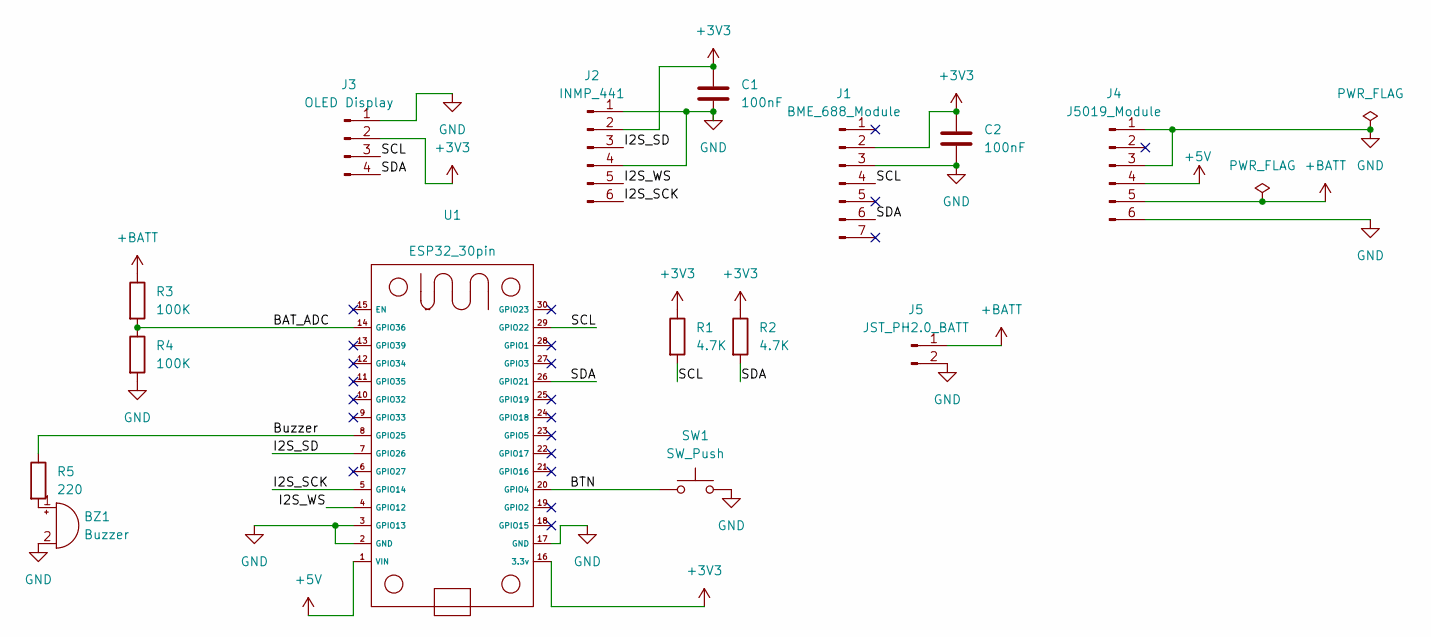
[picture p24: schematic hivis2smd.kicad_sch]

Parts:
BZ1: Buzzer; Buzzer_TDK_PS1240P02BT_D12.2mm_H6.5mm
C1, C2: 100nF; C_Disc_D5.0mm_W2.5mm_P5.00mm
J1: BME_688_Module; BME688_Breakout_7pin
J2: INMP_441; INMP441_Breakout_8mm
J3: OLED Display; OLED_SSD1306_27x27
J4: J5019_Module
J5: JST_PH2.0_BATT; JST_PH_B2B-PH-K_1x02_P2.00mm_Vertical
R1, R2: 4.7K; R_Axial_DIN0204_L3.6mm_D1.6mm_P7.62mm_Horizontal
R3, R4: 100K; R_Axial_DIN0204_L3.6mm_D1.6mm_P7.62mm_Horizontal
R5: 220; R_Axial_DIN0204_L3.6mm_D1.6mm_P7.62mm_Horizontal
SW1: SW_Push; SW_PUSH_6mm
U1: ESP32_30pin

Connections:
+3V3: C1.1, C2.1, J1.2, J2.2, J3.2, R1.1, R2.1, U1.16 (3.3v)
+5V: J4.4, U1.1 (VIN)
+BATT: J4.5, J5.1, R3.1
/BAT_ADC: R3.2, R4.1, U1.14 (GPIO36)
/BTN: SW1.1, U1.20 (GPIO4)
/Buzzer: R5.1, U1.8 (GPIO25)
/I2S_SCK: J2.6, U1.5 (GPIO14)
/I2S_SD: J2.3, U1.7 (GPIO26)
/I2S_WS: J2.5, U1.4 (GPIO12)
/SCL: J1.4, J3.3, R1.2, U1.29 (GPIO22)
/SDA: J1.6, J3.4, R2.2, U1.26 (GPIO21)
GND: BZ1.2 (-), C1.2, C2.2, J1.3, J2.1, J2.4, J3.1, J4.1, J4.3, J4.6, J5.2, R4.2, SW1.2, U1.2 (GND), U1.3 (GPIO13), U1.17 (GND)
unnamed: BZ1.1 (+), R5.2

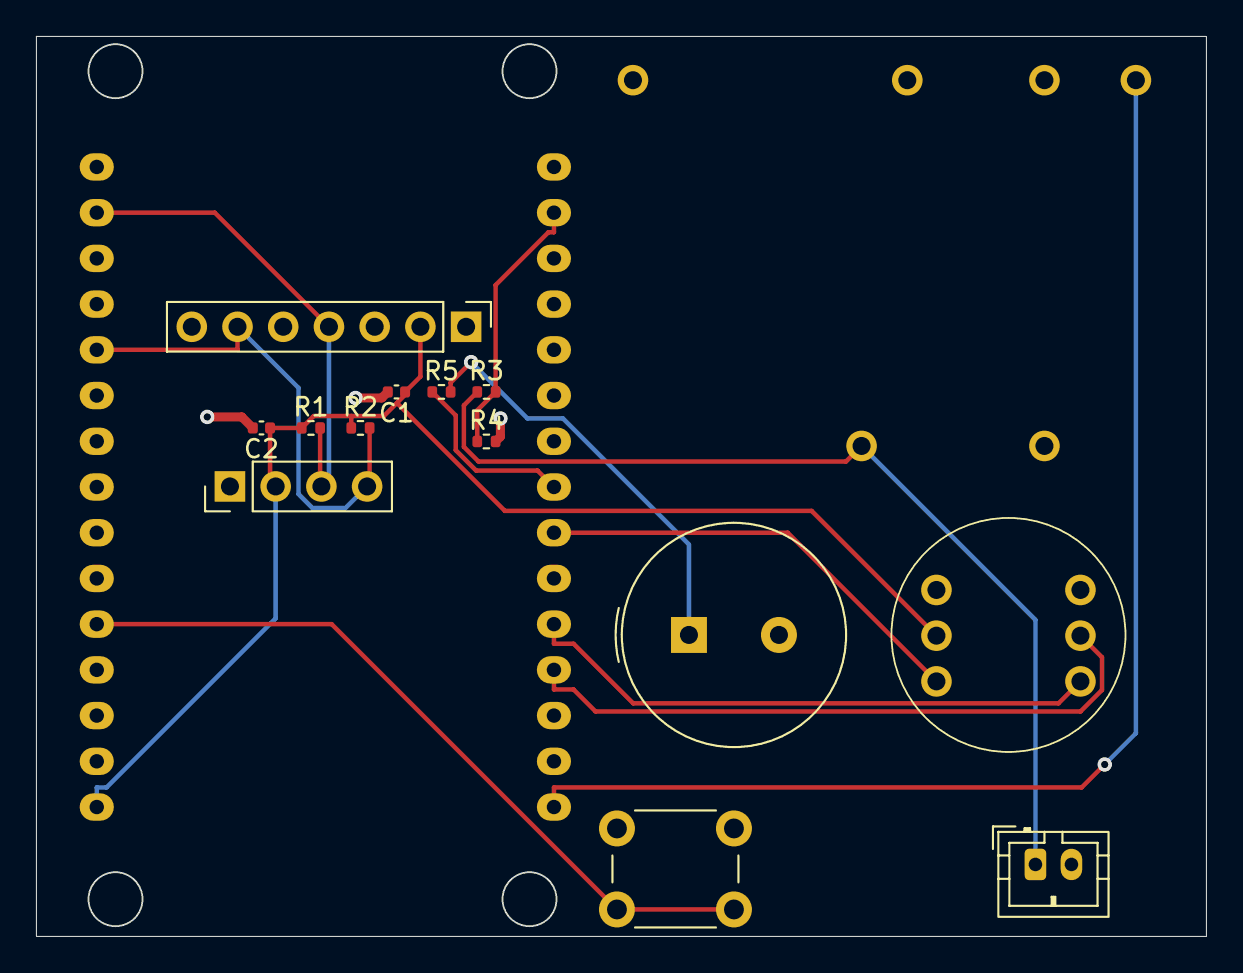
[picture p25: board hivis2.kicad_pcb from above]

Board: 2 copper layers, 65.0 x 50.0 mm, 15 parts (1 on the bottom side), 13 nets.

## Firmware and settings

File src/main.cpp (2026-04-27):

#include <Arduino.h>
#include <WiFi.h>
#include <time.h>

#include "ConfigHandler.h"
#include "BME688Module.h"
#include "MicModule.h"
#include "DisplayModule.h"
#include "MqttModule.h"
#include "ButtonModule.h"
#include "BuzzerModule.h"
#include "OTAModule.h"
#include "PortalModule.h"
#include "OfflineBuffer.h"

// ── Globals ───────────────────────────────────────────────────────────────────
DeviceConfig   cfg;
BME688Module*  bme    = nullptr;
MicModule*     mic    = nullptr;
DisplayModule* oled   = nullptr;
MqttModule*    mqtt   = nullptr;
ButtonModule*  button = nullptr;
BuzzerModule*  buzzer = nullptr;

bool online    = false;
bool wasOnline = false;

int   lastBatPrc = -1;
float lastBatV   = 0.0f;


// ── MAC helpers ───────────────────────────────────────────────────────────────

static String getMacAddress() {
    uint8_t mac[6];
    esp_read_mac(mac, ESP_MAC_WIFI_STA);
    char buf[18];
    snprintf(buf, sizeof(buf), "%02X:%02X:%02X:%02X:%02X:%02X",
             mac[0], mac[1], mac[2], mac[3], mac[4], mac[5]);
    return String(buf);
}

static String getMacHex() {
    // Lowercase, no colons — used for provision topic
    String m = getMacAddress();
    m.toLowerCase();
    m.replace(":", "");
    return m;
}

// ── Battery ───────────────────────────────────────────────────────────────────

static void readBattery() {
    int raw = 0;
    for (int i = 0; i < 16; i++) raw += analogRead(cfg.batteryPin);
    raw /= 16;

    float v   = (raw / 4095.0f) * 3.3f * cfg.batteryMultiplier;
    int   prc = (int)map(
        constrain((int)(v * 100), cfg.batteryMinMv, cfg.batteryMaxMv),
        cfg.batteryMinMv, cfg.batteryMaxMv, 0, 100
    );

    if (lastBatPrc < 0) {
        lastBatPrc = prc;
        lastBatV   = v;
    } else if (abs(prc - lastBatPrc) >= 2) {
        lastBatPrc = prc;
        lastBatV   = v;
    }
}

// ── WiFi ──────────────────────────────────────────────────────────────────────

// WiFiManager stored WiFi creds in its namespace — reconnect with no args
static bool tryConnectWifi(int timeoutMs = 10000) {
    WiFi.mode(WIFI_STA);
    WiFi.begin(); // reconnect to last saved network (WiFiManager's creds)
    unsigned long t = millis();
    while (millis() - t < (unsigned long)timeoutMs) {
        if (WiFi.status() == WL_CONNECTED && WiFi.localIP() != IPAddress(0, 0, 0, 0))
            return true;
        delay(200);
    }
    return false;
}

static bool syncNtp(int timeoutMs = 5000) {
    configTime(0, 0, "pool.ntp.org", "time.nist.gov");
    unsigned long t = millis();
    while (time(nullptr) < 1000000000UL && millis() - t < (unsigned long)timeoutMs) {
        delay(200);
    }
    return time(nullptr) >= 1000000000UL;
}

// ── Registration (MQTT-based) ─────────────────────────────────────────────────

// Received provision response storage (written by MQTT callback)
static volatile bool provisionReceived = false;
static String        provisionStatus   = "";
static String        provisionUser     = "";
static String        provisionPass     = "";
static String        provisionId       = "";

static void onMqttMessage(const String& topic, const String& payload) {
    Serial.printf("MQTT RX [%s]: %s\n", topic.c_str(), payload.c_str());

    // Check if this is a provision response
    String expected = MqttModule::provisionTopic(getMacHex());
    if (topic != expected) return;

    JsonDocument doc;
    if (deserializeJson(doc, payload) != DeserializationError::Ok) return;

    provisionStatus = doc["status"] | "";
    provisionUser   = doc["mqtt_user"]   | "";
    provisionPass   = doc["mqtt_pass"]   | "";
    provisionId     = doc["device_id"]   | "";
    provisionReceived = true;
}

// Register with server via MQTT. Returns true if provisioned successfully.
static bool registerDevice() {
    Serial.println("Registration: connecting to broker (bootstrap)...");

    // Bootstrap connection — shared low-privilege account for unregistered devices
    // IMPORTANT: Change this password before deploying. Update Mosquitto passwd file to match.
    MqttModule bootstrap(cfg.mqttServer, cfg.mqttPort,
                         "hivis_bootstrap", "CHANGE_ME_BOOTSTRAP_PASS",
                         cfg.deviceId, cfg.deviceName);
    bootstrap.setMessageCallback(onMqttMessage);

    if (!bootstrap.connect()) {
        Serial.println("Registration: broker unreachable.");
        return false;
    }

    // Subscribe to provision response topic
    String provTopic = MqttModule::provisionTopic(getMacHex());
    bootstrap.subscribe(provTopic, 1);
    // Flush any retained message from a previous registration so we don't
    // mistake it for the server's response to THIS registration request.
    for (int i = 0; i < 5; i++) { bootstrap.loop(); delay(100); }
    provisionReceived = false;

    // Publish registration
    bootstrap.publishRegister(getMacAddress(), cfg.deviceName);

    // Wait up to 30 seconds for server response
    Serial.println("Registration: waiting for server response (30s)...");
    unsigned long deadline = millis() + 30000UL;
    while (!provisionReceived && millis() < deadline) {
        bootstrap.loop();
        delay(100);
    }

    if (!provisionReceived) {
        Serial.println("Registration: no response — offline mode, retry next boot.");
        return false;
    }

    if (provisionStatus != "approved") {
        Serial.println("Registration: REJECTED by server.");
        oled->wake();
        // Show rejection on display briefly
        buzzer->beepError();
        return false;
    }

    // Save provisioned credentials
    cfg.mqttUser   = provisionUser;
    cfg.mqttPass   = provisionPass;
    cfg.deviceId   = provisionId.isEmpty() ? cfg.deviceId : provisionId;
    saveNVSProvisioned(cfg.mqttUser, cfg.mqttPass, cfg.deviceId);

    Serial.printf("Registration: approved — user=%s  id=%s\n",
                  cfg.mqttUser.c_str(), cfg.deviceId.c_str());
    buzzer->beepConnected();
    return true;
}

// ── Setup ─────────────────────────────────────────────────────────────────────
void setup() {
    Serial.begin(115200);
    delay(500);
    Serial.println("\n=== HIVIS Monitor 2.0 ===");
    Serial.flush();

    // 1. LittleFS + config.json
    Serial.print("1. Loading config... ");
    Serial.flush();
    loadConfig(cfg);
    // Verify LittleFS is writable; reformat if not (can happen after crash loop)
    {
        File t = LittleFS.open("/.wcheck", "w");
        if (!t) {
            Serial.println("LittleFS not writable — reformatting...");
            LittleFS.format();
            LittleFS.begin();
            loadConfig(cfg); // reload config.json after reformat
        } else {
            t.close();
            LittleFS.remove("/.wcheck");
        }
    }
    Serial.println("OK");
    Serial.flush();

    // 2. Hardware init
    Serial.print("2. Init hardware... ");
    Wire.begin(21, 22);

    oled = new DisplayModule();
    oled->begin();
    oled->setTimeoutMs(cfg.displayTimeoutMs);

    buzzer = new BuzzerModule(cfg.buzzerPin);
    buzzer->begin();
    if (!cfg.buzzerEnabled) buzzer->setMuted(true);

    button = new ButtonModule(cfg.buttonPin, cfg.longPressMs, cfg.doublePressMs);
    button->begin();
    Serial.println("OK");

    // 3. Splash
    oled->showSplash();
    oled->wake();

    // 4. Load NVS credentials/identity
    loadNVS(cfg);
    Serial.printf("   MAC=%s  deviceId=%s  server=%s\n",
                  getMacAddress().c_str(), cfg.deviceId.c_str(), cfg.mqttServer.c_str());

    // 5. First boot: no WiFi stored yet → run captive portal
    {
        // WiFiManager stores network in its own namespace. Try a quick connect first.
        WiFi.mode(WIFI_STA);
        WiFi.begin();
        delay(1000);
        bool hasSavedNetwork = (WiFi.SSID().length() > 0);

        if (!hasSavedNetwork || cfg.mqttServer.isEmpty()) {
            {
                Serial.println("3. First boot — launching captive portal...");
                PortalModule portal;
                portal.begin();
                oled->showPortal(portal.getApSsid().c_str());
                if (portal.runFirstBoot()) {
                    portal.saveToNVS();
                    cfg.deviceName = portal.getDeviceName();
                    cfg.mqttServer = portal.getMqttServer();
                } else {
                    Serial.println("Portal: timed out — continuing in offline mode.");
                    buzzer->beepError();
                    if (cfg.deviceName.isEmpty()) cfg.deviceName = deriveDeviceId();
                }
            }
        }
    }

    // 6. Init sensors (before WiFi so BSEC starts warming up)
    Serial.print("4. Init BME688... ");
    bme = new BME688Module(cfg.bmeAddr, cfg.bsecSaveIntervalH);
    Serial.println(bme->begin() ? "OK" : "FAILED (no sensor data)");

    Serial.print("5. Init microphone... ");
    mic = new MicModule(cfg.micWS, cfg.micSCK, cfg.micSD, cfg.micLR, cfg.micCal);
    mic->begin();
    Serial.println("OK");

    // 7. Connect WiFi
    Serial.print("6. Connecting WiFi... ");
    online = tryConnectWifi(15000);
    if (online) {
        Serial.printf("OK (%s)\n", WiFi.localIP().toString().c_str());
        buzzer->beepConnected();
        syncNtp();
    } else {
        Serial.println("FAILED — entering offline mode.");
    }

    // 8. Provision MQTT credentials if not yet done
    if (online && !isProvisioned()) {
        Serial.println("7. Registering device with server...");
        if (registerDevice()) {
            // Give Mosquitto time to reload passwd after SIGHUP before we connect
            Serial.println("   Waiting for broker reload...");
            delay(6000);
        }
    }

    // 9. Connect MQTT with real credentials (if provisioned)
    if (online && isProvisioned() && !cfg.mqttUser.isEmpty()) {
        mqtt = new MqttModule(
            cfg.mqttServer, cfg.mqttPort,
            cfg.mqttUser, cfg.mqttPass,
            cfg.deviceId, cfg.deviceName,
            cfg.mqttKeepaliveS
        );
        mqtt->setMessageCallback(onMqttMessage);
        mqtt->connect();

        // Flush any offline data
        int buffered = OfflineBuffer::count();
        if (buffered > 0) {
            Serial.printf("9. Flushing %d offline records...\n", buffered);
            OfflineBuffer::flush(*mqtt, time(nullptr), cfg.mqttIntervalMs,
                                 cfg.deviceId, cfg.deviceName);
        }
    }

    // 10. OTA check (every boot + every 24h)
    if (online) {
        uint32_t lastOtaCheck = loadOtaLastCheck();
        uint32_t now = (time(nullptr) > 1000000000UL)
                           ? (uint32_t)time(nullptr)
                           : (uint32_t)(millis() / 1000);
        uint32_t intervalS = (uint32_t)cfg.otaCheckIntervalH * 3600UL;
        bool doOta = (lastOtaCheck == 0 || (now - lastOtaCheck) >= intervalS);

        if (doOta) {
            Serial.println("8. Checking OTA...");
            OTAModule ota("http://" + cfg.mqttServer + ":8090",
                          cfg.deviceId, getMacHex(), FIRMWARE_VERSION);
            ota.begin();
            ota.checkAndUpdate(); // reboots if update applied
        }
    }

    buzzer->beepReady();
    wasOnline = online; // prevent false "WiFi: reconnected" on first loop
    Serial.println("=== SYSTEM READY ===");
}

// ── Loop ──────────────────────────────────────────────────────────────────────
void loop() {
    bme->update();
    button->update();

    if (mqtt) {
        mqtt->loop();

        // If broker keeps rejecting our credentials, re-provision after 5 minutes.
        // Capped at 5 reboots to prevent infinite reboot loops.
        static unsigned long authFailSince = 0;
        if (!mqtt->isConnected() && mqtt->lastState() == 5) {
            if (authFailSince == 0) authFailSince = millis();
            if (millis() - authFailSince >= 5UL * 60UL * 1000UL) {
                int cnt = loadAuthRebootCount();
                if (cnt >= 5) {
                    Serial.printf("MQTT: auth failure — reboot limit reached (%d). "
                                  "Staying offline, long-press to reconfigure.\n", cnt);
                    authFailSince = millis(); // reset timer, keep trying periodically
                } else {
                    Serial.printf("MQTT: persistent auth failure (5 min) — clearing credentials, "
                                  "rebooting... (attempt %d/5)\n", cnt + 1);
                    buzzer->beepError();
                    delay(1000);
                    incrementAuthRebootCount();
                    clearNVS();
                    ESP.restart();
                }
            }
        } else {
            authFailSince = 0;
            if (mqtt->isConnected()) clearAuthRebootCount();
        }
    }

    // WiFi reconnect watchdog
    bool nowOnline = (WiFi.status() == WL_CONNECTED &&
                      WiFi.localIP() != IPAddress(0, 0, 0, 0));
    if (nowOnline && !wasOnline) {
        Serial.println("WiFi: reconnected.");
        buzzer->beepConnected();
        syncNtp();
        if (mqtt) {
            mqtt->connect();
            int buffered = OfflineBuffer::count();
            if (buffered > 0) {
                Serial.printf("Flushing %d buffered records...\n", buffered);
                OfflineBuffer::flush(*mqtt, time(nullptr), cfg.mqttIntervalMs,
                                     cfg.deviceId, cfg.deviceName);
            }
        }
    }
    online    = nowOnline;
    wasOnline = nowOnline;

    // ── Refresh tick ──────────────────────────────────────────────────────────
    static unsigned long lastRefresh = 0;
    if (millis() - lastRefresh >= (unsigned long)cfg.refreshMs) {
        lastRefresh = millis();

        readBattery();

        DisplayData data = {};
        data.temp        = bme->getTemp();
        data.hum         = bme->getHum();
        data.iaq         = bme->getIAQ();
        data.co2         = bme->getCO2();
        data.bvoc        = bme->getVOC();
        data.db          = mic->readDB();
        data.accuracy    = bme->getAccuracy();
        data.batteryPrc  = (lastBatPrc < 0) ? 0 : lastBatPrc;
        data.batteryV    = lastBatV;
        data.rssi        = online ? WiFi.RSSI() : 0;
        data.serverConnected = (mqtt && mqtt->isConnected());
        data.ssid        = WiFi.SSID().c_str();
        data.deviceName  = cfg.deviceName.c_str();

        if (button->factoryReset()) {
            Serial.println("BTN: factory reset — wiping NVS...");
            buzzer->beepError();
            delay(500);
            clearNVS();
            ESP.restart();
        }

        if (button->longPressed()) {
            Serial.println("BTN: long press — reconfiguring...");
            buzzer->beepShort();
            PortalModule portal;
            portal.begin();
            oled->showPortal(portal.getApSsid().c_str());
            portal.runReconfigure();
            portal.saveToNVS();
            cfg.deviceName = portal.getDeviceName();
            cfg.mqttServer = portal.getMqttServer();
        }

        if (button->doublePressed()) {
            Serial.println("BTN: double press — muting alert.");
            buzzer->stopAlert();
        }

        if (button->shortPressed()) {
            Serial.println("BTN: short press — next page.");
            oled->nextPage();
            buzzer->beepShort();
        }

        // Alert logic
        if (data.accuracy > 0) {
            if (data.iaq >= cfg.iaqAlert) {
                if (!buzzer->isMuted()) buzzer->startDanger();
            } else if (data.iaq >= cfg.iaqWarn) {
                if (!buzzer->isMuted()) buzzer->startWarning();
            } else {
                buzzer->stopAlert();
            }
        }

        buzzer->update();
        oled->update(data, cfg.iaqWarn, cfg.iaqAlert);

        // ── MQTT publish tick ──────────────────────────────────────────────────
        static unsigned long lastMqtt        = 0;
        static unsigned long lastOfflineStore = 0;
        time_t ts = time(nullptr);
        bool tsAccurate = (ts >= 1000000000UL);

        if (online && mqtt && mqtt->isConnected()) {
            if (millis() - lastMqtt >= (unsigned long)cfg.mqttIntervalMs) {
                lastMqtt = millis();
                mqtt->publishSensor(data, ts, tsAccurate);
            }
        } else {
            if (millis() - lastOfflineStore >= 60000UL) {
                lastOfflineStore = millis();
                OfflineBuffer::store(data);
            }
        }

        Serial.printf("IAQ:%.1f Hum:%.1f%% Temp:%.1f°C CO2:%.0f BVOC:%.2f "
                      "dB:%.1f Acc:%d Bat:%d%%(%.2fV) %s\n",
                      data.iaq, data.hum, data.temp, data.co2, data.bvoc,
                      data.db, data.accuracy,
                      data.batteryPrc, data.batteryV,
                      online ? "ONLINE" : "OFFLINE");
    }

    delay(1);
}

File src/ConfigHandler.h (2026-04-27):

#pragma once
#include <Arduino.h>
#include <ArduinoJson.h>
#include <LittleFS.h>
#include <Preferences.h>

#define NVS_NAMESPACE "hivis"

struct DeviceConfig {
    // --- NVS (loaded via loadNVS, never in config.json) ---
    // Note: WiFi SSID/pass are owned by WiFiManager (espwifimgr namespace).
    // We do not store or read them manually.
    String mqttServer;    // MQTT broker address
    String mqttUser;      // Provisioned by server
    String mqttPass;      // Provisioned by server
    String deviceName;    // Human-readable, set via portal
    String deviceId;      // Assigned by server; local fallback is MAC-derived

    // --- From config.json ---
    int    mqttPort;
    String mqttTopicPrefix;
    int    mqttIntervalMs;
    int    mqttKeepaliveS;

    uint8_t bmeAddr;
    float   iaqWarn;
    float   iaqAlert;
    int     bsecSaveIntervalH;

    int    micWS, micSCK, micSD, micLR;
    double micCal;

    int   refreshMs;
    int   batteryPin;
    int   batteryMinMv;
    int   batteryMaxMv;
    float batteryMultiplier;

    int   otaCheckIntervalH;
    int   displayTimeoutMs;

    bool  buzzerEnabled;
    int   buzzerPin;

    int   buttonPin;
    int   longPressMs;
    int   doublePressMs;
};

inline String deriveDeviceId() {
    return "hivis-" + String((uint32_t)ESP.getEfuseMac(), HEX);
}

inline bool loadConfig(DeviceConfig &cfg) {
    cfg.mqttPort          = 8883;
    cfg.mqttTopicPrefix   = "hivis/sensors";
    cfg.mqttIntervalMs    = 3000;
    cfg.mqttKeepaliveS    = 60;
    cfg.bmeAddr           = 119;
    cfg.iaqWarn           = 100.0f;
    cfg.iaqAlert          = 200.0f;
    cfg.bsecSaveIntervalH = 6;
    cfg.micWS = 12; cfg.micSCK = 14; cfg.micSD = 26; cfg.micLR = 13;
    cfg.micCal            = 115.0;
    cfg.refreshMs         = 1000;
    cfg.batteryPin        = 36;
    cfg.batteryMinMv      = 330;   // units: centivolt (0.01V) — 330 = 3.30V
    cfg.batteryMaxMv      = 420;   // units: centivolt (0.01V) — 420 = 4.20V (1S LiPo)
    cfg.batteryMultiplier = 2.2f;  // voltage divider ratio (ADC sees V/2.2)
    cfg.otaCheckIntervalH = 24;
    cfg.displayTimeoutMs  = 10000;
    cfg.buzzerEnabled     = true;
    cfg.buzzerPin         = 25;
    cfg.buttonPin         = 4;
    cfg.longPressMs       = 2000;
    cfg.doublePressMs     = 400;

    if (!LittleFS.begin(true)) {
        Serial.println("Config: LittleFS mount failed.");
        return false;
    }

    File f = LittleFS.open("/config.json", "r");
    if (!f) {
        Serial.println("Config: config.json not found, using defaults.");
        return true;
    }

    JsonDocument doc;
    DeserializationError err = deserializeJson(doc, f);
    f.close();

    if (err != DeserializationError::Ok) {
        Serial.println("Config: parse error, using defaults.");
        return true;
    }

    cfg.mqttPort          = doc["mqtt"]["port"]                | cfg.mqttPort;
    cfg.mqttTopicPrefix   = doc["mqtt"]["topic_prefix"]        | cfg.mqttTopicPrefix;
    cfg.mqttIntervalMs    = doc["mqtt"]["interval_ms"]         | cfg.mqttIntervalMs;
    cfg.mqttKeepaliveS    = doc["mqtt"]["keepalive_s"]         | cfg.mqttKeepaliveS;

    cfg.bmeAddr           = doc["bme"]["addr"]                 | (int)cfg.bmeAddr;
    cfg.iaqWarn           = doc["bme"]["iaq_warn"]             | cfg.iaqWarn;
    cfg.iaqAlert          = doc["bme"]["iaq_alert"]            | cfg.iaqAlert;
    cfg.bsecSaveIntervalH = doc["bme"]["bsec_save_interval_h"] | cfg.bsecSaveIntervalH;

    cfg.micWS  = doc["mic"]["pin_ws"]  | cfg.micWS;
    cfg.micSCK = doc["mic"]["pin_sck"] | cfg.micSCK;
    cfg.micSD  = doc["mic"]["pin_sd"]  | cfg.micSD;
    cfg.micLR  = doc["mic"]["pin_lr"]  | cfg.micLR;
    cfg.micCal = doc["mic"]["cal"]     | cfg.micCal;

    cfg.refreshMs         = doc["misc"]["refresh_ms"]          | cfg.refreshMs;
    cfg.batteryPin        = doc["misc"]["battery_pin"]         | cfg.batteryPin;
    cfg.batteryMinMv      = doc["misc"]["battery_min_mv"]      | cfg.batteryMinMv;
    cfg.batteryMaxMv      = doc["misc"]["battery_max_mv"]      | cfg.batteryMaxMv;
    cfg.batteryMultiplier = doc["misc"]["battery_multiplier"]  | cfg.batteryMultiplier;

    cfg.otaCheckIntervalH = doc["ota"]["check_interval_h"]     | cfg.otaCheckIntervalH;
    cfg.displayTimeoutMs  = doc["display"]["timeout_ms"]       | cfg.displayTimeoutMs;
    cfg.buzzerEnabled     = doc["buzzer"]["enabled"]           | cfg.buzzerEnabled;
    cfg.buzzerPin         = doc["buzzer"]["pin"]               | cfg.buzzerPin;
    cfg.buttonPin         = doc["button"]["pin"]               | cfg.buttonPin;
    cfg.longPressMs       = doc["button"]["long_press_ms"]     | cfg.longPressMs;
    cfg.doublePressMs     = doc["button"]["double_press_ms"]   | cfg.doublePressMs;

    return true;
}
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

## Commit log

2026-03-16 Initial commit — HIVIS Monitor 2.0.1
    ESP32 indoor air quality monitor with BME688 (IAQ/CO2/VOC/Temp/Hum),
    INMP441 microphone, OLED display, MQTT TLS, auto-provisioning, OTA,
    offline buffering, and Grafana dashboards via InfluxDB/Node-RED.
    [partitions.csv]
2026-03-16 Fix MQTT auth-fail recovery: time-gate instead of count-gate
    Replace the per-loop-tick counter (hit threshold in ~10ms, causing
    constant re-provisioning boot loops) with a 5-minute elapsed-time
    check. Also extend post-registration broker-reload delay from 3s to 6s
    to give Mosquitto more time to reload passwd after SIGHUP.
    [main.cpp]
2026-03-17 Fix button polling, portal screen, offline fallback, debug WiFi
    - Move button->update() to top of loop() so it runs every 1ms (was
    inside 1s refresh tick — debounce swallowed all short presses)
    - Add DisplayModule::showPortal() to show captive portal instructions
    on screen (blocking WiFiManager call left display on splash forever)
    - Portal timeout now falls through to offline mode instead of rebooting
    - Add tryDebugWifi() with three hardcoded networks (SKYNET, iPoney,
    iPhone) tried automatically before launching the portal
    [main.cpp]
2026-03-19 Fix MQTT auth recovery state check and add button debug logging
    - Fix lastState() == -5 → == 5 (PubSubClient returns positive 5 for
    MQTT_CONNECT_UNAUTHORIZED; the wrong sign meant auth recovery never fired)
    - Add Serial BTN: prefix logs for all button events to aid debugging
    [main.cpp]
2026-03-26 Fix button becoming unresponsive after hours: MQTT reconnect now rate-limited
    _connectInternal() was called on every loop iteration when MQTT dropped,
    blocking 3-15s per call (3 retries × delay(1000) + TLS handshake). This
    made button->update() run so infrequently that short presses were missed.
    Fix: 5-second cooldown in loop() before each reconnect attempt; removed
    retry loop and delays from _connectInternal(). Also removed spurious
    _connectInternal() calls inside publish methods — loop() owns reconnection.
    Also: offline buffer now saves every 60s instead of every 3s, preventing
    runaway flash writes during long offline periods.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
    [MqttModule.cpp, main.cpp]
2026-03-26 Add KiCad hardware design files and Gerbers
    Includes schematic, PCB layout, custom footprint library, Gerber production
    files, and KiCad project backups for HIVIS Monitor 2.0.
    [hivis2-B_Cu.gbl, hivis2-B_Mask.gbs, hivis2-B_Paste.gbp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]
2026-03-26 Add Grafana timezone, fix InfluxDB datasource UID/token, refactor Node-RED flows
    - platformio.ini: fix comment prefix (semicolon)
    - docker-compose.yml: add TZ/GF_DEFAULT_TIMEZONE=America/Regina to Grafana
    - influxdb.yml: set real datasource UID and InfluxDB token
    - hivis_flows.json: refactor Build InfluxDB point and Extract system fields to
    use node-red-contrib-influxdb 0.7 + InfluxDB 2.0 [fieldsObj, tagsObj] format
    and fall back to MQTT topic for device_id
2026-03-27 Add SMD variant: schematic, Gerbers, BOM, and production files
    Updated KiCad project files with SMD components. New files:
    - hivis2smd.kicad_sch — SMD schematic
    - gerbers/smd/ — SMD Gerber set + zip
    - gerbers/hivistht.zip — THT Gerber zip
    - production/ — BOM, positions, netlist, and fabrication zip
    - hivis2smdBOM.csv, top/bottom position CSVs
    [bom.csv, designators.csv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]
2026-04-04 Add credentials gitignore, update hardware files
    - Exclude docs/credentials.md and server-backups/ from git
    - Update hardware KiCad project file
    - Swap backup zip for updated version
2026-04-08 Fix boot loop, LittleFS append, and WiFi IP race condition
    Boot loop (LoadProhibited crash):
    - BME688Module::begin() failed silently with no flag; update() then called
    _envSensor.run() on uninitialized BSEC2 → memcpy crash at 0xb58.
    Fix: added _ok flag, update() is now a no-op if begin() failed.
    WiFi 0.0.0.0:
    - tryConnectWifi() returned on WL_CONNECTED before DHCP assigned IP.
    Fix: also wait for localIP != 0.0.0.0.
    LittleFS append on new file:
    - LittleFS on ESP32 Arduino does not create files in "a" mode.
    Fix: OfflineBuffer::store() uses "w" for new files, "a" for existing.
    LittleFS log noise:
    - count() called exists() then open("r"), producing VFS error when
    filesystem had a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
    [BME688Module.cpp, OfflineBuffer.cpp, main.cpp]
2026-04-08 Firmware hardening: CRC state, auth counter, debug WiFi guard, robustness fixes
    BSEC state CRC32 (BME688Module):
    - saveState() appends ESP32 ROM CRC32 of the blob after writing
    - loadState() verifies CRC before calling setState(); deletes corrupt file
    - Both load/save now log failures explicitly instead of silently ignoring
    MQTT auth-fail reboot counter (ConfigHandler.h + main.cpp):
    - NVS key 'auth_rbt_cnt' tracks consecutive auth-fail reboots
    - Capped at 5: after limit, device stays online and instructs user to
    long-press to reconfigure instead of rebooting indefinitely
    - Counter cleared on every successful MQTT connection
    Debug WiFi guard (main.cpp + platformio.ini):
    - Hardcoded SSID/p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
    [BME688Module.cpp, ConfigHandler.h, OfflineBuffer.cpp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]
2026-04-13 Deploy public website, harden docs, scrub credentials from repo
    - Add Nginx + Let's Encrypt website (https://hvht.net) to docker-compose,
    nginx configs (hivis.conf http2 directive fix), and deployment script
    - Update system-overview and operations manual: add Nginx/certbot to
    architecture diagram and service table, add public website section,
    update container count 5→7, add FC-7 Nginx/SSL check, add Mosquitto
    passwd permission fix to troubleshooting table
    - Security: remove all plaintext passwords (hivishitech2026) and tokens
    from committed files — replaced with REPLACE_WITH_* placeholders;
    admin InfluxDB token removed from Grafana provisioning datasource;
    all secrets redir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
    [OfflineBuffer.cpp, main.cpp]
2026-04-13 Fix battery not updating when charging, bump to v2.0.2
    The hysteresis filter in readBattery() only updated on drops (prc <= lastBatPrc - 2),
    ignoring all upward movement. Changed to abs(prc - lastBatPrc) >= 2 so both
    charging and discharging are reflected while still filtering 1% ADC noise.
    [main.cpp]
2026-04-13 Suppress VFS log noise and add BSEC state exists() guard
    - Add CORE_DEBUG_LEVEL=0 build flag to silence Arduino framework
    log_e() macros (vfs_api open() errors on non-existent files)
    - Add LittleFS.exists() guard in BME688Module::loadState() before
    attempting to open bsec_state.bin
    Both changes are cosmetic — boot log is now clean on first run.
    [BME688Module.cpp]
2026-04-15 Add hamburger nav menu for mobile on all three pages
    - index.html, about.html, build.html: hide nav links at ≤640px,
    show animated hamburger button (3-bar → X on open)
    - Dropdown opens below the fixed nav bar with blur backdrop
    - Closes on outside tap; aria-expanded kept in sync for accessibility
2026-04-15 Fix hamburger CSS cascade and breakpoint on all pages
    index.html: hamburger base styles (display:none) were placed AFTER the
    768px media query, overriding display:flex via cascade. Moved base styles
    before the media query so the media query correctly wins at ≤768px.
    about.html, build.html: widened breakpoint from 640px → 768px to match
    all standard phone widths.
2026-04-16 Fix two live security vulnerabilities and remove PII from website
    Security fixes:
    - Remove hardcoded InfluxDB token from client-side HTML; rotate the
    exposed token. nginx now injects the token server-side via
    proxy_set_header using an environment variable (hivis.conf.template).
    dev-server.py reads INFLUX_TOKEN from env instead of forwarding the
    browser's Authorization header.
    - Add mandatory X-Provision-Token authentication to the /provision
    endpoint. Without a matching PROVISION_SECRET env var the server
    returns 401. Node-RED flow updated to send the header automatically.
    Website:
    - Remove Saskatchewan Polytechnic email from About page contact section
    - Remove mqtt.hvht.net hos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
2026-04-27 Add README, fix button GPIO default to 4, update docs
    - Add README.md with architecture, GPIO map, firmware/server quickstart
    - Fix button pin default from GPIO 0 to GPIO 4 in ConfigHandler.h
    - Update operations-manual.md and system-overview.md to reflect GPIO 4
    (QC-5, FC-3, quick-reference table, hardware pin table)
    - Fix OTA expected version in FC-8: 2.0.1 → 2.0.2
    - Extend .gitignore: KiCad autosaves, lock files, backup ZIPs, Word docs
    [ConfigHandler.h]
2026-04-27 Scrub sensitive content and remove stale files for public release
    - Remove hardcoded WiFi credentials and DEBUG_WIFI block from main.cpp
    - Remove -D DEBUG_WIFI flag from platformio.ini
    - Replace bootstrap MQTT password with CHANGE_ME placeholder
    - Replace internal IPs (172.16.1.156, 100.120.194.59, 192.168.100.1)
    with <SERVER_IP>, <TAILSCALE_IP>, <ROUTER_IP> across all docs
    - Fix dev-server.py: read INFLUX_HOST from env var instead of hardcoding
    - Remove stale include/ headers (duplicates of src/, unused by build)
    - Remove hardware/hivis2-backups/ and production/backups/ from tracking
    [ConfigHandler.h, main.cpp]
2026-05-04 Unify all pages to index.html design system
    Switch about, build, and results pages to match the index.html visual
    language: dark blue gradient background, system sans-serif font,
    glassmorphism cards (backdrop-filter, 12px radius), sticky amber-bordered
    header, institution footer with sask-poly logo. Hamburger toggle updated
    from nav.open to header.open across all pages.
2026-05-04 Add live device indicator to all inner page navbars
    Matches index.html: pulsing dot + "N devices online" text queried from InfluxDB on page load. Includes CSS animations and self-contained fetch script.
2026-05-04 Remove unloaded Syne font references from results.html
    All font-family: "Syne" declarations stripped — page now inherits system
    sans-serif from body, matching index.html typography exactly.
2026-05-04 Fix device provisioning: replace fetch with HTTP request node, add token header
    fetch() in Node-RED sandbox crashes with "process is not defined". Replace with
    a 2-output function: output 1 sends MQTT retain message, output 2 triggers an
    HTTP request node that POSTs to the OTA server with the required X-Provision-Token
    header. Devices can now auto-provision and connect with full 12-digit MAC IDs.
